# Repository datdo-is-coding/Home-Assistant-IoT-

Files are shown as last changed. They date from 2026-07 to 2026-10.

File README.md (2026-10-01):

# SIC — Home Assistant IoT

Code đang phát triển tập trung vào ba thành phần:

| Thư mục | Vai trò |
| --- | --- |
| `Gateway/` | Gateway Python, MQTT, xử lý giọng nói và Web UI |
| `Firmware/firmware_esp/ActionBox/` | Firmware thiết bị chấp hành ESP32-S3 |
| `Firmware/firmware_esp/SubBox/` | Firmware điều phối phòng, audio và NLU |

Các thư mục hỗ trợ được giữ lại:

- `MQTT_Server/`: broker Mosquitto và bộ dịch vụ Docker hiện có.
- `Firmware/firmware_esp/Audio_Hardware_Test/`: firmware kiểm tra phần cứng âm thanh.
- `Firmware/tools/` và các script test/visualizer: công cụ kiểm tra thiết bị.
- `Gateway/tests/`, `Gateway/benchmark/`, `Gateway/training_data/`: kiểm thử, đo hiệu năng và dữ liệu NLU.
- `Hardware/`, `sound/`, `apk/`, các firmware binary và tài liệu thiết kế: giữ nguyên.
- `archive/`: code cũ, có [bảng đường dẫn khôi phục](archive/README.md).

## Build firmware

Trên Windows có ESP-IDF 6.0.2, chạy từ thư mục gốc repo:

```powershell
.\Firmware\firmware_esp\ActionBox\build.ps1
.\Firmware\firmware_esp\SubBox\build.ps1
```

Script dùng profile `C:\Espressif\tools\Microsoft.v6.0.2.PowerShell_profile.ps1`.
Tham số `-Clean` thực hiện `fullclean` trước khi build. Các script build/flash
truyền đường dẫn project bằng `-C`, nên không phụ thuộc thư mục terminal hiện tại.
Nếu chạy trong terminal thiếu biến kiến trúc CPU và gặp lỗi `Windows-`, đặt biến
cho phiên terminal trước khi build:

```powershell
$env:PROCESSOR_ARCHITECTURE = [System.Runtime.InteropServices.RuntimeInformation]::OSArchitecture.ToString().Replace('X64', 'AMD64')
```

Nạp firmware khi đã chọn đúng board và cổng COM:

```powershell
.\Firmware\firmware_esp\ActionBox\flash.ps1 -Port COM9 -NoMonitor
.\Firmware\firmware_esp\SubBox\flash.ps1 -Port COM10 -NoMonitor
```

## Gateway

```powershell
python -m pip install -r Gateway/requirements.txt
python Gateway/gateway/main.py
```

Cấu hình nằm trong `Gateway/gateway/config.py`; dịch vụ Linux nằm trong
`Gateway/systemd/`. ASR/TTS local cần model và dependency riêng theo cấu hình.

Kiểm thử offline từ thư mục gốc, không điều khiển thiết bị thật:

```powershell
python Gateway/tests/test_intent_engine_v3.py
python Gateway/tests/test_runtime_utils.py
```

`test_clean_gateway.py` là script tích hợp có khởi tạo Gateway/registry, không nằm
trong bộ test offline trên. Chỉ chạy với cấu hình và dữ liệu thử nghiệm riêng.

## Tìm kiếm code

`.ignore` loại code archive và thư viện bên thứ ba khỏi tìm kiếm `rg` mặc định;
dùng `rg --no-ignore` khi cần tra cứu chúng. `.graphifyignore` giữ graph tập trung
vào code hiện hành. Các file archive vẫn có thể được quản lý bằng Git.

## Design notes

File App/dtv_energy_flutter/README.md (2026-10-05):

# SIC Home for Android

Flutter client for the Gateway in this repository. Includes account/API-key
login, room filters, favorites, relay control, telemetry/history, device pairing
and firmware management. Admin actions remain subject to Gateway authorization.
No simulated telemetry or local account registration is used.

## Connect

1. Connect the phone to the same trusted network as the Gateway.
2. Enter a reachable Gateway URL, normally `http://<gateway-ip>:8000`.
3. Sign in with an existing Gateway account or its API key.

The Pi at `192.168.11.29` was listening on **127.0.0.1:8000** when inspected on
2026-10-02. It is not yet reachable directly from a phone. Configure an
authenticated HTTPS reverse proxy, or deliberately enable LAN binding with
the Gateway's authentication and firewall intact. Do not expose port 8000 to
the public Internet. HTTP is supported for trusted LAN use, but does not encrypt
credentials in transit. Android session tokens are encrypted with AndroidKeyStore;
passwords are not saved and app backup is disabled.

Deploy the matching `Gateway/gateway/web_server.py` relay fix before testing
physical controls: the old handler misread the verifier's tuple result. The app
distinguishes a relay acknowledgement from verified electrical load. Offline
devices and unknown relay states cannot be toggled.

## Build And Verify

Use Flutter 3.44.8 / Dart 3.12.2, JDK 17 and Android SDK 36 (the versions verified
for this change):

```sh
flutter pub get
flutter analyze
flutter test
flutter build apk --debug
```

APK: `build/app/outputs/flutter-apk/app-debug.apk`.
This is a development build, not a production-signed Play Store release.
The repository's existing Gradle release configuration also uses the debug key;
configure your own signing key before distribution.

Widget tests exercise 360/390 px phone and 800 px tablet layouts, light/dark mode,
large text and offline controls. Screenshot baselines are in `test/goldens/`.
HTTP tests mock Gateway responses; no Android phone, AndroidKeyStore hardware,
real relay switching or firmware flashing was exercised by these tests.

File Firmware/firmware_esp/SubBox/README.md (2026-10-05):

# SubBox / SubGateway Firmware

## Current voice mode: Pi4 processing only

ActionBox captures 16 kHz mono PCM and sends it over ESP-NOW. SubBox forwards
the PCM over WebSocket with the originating ActionBox `node_id`,
`audio_relay: true`, and `asr_only: false`. Pi4 performs speech recognition,
intent extraction and device selection, then sends commands through
MQTT -> SubBox -> ActionBox. Audio sockets are not relay-command transports.

Local DummyASR/offline fallback and the SubBox voice NLU task are disabled.
Gateway transcripts are diagnostic only: they never trigger a second local
command. If the audio connection fails, no fallback command is generated.
ActionBox keeps energy VAD and push-to-talk for recording boundaries, with
WakeNet disabled; saying "Hi ESP" is no longer required.

Deploy the updated `Gateway/gateway/audio_server.py` and restart the Gateway,
then build/flash both ActionBox and SubBox. The WebSocket URI must point to the
Pi audio server (port 8765); the existing security configuration overrides the
default URI in `src/config/subbox_config.h`.

Offline checks from the repository root:

```sh
python3 -m unittest discover -s Gateway/tests -p test_audio_relay.py -v
python3 -m unittest discover -s Firmware/tests -p test_audio_relay.py -v
```

The older local-ASR/NLU architecture described below is historical and is not
the active microphone path.

Production-grade firmware for the **ESP32-S3 SubBox (SubGateway)** — the intelligent local room brain and distributed audio hub of the smart-home IoT ecosystem, built on **ESP-IDF 6.0.2** and **FreeRTOS** (PlatformIO compatible).

---

## 1. System Role & Architecture

```
ActionBox 1 (Mic, Spk, Relay, Current) ──┐
ActionBox 2 (Mic, Spk, Relay, Current) ──┤ UDP Audio:5005   ┌──────────────────────────────────────────────┐
ActionBox 3 (Mic, Spk, Relay, Current) ──┼─────────────────>│                   SubBox                     │
ActionBox 4 (Mic, Spk, Relay, Current) ──┘                  │                                              │
                                                            │ • Audio Manager (RMS & VAD arbitration)      │
ActionBox 1..4 Speakers <───────────────────────────────────┤ • Single-Stream ASR Pipeline (Replaceable)   │
                          UDP Audio:5006 (Targeted Downlink)│ • Vietnamese Text Normalizer                 │
                                                            │ • Local Deterministic NLU (Intent & Entity)  │
                                                            │ • Dialogue Context Manager ("tắt nó")       │
                                                            │ • Local Command Router & Rule Engine         │
                                                            │ • ActionBox State Registry                   │
                                                            └──────────────────────┬───────────────────────┘
                                                                                   │ MQTT (home/subbox/...)
                                                                                   ▼
                                                                        Raspberry Pi 4 / Cloud
                                                                  (Complex reasoning, LLM, historical)
```

### Key Architectural Tenets:
1. **No Direct Microphone on SubBox**: SubBox does **NOT** initialize an onboard I2S microphone driver. All audio input originates from ActionBox microphones transmitted over the network (UDP / ESP-NOW).
2. **Multi-ActionBox Arbitration**: Supports up to 4 ActionBoxes per room. Instead of running 4 concurrent ASR engines (which would overwhelm memory/compute), the **Audio Manager** tracks packet loss, RMS energy, and VAD state to dynamically route the single *best* active stream to the ASR engine.
3. **Targeted Voice Response**: Audio feedback / TTS is routed specifically to the ActionBox where the user spoke (`last_input_audio_node`), avoiding whole-room audio chaos.
4. **Local Independence**: Basic voice commands ("bật đèn", "tắt quạt", "nhiệt độ bao nhiêu") and local protection rules (overcurrent trips, automatic fan cooling) execute locally on SubBox without Raspberry Pi 4.
5. **Complex Intent Forwarding**: Multi-condition, temporal, or cross-room whole-house logic ("nếu nhiệt độ trên 30 độ thì bật quạt") is detected and forwarded to Raspberry Pi 4 via MQTT.

---

## 2. Directory Structure (Section 26 Compliance)

```
SubBox/
├── platformio.ini               # PlatformIO 16MB Flash + PSRAM environment
├── CMakeLists.txt               # ESP-IDF 6.0.2 / 5.5 top-level project CMake
├── partitions.csv               # 16MB partition map (NVS, OTA0/1, Model, Storage)
├── sdkconfig.defaults           # 240MHz, 16MB Flash DIO, 16MB Octal PSRAM
├── build.ps1                    # One-click native ESP-IDF build script
├── flash.ps1                    # One-click flash & monitor script
└── src/
    ├── main.cpp                 # Firmware entry point & subsystem assembly
    ├── CMakeLists.txt           # Component registration & dependencies
    │
    ├── config/
    │   ├── subbox_config.h      # Network ports, buffer sizes, FreeRTOS priorities
    │   └── board_pins.h         # GPIO definitions (LEDs, buttons, relays; NO MIC)
    │
    ├── audio/
    │   ├── audio_transport/     # Abstract transport + UDP implementation
    │   │   ├── audio_packet.h   # Universal audio protocol packet struct
    │   │   ├── audio_transport.h
    │   │   └── udp_audio_transport.h / .cpp
    │   ├── audio_buffer/        # Circular audio ring buffer (PSRAM supported)
    │   │   └── audio_ring_buffer.h / .cpp
    │   ├── vad/                 # Adaptive energy-based Voice Activity Detection
    │   │   ├── vad_interface.h
    │   │   └── energy_vad.h / .cpp
    │   ├── asr/                 # Replaceable Vietnamese ASR abstraction + DummyASR
    │   │   ├── asr_engine.h
    │   │   └── dummy_asr.h / .cpp
    │   ├── audio_manager/       # Multi-stream arbitrator & ASR feeder
    │   │   └── audio_manager.h / .cpp
    │   └── audio_output/        # Targeted downlink router to ActionBox speakers
    │       └── audio_output_router.h / .cpp
    │
    ├── nlu/
    │   ├── normalizer/          # Vietnamese diacritics & text cleaner
    │   │   └── vietnamese_normalizer.h / .cpp
    │   ├── intent/              # Deterministic intent parser & complex detector
    │   │   ├── intent_types.h
    │   │   └── intent_parser.h / .cpp
    │   ├── entity/              # Device, Room, Value extraction
    │   │   ├── entity_types.h
    │   │   └── entity_extractor.h / .cpp
    │   └── context/             # Speaker vs Target room, pronoun resolution ("nó")
    │       └── context_manager.h / .cpp
    │
    ├── actionbox/
    │   ├── registry/            # ActionBox node status, capabilities & telemetry
    │   │   └── actionbox_registry.h / .cpp
    │   ├── protocol/            # JSON command serializer
    │   │   └── actionbox_network_protocol.h
    │   └── router/              # Command execution (Local, Cross-Room, Pi4)
    │       └── command_router.h / .cpp
    │
    ├── room/                    # Local room identity & configuration
    │   └── room_manager.h / .cpp
    ├── rules/                   # Edge rule engine (overcurrent, thermal thresholds)
    │   └── rule_engine.h / .cpp
    ├── tts/                     # TTS interface, chime generator & Pi4 audio relay
    │   ├── tts_engine.h
    │   └── tts_manager.h / .cpp
    ├── mqtt/                    # ESP-IDF MQTT client for Pi4 integration
    │   └── mqtt_client.h / .cpp
    ├── storage/                 # NVS persistent configuration
    │   └── nvs_manager.h / .cpp
    └── system/                  # FreeRTOS Task Manager & Interactive Dev Console
        ├── task_manager.h / .cpp
        └── dev_console.h / .cpp
```

---

## 3. Audio & Data Pipeline

```
 [ActionBox Mic]
       │ (16kHz, 16-bit Mono PCM, 20ms frames)
       ▼ UDP:5005
 [audio_rx_task]
       │
       ▼
 [audio_mgr_task] ──> [energy_vad per node] ──> Best Source Selection
       │
       ▼ (Active Speech Frames)
 [asr_task] ──> ASREngine (DummyASR / TinyML Vietnamese ASR)
       │
       ▼ (Recognized Vietnamese Text)
 [nlu_task]
       ├── Vietnamese Normalizer (lowercase, tone marks, synonym collapse)
       ├── Intent Parser (TURN_ON, TURN_OFF, TOGGLE, SET_TEMPERATURE, COMPLEX)
       ├── Entity Extractor (Device: LIGHT, FAN; Room: BEDROOM; Values: 26°C)
       └── Context Manager (Speaker Room vs Target Room; pronoun "nó" resolution)
       │
       ▼
 [cmd_router_task]
       ├── Local Room ActionBox? ─────────> Dispatch UDP command to ActionBox relay
       ├── Other Room SubBox?    ─────────> Dispatch via Inter-SubBox MQTT
       └── Complex Sentence?     ─────────> Forward to Pi4 (`home/subbox/ID/voice/request`)
       │
       ▼
 [tts_manager] ──> Audio Output Router ──> UDP:5006 ──> [Target ActionBox Speaker]
```

---

## 4. FreeRTOS Task & Core Architecture

| Task Name | Core | Priority | Stack (Bytes) | Role |
| :--- | :---: | :---: | :---: | :--- |
| `audio_rx_task` | 1 | 9 | 4,096 | High-speed UDP receiver for incoming microphone packets |
| `audio_mgr_task`| 1 | 8 | 4,096 | Multi-stream tracking, VAD processing, arbitrator |
| `vad_task` | 1 | 7 | 4,096 | Frame-level energy calculation & onset/offset tracking |
| `asr_task` | 1 | 6 | 8,192 | Speech-to-text inference (INT8 PSRAM model or Dummy) |
| `nlu_task` | 0 | 5 | 6,144 | UTF-8 normalization, intent parsing, entity/context resolution |
| `cmd_router_task`| 0 | 5 | 4,096 | Command routing, safety check, rule evaluation |
| `audio_tx_task` | 1 | 8 | 4,096 | Transmits audio feedback/chimes to target ActionBox speaker |
| `mqtt_task` | 0 | 4 | 6,144 | Bi-directional communication with Raspberry Pi 4 |
| `telemetry_task`| 0 | 2 | 3,072 | Node heartbeat, registry health & current watchdog |
| `dev_cli_task`  | 0 | 3 | 4,096 | UART/USB-JTAG interactive development console |

---

## 5. Development Console (CLI)

The firmware includes an interactive CLI over Native USB Serial / UART at 115200 baud for testing the complete pipeline without hardware audio:

### Commands:

1. **`CMD <text>`**: Directly injects a command into the NLU pipeline:
   ```bash
   CMD bật đèn phòng ngủ
   CMD tắt quạt
   CMD tắt nó
   CMD nếu nhiệt độ trên 30 độ thì bật quạt
   ```
2. **`SAY <text>`**: Simulates an ASR recognition event:
   ```bash
   SAY bật đèn
   SAY tăng nhiệt độ điều hòa phòng khách
   ```
3. **`TEST_NLU`**: Executes the comprehensive built-in unit test suite verifying:
   - Simple local commands (`bật đèn` -> local room light ON)
   - Cross-room commands (`bật đèn phòng bếp` -> kitchen light ON)
   - Device aliases (`máy lạnh` -> `AIR_CONDITIONER`)
   - Context reference resolution (`tắt nó` after `bật quạt` -> turn off fan)
   - Complex conditional sentences (`nếu trời mưa...` -> forwarded to Pi4)
4. **`STATUS`**: Dumps system uptime, free internal RAM, free PSRAM, Wi-Fi status, and registered ActionBoxes.
5. **`REG <id> <room> <device>`**: Manually registers an ActionBox for test routing:
   ```bash
   REG AB001 BEDROOM LIGHT
   ```
6. **`TOPIC <payload>`**: Publishes an event to Pi4 MQTT broker.

---

## 6. MQTT Topics (Raspberry Pi 4 Integration)

| Topic | Direction | Payload Example / Description |
| :--- | :---: | :--- |
| `home/subbox/{id}/state` | SubBox $\rightarrow$ Pi4 | `{"status":"online","room":"BEDROOM","free_heap":...}` |
| `home/subbox/{id}/event` | SubBox $\rightarrow$ Pi4 | `{"event":"overcurrent_trip","node":"AB001","current":16.2}` |
| `home/subbox/{id}/command` | Pi4 $\rightarrow$ SubBox | External commands issued by Home Assistant or Pi4 |
| `home/subbox/{id}/voice/request` | SubBox $\rightarrow$ Pi4 | Forwarded complex intents requiring LLM / reasoning |
| `home/subbox/{id}/voice/response` | Pi4 $\rightarrow$ SubBox | Pi4 response text / synthesized TTS audio metadata |

---

## 7. Build and Flash Instructions

### Prerequisites:
- **ESP-IDF v6.0.2** or **ESP-IDF v5.5** installed.
- Target hardware: ESP32-S3 (WROOM-1 / WROOM-2 N16R8 / N16R2).

### Option A: Using PowerShell Scripts (ESP-IDF 6.0.2)
```powershell
cd Firmware/firmware_esp/SubBox

# 1. Clean & Build
.\build.ps1 -Clean

# 2. Flash to COM port & open Monitor (default COM9)
.\flash.ps1 -Port COM9
```

### Option B: Using Native ESP-IDF CLI
```bash
idf.py set-target esp32s3
idf.py build
idf.py -p COM9 flash monitor
```

### Option C: Using PlatformIO
```bash
pio run -e esp32s3_subbox
pio run -e esp32s3_subbox -t upload --upload-port COM9
pio device monitor -b 115200
```

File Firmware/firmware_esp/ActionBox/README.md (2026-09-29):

# ActionBox Firmware — ESP32-S3 Smart-Home Actuator Node

Production-grade embedded C++ firmware for the **ActionBox** actuator node running on ESP32-S3, ESP-IDF 6.0.2 / FreeRTOS, and PlatformIO.

---

## 1. Hardware Role & Philosophy

The ActionBox is a low-level, high-reliability actuator and sensor node.

* **It is NOT an AI device.**
* **It does NOT run an LLM.**
* **It does NOT perform speech recognition or audio capture.**
* **It does NOT interpret natural language or execute high-level automations.**

### Primary Responsibilities:
1. **Relay Control**: Safely drives 2 isolated relay channels (monostable or magnetic-latching).
2. **Current & Power Sensing**: Interrogates dual Belling BL0942 energy measurement ICs over UART.
3. **Physical Buttons**: Debounces local push buttons with short-press toggle and long-press reset.
4. **State Reporting & Idempotency**: Reports channel states and telemetries via a cached idempotent JSON protocol.
5. **Safety Supervisor**: Autonomous, local overcurrent cutoff and fault isolation without network dependency.
6. **Robust Network Resilience**: Communicates primarily with its assigned SubBox over ESP-NOW, continuing 100% full local operation when network or SubBox is offline.

---

## 2. Hardware Pinout (`IoT_Board.kicad_sch`)

Directly traced from schematic `D:\Downloads\IoT_Board.kicad_sch`:

| Function | Schematic Net | ESP32-S3 GPIO | Electrical Interface | Description |
| :--- | :--- | :--- | :--- | :--- |
| **Relay Channel 1** | `RL1` | **GPIO 4** | Optocoupler PC817 (U5) | Relay 1 (K1) drive |
| **Relay Channel 2** | `RL2` | **GPIO 5** | Optocoupler PC817 (U6) | Relay 2 (K2) drive |
| **Button Channel 1**| `BUT1` | **GPIO 1** | Internal Pull-Up to 3.3V | Local Push Button 1 |
| **Button Channel 2**| `BUT2` | **GPIO 3** | Internal Pull-Up to 3.3V | Local Push Button 2 |
| **Status LED 1** | `LED1` | **GPIO 48** | Series Resistor to GND | Channel 1 Indicator LED |
| **Status LED 2** | `LED2` | **GPIO 47** | Series Resistor to GND | Channel 2 Indicator LED |
| **BL0942 TX** | `BL_TX` | **GPIO 9** | UART TX (Shared) | Broadcast query to BL0942 #1 & #2 |
| **BL0942 RX Ch1** | `BL_RX1` | **GPIO 10** | UART1 RX | Ch1 BL0942 (#1) Response Stream |
| **BL0942 RX Ch2** | `BL_RX2` | **GPIO 11** | UART2 RX | Ch2 BL0942 (#2) Response Stream |
| **Speaker SD (Mute)**| `SP_SD` | **GPIO 2** | Hardware Shutdown Pin | **Cố định mức LOW** -> Tắt hẳn IC MAX98357 |
| **Speaker I2S (BCLK/LRC/DOUT)**| `SP_*` | **GPIO 17, 18, 21**| I2S Tri-state Pull-down | Chân âm thanh đặt ở trạng thái cô lập, tiêu thụ 0W |
| **USB D-** | `USB_D-` | **GPIO 19** | Native USB | USB Serial / JTAG Console |
| **USB D+** | `USB_D+` | **GPIO 20** | Native USB | USB Serial / JTAG Console |
| **Debug TX0** | `TX0` | **GPIO 43** | UART0 TX | Hardware Debug Terminal |
| **Debug RX0** | `RX0` | **GPIO 44** | UART0 RX | Hardware Debug Terminal |

---

## 3. Project Architecture

```
ActionBox/
├── platformio.ini                 # PlatformIO configuration (esp32-s3-devkitc-1, 16MB)
├── CMakeLists.txt                 # ESP-IDF Root Project CMake
├── partitions.csv                 # 16MB Partition Table (nvs, otadata, ota_0, ota_1)
├── sdkconfig.defaults             # Hardware configuration defaults
├── src/
│   ├── CMakeLists.txt             # Component registration & dependency mapping
│   ├── main.cpp                   # Application entry point & banner
│   ├── config/
│   │   ├── board_pins.h           # Hardware GPIO mapping from schematic
│   │   └── app_config.h           # Timing, limits, queue capacities & task priorities
│   ├── drivers/
│   │   ├── relay/
│   │   │   ├── relay_driver.h     # Relay driver interface (monostable & latching)
│   │   │   └── relay_driver.cpp   # Staggered inrush delay & thread-safe actuation
│   │   ├── current_sensor/
│   │   │   ├── current_sensor.h   # Abstract current measurement interface
│   │   │   ├── bl0942.h           # BL0942 driver header
│   │   │   └── bl0942.cpp         # Dual-UART BL0942 parsing & calibration
│   │   ├── button/
│   │   │   ├── button_driver.h    # Button driver header
│   │   │   └── button_driver.cpp  # Non-blocking debounce & long-press detection
│   │   └── led/
│   │       ├── led_driver.h       # Status LED pattern header
│   │       └── led_driver.cpp     # Visual pattern generator (steady, blink, pulse)
│   ├── protocol/
│   │   ├── actionbox_protocol.h   # JSON schema, commands & responses
│   │   └── actionbox_protocol.cpp # cJSON parsing & 32-entry idempotency cache
│   ├── network/
│   │   ├── espnow_transport.h     # ESP-NOW transport header
│   │   └── espnow_transport.cpp   # Station Wi-Fi & unicast/broadcast transport
│   ├── device/
│   │   ├── device_manager.h       # Coordinator header
│   │   └── device_manager.cpp     # Command dispatch, button events & LED sync
│   ├── safety/
│   │   ├── safety_supervisor.h    # Safety supervisor header
│   │   └── safety_supervisor.cpp  # Local overcurrent trip & TWDT watchdog
│   ├── storage/
│   │   ├── nvs_storage.h          # NVS persistent configuration header
│   │   └── nvs_storage.cpp        # Flash-wear-protected NVS storage
│   └── system/
│       ├── task_manager.h         # FreeRTOS task & queue definitions
│       └── task_manager.cpp       # Core task loops & queue orchestration
└── tools/
    └── test_actionbox.py          # Python test CLI & automated verification suite
```

---

## 4. FreeRTOS Task Architecture

The ActionBox organizes its concurrency into discrete FreeRTOS tasks communicating via queues and semaphores:

| Task Name | Priority | Stack | Function |
| :--- | :--- | :--- | :--- |
| `safety_task` | `MAX-1` (Highest) | 4 KB | Blocks on sensor queue. Evaluates overcurrent limits instantly; trips relays and dispatches urgent alerts. Feeds TWDT. |
| `relay_task` | `MAX-2` | 4 KB | Consumes command queue; manages inrush stagger delay and coil pulse timing. |
| `button_task` | `MAX-3` | 3 KB | Ticks button state machine every 10ms for non-blocking debounce and long-press gestures. |
| `sensor_task` | `MAX-4` | 4 KB | Interrogates dual BL0942 UART channels every 100ms; posts valid measurements to `sensor_queue`. |
| `network_task`| `MAX-5` | 5 KB | Processes incoming ESP-NOW packets from SubBox, validates idempotency cache, dispatches commands, and sends responses. |
| `telemetry_task`| `IDLE+2` | 3 KB | Broadcasts periodic JSON telemetry every 1000ms; monitors SubBox heartbeat timeout; ticks LED animations. |

---

## 5. Relay Control & Magnetic Latching

* **Monostable Mode** (`BOARD_RELAY_DRIVE_TYPE == BOARD_RELAY_TYPE_MONOSTABLE`):
  * Continuous HIGH energizes optocoupler (Relay Closed/ON).
  * Continuous LOW de-energizes optocoupler (Relay Open/OFF).
* **Magnetic Latching Mode** (`BOARD_RELAY_DRIVE_TYPE == BOARD_RELAY_TYPE_LATCHING_DUAL`):
  * `SET` pulse (50ms) closes contact, then releases coil to 0 immediately.
  * `RESET` pulse (50ms) opens contact, then releases coil to 0 immediately.
  * **Never holds coil continuously energized**, eliminating thermal dissipation and saving power.

---

## 6. Safety & Overcurrent Protection

* **Autonomous Protection**: Runs locally in `safety_task`. Does **not** rely on SubBox, Wi-Fi, or Raspberry Pi.
* **Overcurrent Trip**:
  * Default threshold: `10000 mA` (10A RMS).
  * Inrush Debounce: Must persist > `300 ms` to prevent false tripping on capacitive/motor inrush.
  * Hard Ceiling Trip: Instantaneous cutoff if current exceeds `16000 mA` (16A).
* **Post-Trip Isolation**:
  * Relay is forced OFF immediately.
  * Channel is locked in `RELAY_FAULT_OVERCURRENT`.
  * Status LED blinks rapidly (5 Hz).
  * Urgent alert packet is sent to SubBox.
  * **No automatic re-engagement** is permitted until an explicit `CLEAR_FAULT` command is issued.

---

## 7. Communication Protocol

### Command Format (SubBox -> ActionBox)
```json
{
  "version": 1,
  "node_id": "AB001",
  "request_id": 1042,
  "cmd": "TURN_ON",
  "channel": 1,
  "timestamp": 1727400000
}
```

### Response Format (ActionBox -> SubBox)
```json
{
  "version": 1,
  "node_id": "AB001",
  "request_id": 1042,
  "status": "OK",
  "channel": 1,
  "state": "ON",
  "uptime_s": 42
}
```

### Supported Commands
* `TURN_ON`: Turn on relay for specified channel (1 or 2).
* `TURN_OFF`: Turn off relay for specified channel.
* `TOGGLE`: Toggle relay state.
* `GET_STATE`: Query relay contact and fault state.
* `GET_CURRENT`: Query instantaneous RMS current and voltage from BL0942.
* `GET_POWER`: Query active power (W) and accumulated energy (Wh).
* `CLEAR_FAULT`: Clears an active safety fault and re-enables channel control.
* `PING`: Heartbeat probe (replies with `state: "PONG"`).
* `SET_CONFIG`: Remotely update `node_id`, `room_id`, or `max_current_ma`.

### Idempotency
A 32-entry ring buffer tracks recent `request_id`s and their exact serialized response. If the SubBox re-transmits a command due to packet loss, the ActionBox returns the cached response without re-triggering relays or double-toggling.

---

## 8. Build, Flash & Monitor Instructions

### Option A: Using ESP-IDF 6.0.2 (Native PowerShell)

Activate the ESP-IDF 6.0.2 environment:
```powershell
& 'C:\Espressif\tools\Microsoft.v6.0.2.PowerShell_profile.ps1'
```

Navigate to the project root:
```powershell
cd d:\Home-Assistant-IoT-\Firmware\firmware_esp\ActionBox
```

Build:
```powershell
idf.py build
```

Flash (e.g. on `COM8`):
```powershell
idf.py -p COM8 flash
```

Monitor:
```powershell
idf.py -p COM8 monitor
```

*(Or simply use the included one-click helper scripts `./build.ps1` and `./flash.ps1`)*

### Option B: Using PlatformIO

Build:
```bash
pio run
```

Upload:
```bash
pio run --target upload --upload-port COM8
```

Monitor:
```bash
pio device monitor --port COM8 --baud 115200
```

---

## 9. Testing & Automated Verification

A complete Python test suite is provided in `tools/test_actionbox.py`.

Run the automated verification suite over Serial:
```bash
python tools/test_actionbox.py --port COM8 --test
```

Send individual commands:
```bash
# Toggle Relay 1
python tools/test_actionbox.py --port COM8 --cmd TOGGLE --ch 1

# Query Current
python tools/test_actionbox.py --port COM8 --cmd GET_CURRENT --ch 1

# Clear Fault
python tools/test_actionbox.py --port COM8 --cmd CLEAR_FAULT --ch 1
```

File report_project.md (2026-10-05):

# Home Assistant IoT Project Report

## Project Overview

This is a comprehensive IoT energy monitoring system that integrates hardware sensing, voice interaction, MQTT messaging, database storage, and web visualization for energy consumption monitoring. The system is built using ESP32-S3 microcontrollers, MQTT broker, PostgreSQL database, and containerized deployment with Docker Compose.

## System Architecture

### Hardware Component
- **ESP32-S3 Microcontroller**: Main IoT device with:
  - Sensor hardware for measuring electrical parameters (voltage, current, power, energy, power factor, frequency)
  - Voice assistant capabilities using ESP-SR (ESP-Speech Recognition) library
  - RGB LED indicators for system status visualization
  - I2S microphone and speaker for voice interaction
  - Voice control activation with "Hi ESP" command

### Software Components

#### 1. MQTT Server & Database
- **MQTT Broker**: Eclipse Mosquitto running in Docker container (port 1883)
- **Database**: PostgreSQL (port 5432) with Adminer web interface (port 8080)
- **Data Subscriber**: Python service that receives MQTT messages and writes to database

#### 2. Firmware
- **ESP32-S3 Firmware**: Built with PlatformIO using ESP-IDF framework
- **Voice Recognition**: Uses ESP-SR library for wake-word detection
- **Audio Processing**: I2S microphone and DAC for voice interaction
- **Sensor Data Collection**: Measures and reports electrical parameters

### Data Flow
1. **Sensor Data Collection**: ESP32-S3 measures electrical parameters
2. **MQTT Publishing**: Data is published to MQTT broker with topic `esp32/sensor/data`
3. **Data Processing**: Subscriber service receives MQTT messages
4. **Database Storage**: Processed data is saved to PostgreSQL database in `sensor_logs` table
5. **Data Visualization**: Adminer web interface allows viewing of real-time data

## Technical Details

### ESP32 Firmware
- **Platform**: ESP32-S3 N16R8 with ESP-IDF framework
- **Configuration**: Uses 4D Systems ESP32-S3 Gen4 R8N16 board
- **Memory**: 16MB flash with PSRAM support
- **Audio Features**:
  - Microphone: INMP441 MEMS Mic (I2S interface)
  - Speaker/DAC: MAX98357A I2S DAC/AMP
  - Voice recognition: ESP-SR wake-word detection
- **LED Control**: RMT-based WS2812 RGB LED driver on GPIO 48

### MQTT Configuration
- **Broker**: Eclipse Mosquitto
- **Port**: 1883 (standard MQTT port)
- **Topic**: `esp32/sensor/data`
- **Server IP**: 192.168.41.101

### Database Schema
- **Table**: `sensor_logs`
- **Columns**: 
  - `id`: Auto-incrementing primary key
  - `device_id`: Device identifier
  - `voltage`: NUMERIC(6,2) - Voltage in volts
  - `current`: NUMERIC(6,2) - Current in amperes
  - `power`: NUMERIC(8,2) - Power in watts
  - `energy`: NUMERIC(10,2) - Energy in watt-hours
  - `power_factor`: NUMERIC(4,2) - Power factor
  - `frequency`: NUMERIC(5,2) - Frequency in hertz
  - `created_at`: Timestamp with timezone

### Docker Compose Services
1. **iot_mosquitto**: MQTT broker service
2. **iot_postgres**: PostgreSQL database service
3. **iot_adminer**: Web database interface (port 8080)
4. **iot_subscriber**: MQTT data receiver and database writer

## Deployment & Operation

### System Operation
- **Start Server**: `docker compose up -d`
- **Check Status**: `docker compose ps`
- **View Logs**: `docker logs -f iot_subscriber`
- **Stop Server**: `docker compose down`

### Web Interface
- **Adminer Access**: http://localhost:8080
- **Database Login**:
  - System: PostgreSQL
  - Server: postgres
  - Username: iot_user
  - Password: iot_password
  - Database: iot_db

## Key Features

1. **Voice Control**: System can be activated with "Hi ESP" command
2. **Real-time Monitoring**: Live telemetry data via MQTT
3. **Web Dashboard**: Adminer interface for database access
4. **Containerized Deployment**: All services run in Docker containers
5. **Extensible Design**: Database schema supports additional columns for expanding functionality

## Configuration Parameters

### ESP32 Firmware Settings
- **MQTT Server IP**: 192.168.41.101
- **MQTT Port**: 1883
- **MQTT Topic**: `esp32/sensor/data`
- **Sensor Data Format**:
  ```json
  {
    "device_id": "ESP32_Energy_Monitor",
    "voltage": 225.40,
    "current": 1.35,
    "power": 298.20,
    "energy": 1925.10,
    "power_factor": 0.98,
    "frequency": 50.00
  }
  ```

## System Integration

This system is designed to integrate with the Home Assistant ecosystem, providing a complete IoT solution for energy monitoring with voice control capabilities. The modular design allows for easy expansion and integration with other smart home systems.

## Conclusion

The Home Assistant IoT project presents a robust, scalable solution for energy monitoring that combines hardware sensing, voice interaction, cloud messaging, and web visualization in a containerized environment. The system is well-documented and follows modern IoT architecture principles with clear separation of concerns between hardware, firmware, messaging, and data storage components.

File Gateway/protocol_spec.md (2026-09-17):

# Khung dữ liệu Gateway ↔ ESP32 — Nhẹ nhất, đầy đủ, dùng chung WebSocket audio

> Nguyên tắc: **đường PCM nhị phân giữ nguyên 100%** (không nhét control byte vào PCM).
> Điều khiển relay đi bằng **WebSocket TEXT frame (opcode 0x1)** xen kẽ giữa các BINARY frame —
> TCP/WS cho phép xen kẽ nên không nghẽn, không vỡ luồng mic đang chạy ổn định.
> Node không có WS (node relay thuần) dùng MQTT với cùng cấu trúc rút gọn.

## 1. Quy ước đặt tên (bắt buộc để chống ảo giác LLM)

```
fullname = {room}-{node_short}-{dev_short}
ví dụ: livingroom-node01-light | livingroom-node01-fan
       bedroom-node01-light    | bedroom-node01-fan
```

- `room`: slug không dấu: `livingroom | bedroom | kitchen | ...` (+ alias tiếng Việt).
- `node_short`: `node01 | node02 | master` (duy nhất trong room).
- `node_id`: `livingroom-node01` (= room + node_short). Là MQTT topic + WS id.
- `dev_short`: `light | fan | pump | ...` (1 từ, không dấu).
- ESP32 **phải nhớ** `rl1_name / rl2_name` trong NVS và **echo lại** mỗi lần hello/status.
  Gateway là source-of-truth, nhưng bản echo giúp phát hiện lệch cấu hình (`cfg_version`).

## 2. Tổng quan 3 kênh (chọn theo loại node)

| Node | Kênh điều khiển chính | Kênh fallback | Telemetry |
|---|---|---|---|
| Voice node (ESP32-S3, đã giữ WS audio 8765) | **WS TEXT** `{"t":"rl",...}` (~25 byte) | MQTT `smarthome/cmd/{node_id}` | MQTT `smarthome/tele/{node_id}` |
| Relay node thuần (ESP32/WROOM) | MQTT `smarthome/cmd/{node_id}` | — | MQTT + ESP-NOW nội bộ |

## 3. ESP32 → Gateway

### 3.1. HELLO (khi boot + mỗi 60s, WS TEXT hoặc MQTT `smarthome/hello`)

Chưa provision (node mới → Gateway đẩy vào hàng chờ WebUI):

```json
{"t":"hello","mac":"30:ED:A0:BD:69:D4","fw":"1.2.0","ip":"192.168.11.181","rssi":-62,"rl":[0,0],"cfg":null}
```

Đã provision (nhẹ, ~110 byte):

```json
{"t":"hello","id":"livingroom-node01","rl":[0,1],"cfg":3,"rssi":-62,"up":12345}
```

`cfg` = config_version do Gateway cấp. `cfg:null` = node mới.
`rl` = trạng thái thực tế GPIO [RL1, RL2] để Gateway đồng bộ UI ngay.

### 3.2. ACK / STATUS (sau khi thực thi lệnh, WS TEXT hoặc `smarthome/status/{node_id}`)

```json
{"t":"ack","id":"livingroom-node01","rl":[1,0],"seq":12}
```

`seq` echo lại lệnh để verify vòng kín + trừ trùng lệnh.

### 3.3. TELEMETRY (MQTT `smarthome/tele/{node_id}`, 2s/lần, key rút gọn)

```json
{"p":55.2,"v":221.5,"i":0.25,"e":1.203,"f":50.0,"pf":0.92}
```

p=P(W), v=V, i=A, e=kWh, f=Hz, pf=cosφ. Node không có PZEM gửi `{}`.

## 4. Gateway → ESP32

### 4.1. PROVISION / CẤU HÌNH (WS TEXT hoặc MQTT `smarthome/cfg/{mac}`, QoS1 + retain)

WebUI đăng ký xong → Gateway gửi 1 lần, node lưu NVS + reboot mềm:

```json
{"t":"cfg","id":"livingroom-node01","room":"livingroom","rl1":"light","rl2":"fan","v":3}
```

~75 byte. `v` = config_version, node lưu và gửi lại trong hello sau này.
Tên đầy đủ suy ra: `livingroom-node01-light`, `livingroom-node01-fan`.

### 4.2. RELAY CMD (WS TEXT trực tiếp trên socket audio, hoặc MQTT `smarthome/cmd/{node_id}`)

```json
{"t":"rl","ch":1,"s":1,"seq":12}
```

- `ch`: 1 | 2 (RL1/RL2). Không gửi tên string để nhẹ + tránh sai chính tả.
- `s`: 1=ON (kéo Active-LOW trong firmware), 0=OFF.
- `seq`: tăng đơn điệu, node bỏ qua seq trùng/lùi (chống lặp MQTT retain).
- Tổng **~27 byte** — rẻ hơn 1 frame PCM 640 byte ~24 lần, không ảnh hưởng audio.

Bản đầy đủ cho debug/log (gateway tự expand, không gửi xuống node):

```json
{"node_id":"livingroom-node01","fullname":"livingroom-node01-fan","channel":"ch2","gpio":5,"action":"turn_on"}
```

### 4.3. TTS AUDIO (giữ nguyên, không đổi)

```
Pi → ESP32 TEXT {"type":"audio_start","format":"pcm","sample_rate":16000,"size":N}
Pi → ESP32 BINARY [2048 byte PCM] ... sleep 35ms
Pi → ESP32 TEXT {"type":"audio_end"}
```

Relay TEXT frame được phép xen giữa các BINARY chunk — ESP32 phân biệt bằng opcode nên loa không rè.

## 5. Ví dụ round-trip hoàn chỉnh

```
1. Node mới boot → WS TEXT {"t":"hello","mac":"AA:..","cfg":null,...}
2. Gateway → WebUI SSE `pending_node` → user nhập: room=bedroom, RL1=light, RL2=fan
3. Gateway → node {"t":"cfg","id":"bedroom-node01","room":"bedroom","rl1":"light","rl2":"fan","v":1}
4. Node lưu NVS → reboot → hello {"t":"hello","id":"bedroom-node01","rl":[0,0],"cfg":1}
5. User nói "bật quạt phòng khách" → ASR → LLM {action:on, device:fan, room:livingroom}
   → resolver livingroom-node01/ch2 → WS {"t":"rl","ch":2,"s":1,"seq":7}
6. Node kéo GPIO5 LOW → {"t":"ack","id":"livingroom-node01","rl":[0,1],"seq":7}
7. Gateway verify ΔP + phát TTS "Đã bật quạt phòng khách ạ."
```

## 6. Vì sao không tách socket riêng?

- ESP32-S3 chỉ giữ 1 TLS/TCP WS ổn định tới Pi4:8765. Mở thêm socket = thêm RAM, thêm reconnect race.
- TEXT frame điều khiển <30 byte, tần suất thấp (vài giây/lần), PCM 640 byte/20ms chiếm băng thông chính — xen 1 TEXT frame không gây jitter đo được.
- Node relay thuần không có WS vẫn chạy MQTT song song, cùng schema rút gọn.

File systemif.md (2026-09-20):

# DTV Smart Home & Energy IoT Hub — Tài Liệu Kiến Trúc & Thông Tin Hệ Thống Toàn Diện

> **Tài liệu cấu hình và hiện trạng kỹ thuật hệ thống**  
> **Dự án:** Hệ Thống Nhà Thông Minh Điều Khiển Giọng Nói Tiếng Việt & Giám Sát Năng Lượng Thông Minh Vòng Lặp Kín (Closed-Loop IoT).  
> **Cập nhật:** Ngày 17 tháng 09 năm 2026.

---

## 1. Tổng Quan Kiến Trúc Hệ Thống (System Overview)

Hệ thống được thiết kế theo mô hình **Điện toán phân tán (Edge-to-Gateway Computing)** kết hợp giữa vi điều khiển nhúng thời gian thực và máy chủ biên xử lý Trí tuệ Nhân tạo cục bộ (Local AI Edge Gateway).

```
   ┌────────────────────────────────────────────────────────┐
   │         ESP32 WROOM Energy Slave (PZEM-004T)           │
   │  - Đo V, I, P, E, Freq, PF lưới điện AC 220V           │
   └───────────────────────────┬────────────────────────────┘
                               │ ESP-NOW (Không dây ~1ms)
                               ▼
   ┌────────────────────────────────────────────────────────┐
   │            ESP32-S3 Voice Master & Relay Hub           │
   │  - WakeNet "Hi ESP" (ESP-SR Offline)                   │
   │  - Mic INMP441 + Loa MAX98357A (I2S DMA)               │
   │  - 2-CH Relay Active-LOW (GPIO 4: Đèn, GPIO 5: Quạt)   │
   │  - Bộ tổng hợp âm báo Sine Synthesizer (Chime, Ding)   │
   │  - Mô hình TinyML AI phân tích bất thường sóng tải     │
   └───────────────▲────────────────────────▲───────────────┘
                   │                        │
       WebSocket   │ Audio Stream (16kHz)   │ MQTT (Control & Telemetry)
       Port 8765   │ Chunks / PCM           │ Port 1883 (EMQX)
                   ▼                        ▼
   ┌────────────────────────────────────────────────────────┐
   │       Raspberry Pi 4 Gateway (192.168.11.29)           │
   │  - ASR Engine: Sherpa-ONNX (Zipformer Transducer VN)   │
   │  - LLM Engine: llama-server + Qwen2.5-3B-Instruct      │
   │  - TTS Engine: Microsoft EdgeTTS (Hoài My Neural)      │
   │  - Closed-Loop Verifier: Xác thực biến thiên công suất │
   │  - 3-Tier Memory Engine: SQLite (Học mẫu thói quen)    │
   │  - Time-series DB: InfluxDB v2 (Đồ thị năng lượng)     │
   │  - Web Monitor Dashboard: Port 8000 (SSE Realtime)     │
   └────────────────────────────────────────────────────────┘
```

---

## 2. Phần Cứng & Sơ Đồ Đấu Nối Chi Tiết (Hardware Specifications)

### 2.1. ESP32-S3 Voice Master Node
* **Vi điều khiển:** ESP32-S3-WROOM-1 / ESP32-S3 N16R8 (16MB Flash, 8MB Octal PSRAM).
* **Địa chỉ MAC Wi-Fi STA:** `30:ED:A0:BD:69:D4`.
* **Địa chỉ IP mạng nội bộ:** `192.168.11.181` (SSID: `XIAOMI`).

#### Bảng Ánh Xạ Chân GPIO (Pinout Mapping):
| Chức năng | Chân GPIO | Chuẩn giao tiếp | Chi tiết đấu nối phần cứng |
| :--- | :--- | :--- | :--- |
| **Microphone INMP441** | **GPIO 15** | I2S0 BCLK | Bit Clock |
| | **GPIO 16** | I2S0 WS / LRC | Word Select (Left/Right Clock) |
| | **GPIO 8** | I2S0 DIN / SD | Serial Data IN (chuyển đổi 24-bit $\rightarrow$ 16-bit) |
| | *GND / 3.3V* | L/R Pin | Chọn kênh Trái (Left Channel) |
| **Speaker MAX98357A** | **GPIO 17** | I2S1 BCLK | Bit Clock phát loa |
| | **GPIO 18** | I2S1 WS / LRC | Word Select |
| | **GPIO 21** | I2S1 DOUT / DIN | Serial Data OUT từ ESP32 sang DAC |
| | **GPIO 2** | `SP_SD` | **Hardware Shutdown / Mute**. Mức `1`: Bật Amply; Mức `0`: Ngắt Amply về chế độ ngủ 0.01 µA để chống ù xì. |
| **Relay Kênh 1 (RL1)** | **GPIO 4** | GPIO Output | **Đèn phòng ngủ**. Kích vào Chân 2 (Cathode) Opto PC817 $\rightarrow$ **Active-LOW** (`0`: Bật, `1`: Tắt). |
| **Relay Kênh 2 (RL2)** | **GPIO 5** | GPIO Output | **Quạt phòng ngủ**. Kích vào Chân 2 (Cathode) Opto PC817 $\rightarrow$ **Active-LOW** (`0`: Bật, `1`: Tắt). |
| **Nút bấm 1 (BUT1)** | **GPIO 1** | GPIO Input (Pull-up) | Bấm nút cứng bật/tắt trực tiếp Relay 1 tại chỗ. |
| **Nút bấm 2 (BUT2)** | **GPIO 3** | GPIO Input (Pull-up) | Bấm nút cứng bật/tắt trực tiếp Relay 2 tại chỗ. |
| **Đèn LED1** | **GPIO 48** | GPIO Output | Chỉ thị trạng thái Hệ thống / Nguồn / Wi-Fi & MQTT. |
| **Đèn LED2** | **GPIO 47** | GPIO Output | Chỉ thị Giọng nói / Đang nghe / Nhận diện WakeNet. |
| **Giao tiếp I2C** | **GPIO 41 (SDA), GPIO 42 (SCL)** | I2C Master | Chân dự phòng mở rộng cảm biến I2C. |
| **Mắt Hồng Ngoại (IR)** | **GPIO 7 (IR_RX), GPIO 40 (IR_TX)** | RMT / GPIO | Thu phát hồng ngoại điều khiển điều hòa, quạt. |

---

### 2.2. ESP32 WROOM Energy Slave Node
* **Vi điều khiển:** ESP32-WROOM-32.
* **Cảm biến:** PZEM-004T v3.0 (giao tiếp qua UART phần cứng).
* **Thông số thu thập:**
  - Điện áp ($U$): 80 ~ 260 VAC.
  - Dòng điện ($I$): 0 ~ 100 A.
  - Công suất tức thời ($P$): 0 ~ 23 kW.
  - Điện năng tích lũy ($E$): 0 ~ 9999 kWh.
  - Tần số ($f$): 45 ~ 65 Hz.
  - Hệ số công suất ($\cos\varphi$ / PF): 0.00 ~ 1.00.
* **Giao thức đẩy dữ liệu:** Gói tin nhị phân chuẩn `esp_now_packet_t` gửi về Master định kỳ mỗi chu kỳ polling hoặc gửi ngay khi có biến động tải.

---

### 2.3. Raspberry Pi 4 Gateway
* **Phần cứng:** Raspberry Pi 4 Model B (4GB / 8GB RAM), CPU Broadcom BCM2711 Quad-core Cortex-A72 @ 1.5/1.8GHz.
* **Hệ điều hành:** Raspberry Pi OS 64-bit (Debian GNU/Linux).
* **Địa chỉ IP cố định:** `192.168.11.29`.
* **Dịch vụ mạng:**
  - Cổng `1883`: MQTT Broker (EMQX).
  - Cổng `8080`: llama-server (`llama.cpp` OpenAI API).
  - Cổng `8765`: Audio Streaming WebSocket Server.
  - Cổng `8000`: Web Monitor Dashboard (FastAPI + SSE Stream).
  - Cổng `8086`: InfluxDB v2 Time-series Database.

---

## 3. Kiến Trúc Phân Tích Dữ Liệu & Trí Tuệ Nhân Tạo (AI & Data Pipeline)

### 3.1. Nhận dạng Tiếng nói (Speech-to-Text — ASR)
* **Thư viện:** `sherpa-onnx` (ONNX Runtime biên dịch cho ARM64).
* **Mô hình:** **Zipformer Transducer tiếng Việt**.
* **Đặc tả tệp mô hình (`/home/pi4/smarthome/models`):**
  - `encoder.onnx`: Trích xuất đặc trưng âm học đa tầng.
  - `decoder.onnx`: Giải mã ngôn ngữ dựa trên ngữ cảnh chuỗi ký tự trước.
  - `joiner.onnx`: Hợp nhất xác suất âm học và ngôn ngữ.
  - `tokens.txt`: Bảng mã từ vựng âm tiết tiếng Việt có dấu.
* **Hiệu năng:** Độ trễ giải mã < 350ms trên CPU Pi 4 (2 threads), hỗ trợ phát hiện tiếng nói VAD tự động ngắt sau 1.5s im lặng.

---

### 3.2. Hiểu Ngôn Ngữ Tự Nhiên & Trích Xuất Lệnh (Hybrid NLU — Cloud & Edge AI)

Hệ thống triển khai **Kiến trúc Hybrid 2 tầng song song (Parallel Hybrid Architecture)** với khả năng chuyển đổi mượt mà (Seamless Automatic Switching) giữa Trí tuệ Nhân tạo Đám mây và Mô hình Biên Cục bộ:

```
                      ┌───────────────────────────┐
                      │    Khẩu lệnh Tiếng Việt   │
                      │  "bật đèn phòng ngủ master" │
                      └─────────────┬─────────────┘
                                    │
                                    ▼
                      ┌───────────────────────────┐
                      │    IntentEngine Router    │
                      └──────┬─────────────┬──────┘
                             │             │
        (Có mạng & có key)   │             │ (Mất mạng / Timeout >3.5s / Offline)
        ┌────────────────────┘             └────────────────────┐
        ▼                                                       ▼
┌───────────────────────────────┐               ┌───────────────────────────────┐
│     TẦNG 1: CLOUD AI          │               │     TẦNG 2: EDGE LOCAL AI     │
│   Google Gemini 1.5 Flash     │  Fallback     │      Qwen2.5-3B-Instruct      │
│  - Phản hồi siêu tốc: ~0.35s  │ ────────────> │  - llama-server (llama.cpp)   │
│  - Ngữ cảnh: 1M tokens        │ (Tự động &    │  - Context: 1024 tokens       │
│  - Schema: JSON Strict        │  không lỗi)   │  - GBNF Grammar ép schema     │
│  - Hoàn toàn miễn phí         │               │  - Không cần mạng (100% riêng)│
└───────────────┬───────────────┘               └───────────────┬───────────────┘
                │                                               │
                └───────────────────────┬───────────────────────┘
                                        ▼
                        ┌───────────────────────────────┐
                        │ JSON Trích Xuất Ý Định Hợp Lệ │
                        │  {"action": "turn_on", ...}   │
                        └───────────────┬───────────────┘
                                        ▼
                        ┌───────────────────────────────┐
                        │     LỚP 2: REGISTRY NLU       │
                        │ Phân giải node_id & channel   │
                        │      Chống ảo giác 100%       │
                        └───────────────────────────────┘
```

#### Tầng 1 — Cloud Primary Tier (Google Gemini 1.5 Flash):
* **Mô hình:** `gemini-1.5-flash` qua REST API trực tiếp (`httpx`), không phụ thuộc SDK nặng.
* **Tốc độ phản hồi:** **0.3s — 0.5s** (Cực kỳ nhạy, tức thì cho trải nghiệm giọng nói).
* **Đặc tả:** Tích hợp `responseMimeType: "application/json"`, nhiệt độ `0.0`.
* **Cấu hình:** Đặt `GEMINI_API_KEY=AIzaSy...` trong file `.env` (ở `Gateway/.env` hoặc `/home/pi4/.env`). Nếu chưa có key hoặc mạng chập chờn, hệ thống tự động nhảy sang Tầng 2 mà không ném lỗi ra người dùng.

#### Tầng 2 — Local Edge Fallback Tier (Qwen2.5-3B trên Raspberry Pi 4):
* **Runtime:** `llama-server` (`llama.cpp` ARM64 build) chạy service nền `llama-server.service`.
* **Mô hình:** **Qwen2.5-3B-Instruct (Q4_K_M)** (`/home/pi4/models/qwen2.5-3b-instruct-q4_k_m.gguf`, 2.04 GB, 3.09 tỷ tham số).
* **Tham số tối ưu hóa phần cứng Pi 4 (4GB RAM):**
  - Context size: `-c 1024` tokens (Mở rộng cửa sổ ngữ cảnh theo yêu cầu).
  - Slot processing: `-np 1` (Ép 1 slot đơn để loại bỏ hiện tượng tràn bộ nhớ swap, giữ dung lượng RAM vật lý 0B swap).
  - Luồng CPU: `-t 4` (Tận dụng 4 nhân Cortex-A72 @ 1.5GHz).
* **Bộ đệm ngữ cảnh (Prompt KV Cache):**
  - Kích hoạt `cache_prompt: True` trong `llama.cpp`. Lần gọi đầu tiên (cold start) đánh giá prompt mất ~70s, nhưng các lần gọi tiếp theo được tái sử dụng KV cache $\rightarrow$ thời gian phản hồi rút ngắn xuống chỉ còn **~34 giây**!
* **Ngữ pháp GBNF (Chống ảo giác tuyệt đối):**
  - Sử dụng GBNF Grammar ép LLM chỉ được phép sinh các token thiết bị (`"den"`, `"quat"`, ...) và phòng (`"phong_ngu"`, `"phong_khach"`, ...) đang thực tế tồn tại trong `device_registry.json`.

#### Tầng 3 — Registry Resolver & Ánh Xạ Phần Cứng:
* Khi nhận JSON từ LLM, hàm `find_node_by_device(device, location)` trong `registry_manager.py` sẽ đối chiếu với cơ sở dữ liệu `device_registry.json`.
* Tự động xử lý các trường hợp:
  - Khẩu lệnh chuẩn: *"bật đèn phòng ngủ"* $\rightarrow$ Node `esp32s3_master`, Channel `ch1` (GPIO 4).
  - Khẩu lệnh tắt: *"tắt quạt phòng ngủ"* $\rightarrow$ Node `esp32s3_master`, Channel `ch2` (GPIO 5).
  - Khẩu lệnh thiếu phòng: Tự động hỏi lại phòng hoặc chọn thiết bị phù hợp nhất.
  - Khẩu lệnh không tồn tại: Báo lỗi thân thiện thay vì gửi lệnh rác xuống relay.

---

### 3.3. Tổng Hợp Tiếng Nói (Text-to-Speech — TTS)
* **Động cơ:** `Microsoft EdgeTTS` (`vi-VN-HoaiMyNeural` giọng nữ chuẩn Hà Nội, fallback `vi-VN-NamMinhNeural`).
* **Xử lý âm thanh:** Chuyển đổi định dạng MP3 $\rightarrow$ Raw PCM (16kHz, 16-bit, Little-Endian Mono) bằng thư viện `pydub` và `ffmpeg`.
* **Kiểm soát luồng (Throttling):** Truyền qua WebSocket với từng chunk 2048 bytes (64ms âm thanh), nghỉ 35ms giữa các chunk (~1.8x tốc độ thời gian thực) giúp bộ đệm ESP32 hấp thụ liên tục mà không bị nghẽn mạng TCP hay sập WebSocket.

---

### 3.4. Xác Thực Vòng Lặp Kín (Closed-Loop Verification Engine)
Khác biệt hoàn toàn với các giải pháp IoT truyền thống (chỉ gửi lệnh một chiều), hệ thống triển khai thuật toán **Closed-loop Verification**:
1. Ghi nhận công suất trước lệnh: $P_{before}$.
2. Bắn lệnh bật/tắt relay qua MQTT.
3. Chờ phản hồi cảm biến và đo lại: $P_{after}$.
4. Tính độ lệch công suất: $\Delta P = P_{after} - P_{before}$.
5. Đánh giá:
   - Nếu $\Delta P > \max(0.3 \times P_{rated}, 3.0W) \rightarrow$ `SUCCESS` (Xác nhận tải thực tế đã khởi động).
   - Nếu $\Delta P \le 0 \rightarrow$ `FAILED` (Relay đóng nhưng không có dòng điện tiêu thụ $\rightarrow$ bóng đèn bị cháy hoặc thiết bị chưa cắm điện).
6. **Cơ chế dự phòng:** Đối với các node chỉ có relay đơn thuần chưa tích hợp cảm biến đo dòng PZEM (như `esp32s3_master`), hệ thống tự động nhận diện `before = 0` & `after = 0` để xác nhận thành công qua gói tin trạng thái relay, phản hồi tích cực ngay lập tức.

---

### 3.5. Bộ Nhớ 3 Tầng & Tự Học Thói Quen (3-Tier Memory Engine)
* **Tầng 1 — STM (Short-Term Memory):** Lưu trữ trên RAM các câu lệnh gần nhất để duy trì chuỗi ngữ cảnh đối thoại.
* **Tầng 2 — MTM (Medium-Term Memory):** SQLite Database (`/home/pi4/smarthome/memory.db`):
  - `command_log`: Lịch sử thời gian thực (Timestamp, Giờ trong ngày, Thứ trong tuần, Khẩu lệnh, Thiết bị, Khu vực, Công suất trước/sau, Kết quả verify).
  - `user_corrections`: Dữ liệu những lần người dùng sửa lại lệnh khi AI phân tích nhầm.
  - `power_baselines`: Bản ghi công suất tiêu thụ định mức thực tế (Avg, Min, Max).
* **Tầng 3 — LTM (Long-Term Memory / Machine Learning Patterns):**
  - Bảng `learned_patterns`: Thuật toán tự động gom cụm thói quen sinh hoạt (ví dụ: Người dùng thường xuyên bật quạt phòng ngủ vào lúc 22h tối các ngày trong tuần $\rightarrow$ nâng độ tin cậy `confidence` $\rightarrow$ tự động gợi ý hành động tự động hóa).

---

### 3.6. Mô Hình TinyML Trên ESP32-S3 (On-Device Inference)
Mô hình TinyML chạy song song trên Core 0 của ESP32-S3 phân tích đặc tính dạng sóng công suất:
* **Đỉnh vọt dòng khởi động:** $P > 800W$ và $\Delta P > 250W \rightarrow$ Phát hiện tải khởi động máy nén/động cơ điều hòa, máy bơm nước.
* **Hệ số $\cos\varphi$ thấp:** $PF < 0.80$ và $I > 0.4A \rightarrow$ Phát hiện tải cảm kháng (quạt, biến áp), đưa ra khuyến nghị gắn tụ bù tiết kiệm điện.
* **Tải ngầm (Standby Vampire Load):** $0 < P < 35W \rightarrow$ Phát hiện thiết bị ở chế độ chờ tiêu hao vô ích, khuyến nghị ngắt công tắc.

---

## 4. Hệ Thống Âm Báo Phản Hồi Loa (Audio Feedback Cues)

Hệ thống tích hợp bộ tổng hợp sóng sin thuần túy ([audio_feedback.c](file:///d:/Home-Assistant-IoT-/Firmware/firmware_esp/Esp32S3_Master/src/audio_feedback.c)) với các đường bao Envelope Ramp Attack/Decay để triệt tiêu hoàn toàn tiếng nổ "pop/click" của loa:

| Sự kiện hệ thống | Kiểu âm thanh | Tần số & Thời lượng | Mục đích trải nghiệm người dùng |
| :--- | :--- | :--- | :--- |
| **Server Connected** | Arpeggio 3 nốt thăng hoa | C5 (523Hz) $\rightarrow$ E5 (659Hz) $\rightarrow$ G5 (784Hz) | Báo hiệu ESP32 đã kết nối mạng Wi-Fi và WebSocket tới Pi 4 thành công. |
| **Wake Word ("Hi ESP")**| Ding! thanh thoát | A5 (880Hz) $\rightarrow$ C6 (1046Hz), 120ms | Xác nhận ESP32 đã nghe thấy từ khóa, sẵn sàng nhận lệnh. |
| **Listening Completed** | Tick nhẹ nhàng | E5 (659Hz), 60ms | Xác nhận đã thu âm xong câu lệnh của người dùng, bắt đầu xử lý. |
| **Error / Disconnected**| Âm trầm giáng cảnh báo | 330Hz $\rightarrow$ 220Hz, 250ms | Báo lỗi mất kết nối máy chủ hoặc sự cố hệ thống. |

> [!IMPORTANT]
> **Cơ chế Khóa Phần Cứng (Hardware Mutex):** Sử dụng `spk_hw_mutex` ngăn chặn hoàn toàn hiện tượng xung đột tài nguyên giữa tác vụ phát âm báo hệ thống và tác vụ phát giọng nói TTS, bảo vệ chân `SP_SD` không bị tắt nhầm giữa chừng.

---

## 5. Cấu Hình MQTT & Thiết Bị (Device Registry)

### 5.1. Định dạng Topics MQTT
* **Đăng ký:** `smarthome/register` (QoS 1)
* **Điều khiển:** `smarthome/command/{node_id}`
* **Trạng thái:** `smarthome/status/{node_id}`
* **Dữ liệu điện:** `smarthome/telemetry/{node_id}`
* **Cảnh báo:** `smarthome/alert`

### 5.2. Hồ Sơ Đăng Ký Node Phòng Ngủ (`esp32s3_master`)
```json
{
  "node_id": "esp32s3_master",
  "mac": "30:ED:A0:BD:69:D4",
  "area": "phong_ngu",
  "description": "ESP32-S3 Master Voice + 2-CH Relay Phòng Ngủ",
  "channels": {
    "ch1": {
      "device_type": "den",
      "description": "Đèn phòng ngủ",
      "gpio": 4,
      "rated_watts": 40.0,
      "aliases": ["den", "den_ngu", "den_phong_ngu", "den_chinh"]
    },
    "ch2": {
      "device_type": "quat",
      "description": "Quạt phòng ngủ",
      "gpio": 5,
      "rated_watts": 55.0,
      "aliases": ["quat", "quat_ngu", "quat_phong_ngu", "quat_tran"]
    }
  }
}
```

---

## 6. Danh Mục Các Tệp Mã Nguồn Quan Trọng (File Tree)

```text
d:\Home-Assistant-IoT-\
├── Firmware\
│   └── firmware_esp\
│       └── Esp32S3_Master\
│           ├── platformio.ini               # Cấu hình PlatformIO (ESP-IDF 5.3.1, N16R8)
│           ├── partitions.csv               # Bảng phân vùng (OTA, Model 8MB, Storage)
│           ├── include\
│           │   ├── audio_feedback.h         # Header bộ âm báo phản hồi loa & Mutex
│           │   ├── mqtt_relay.h             # Cấu hình Relay (Active-LOW) & MQTT Client
│           │   └── ws_audio_client.h        # Client truyền nhận âm thanh WebSocket
│           └── src\
│               ├── main.c                   # Entry point: AFE, WakeNet, ESP-NOW, TinyML
│               ├── audio_feedback.c         # Bộ tổng hợp âm thanh Sine Wave + Envelope
│               ├── mqtt_relay.c             # Điều khiển Relay và gửi nhận MQTT
│               └── ws_audio_client.c        # Xử lý luồng âm thanh WebSocket 192KB PSRAM
├── Gateway\
│   ├── device_registry.json                 # Cơ sở dữ liệu danh mục thiết bị & Alias
│   ├── requirements.txt                     # Các gói thư viện Python yêu cầu
│   ├── systemd\
│   │   ├── llama-server.service             # Dịch vụ systemd chạy Qwen2.5 trên Pi 4
│   │   └── smarthome-gateway.service        # Dịch vụ systemd chạy Gateway chính
│   └── gateway\
│       ├── config.py                        # Tệp cấu hình tập trung toàn bộ hệ thống
│       ├── main.py                          # Bộ điều phối trung tâm (Central Orchestrator)
│       ├── asr_engine.py                    # Nhận dạng giọng nói Sherpa-ONNX
│       ├── intent_engine.py                 # Phân tích cú pháp khẩu lệnh qua LLM
│       ├── tts_engine.py                    # Chuyển văn bản thành giọng nói EdgeTTS
│       ├── audio_server.py                  # Server WebSocket stream âm thanh 2 chiều
│       ├── verify_engine.py                 # Động cơ đối soát vòng lặp kín năng lượng
│       ├── memory_engine.py                 # Bộ nhớ 3 tầng & khai phá mẫu thói quen
│       ├── mqtt_handler.py                  # Trình quản lý kết nối & điều phối MQTT
│       ├── registry_manager.py              # Tìm kiếm thiết bị mờ (Fuzzy/Alias matcher)
│       ├── telemetry_writer.py              # Ghi dữ liệu chuỗi thời gian vào InfluxDB
│       └── web_server.py                    # Web Monitor Dashboard thời gian thực (SSE)
├── Hardware\
│   └── PCB\
│       └── IoT_Board\
│           ├── IoT_Board.kicad_sch          # Sơ đồ nguyên lý mạch phần cứng
│           └── netlist.net                  # Danh sách liên kết mạch (Netlist)
└── systemif.md                              # Tài liệu hiện trạng hệ thống tổng thể (Tệp này)
```

---

## 7. Trạng Thái Vận Hành & Khắc Phục Lỗi Gần Nhất

1. **Khắc phục lỗi treo WebSocket Disconnect/Reconnect:**
   - Đã nâng cấp bộ đệm âm thanh loa lên **192 KB trong Octal PSRAM** của ESP32-S3.
   - Chuyển việc ghi dữ liệu sang chế độ Non-blocking (`timeout = 0`) để không làm nghẽn task mạng của ESP-IDF.
   - Điều chỉnh thời gian nghỉ truyền gói tin trên Pi 4 thành `35ms` (~1.8x tốc độ phát thực) triệt tiêu tình trạng dồn ứ TCP.
2. **Khắc phục lỗi xung đột Loa I2S:**
   - Tích hợp `spk_hw_mutex` đảm bảo an toàn tuyệt đối khi phát âm báo và giọng nói phản hồi.
   - Đưa âm báo hoàn tất thu âm (`AUDIO_FB_RECORDING_DONE`) lên phát trước khi gửi gói kết thúc lên Gateway.
3. **Sửa cực điều khiển Relay phần cứng:**
   - Đã cấu hình chính xác `RELAY_ACTIVE_LOW true` phù hợp với tầng kích cực âm Opto PC817 trên PCB, relay không bị nhảy sai khi khởi động.
4. **Xác thực lệnh thông minh trên Gateway:**
   - Gateway tự động phân biệt các node có cảm biến đo dòng và node không có cảm biến đo dòng để phản hồi thành công ngay lập tức, không gây báo lỗi giả.
5. **Kiến Trúc Định Danh Thiết Bị Thương Mại (Commercial Device Architecture) & Vòng Đời Thiết Bị:**
   - Tách bạch hoàn toàn giữa **Hardware Identity** (bất biến, sinh từ eFuse MAC của chip) và **User Identity** (gán bởi người dùng khi Claim thiết bị).
   - Loại bỏ triệt để chuỗi cứng prototype (`esp32s3_master`), cho phép nạp hàng loạt (Mass Flash) cùng một file firmware factory mà không bao giờ bị trùng tên.
   - Cơ chế Factory Reset 10 giây: giữ nguyên `device_id` và phần cứng, xóa sạch Wi-Fi và User Identity để chuyển về trạng thái `FACTORY_NEW`.
   - Chuẩn hóa phần cứng đèn báo trạng thái: dùng 2 LED đơn rời rạc (LED1: GPIO 48 - Hệ thống/Mạng; LED2: GPIO 47 - Giọng nói/OTA), loại bỏ hoàn toàn các mã liên quan đến LED RGB.

---

## 8. Chuẩn Kiến Trúc Định Danh & Vòng Đời Thiết Bị (Device OS & Registry)

### 8.1. Sơ Đồ Khối Thực Thể (Entity Architecture)
```
┌──────────────────────────────────────────────┐
│           RASPBERRY PI 4 GATEWAY             │
│                                              │
│  Device Registry                             │
│  ├── device_id (Primary Key, e.g. node_xxxx) │
│  ├── name ("Loa phòng ngủ")                 │
│  ├── room ("bedroom")                        │
│  ├── address (ip, mac, rssi, last_seen)      │
│  ├── capabilities (voice, audio, relay, ota) │
│  ├── firmware (version, hardware, serial)    │
│  ├── configuration (relays, audio, cfg_ver)  │
│  └── security (state, claimed_at)            │
└──────────────────────┬───────────────────────┘
                       │ WebSocket / MQTT
                       ▼
┌──────────────────────────────────────────────┐
│                   ESP32-S3                   │
│                                              │
│  Device OS Modules:                          │
│  ├── Identity (Hardware ID & User ID)        │
│  ├── Provisioning (Pending & Claim Handshake)│
│  ├── Config (NVS Preserved / Erased)         │
│  ├── OTA (Dual-Channel Safe Pull)            │
│  ├── Network (Wi-Fi STA + AP Fallback)       │
│  ├── Audio (WakeNet + I2S DMA Voice/Speaker) │
│  └── Application (Relays, Energy, TinyML)    │
└──────────────────────────────────────────────┘
```

### 8.2. Cấu Trúc Định Danh (Identity Schemas)
- **Hardware Identity (Bất biến, lưu NVS namespace `hw_id`):**
  ```json
  {
    "device_id": "node_7f3a91c2",
    "hardware": "esp32s3",
    "serial": "S3-2026-000183"
  }
  ```
  *(Sinh tự động từ eFuse MAC của chip ESP32-S3; 10,000 thiết bị nạp chung 1 file firmware factory vẫn sở hữu `device_id` và `serial` duy nhất toàn cầu)*.

- **User Identity (Tùy biến, lưu NVS namespace `user_id`):**
  ```json
  {
    "name": "Loa phòng ngủ",
    "room": "bedroom",
    "location": "Tầng 2 - Phòng ngủ",
    "description": "Voice node"
  }
  ```

### 8.3. Máy Trạng Thái Vòng Đời Thiết Bị (Lifecycle State Machine)
```
  [ FACTORY_NEW ] ──(setup)──> [ PROVISIONING ] ──(user assigns)──> [ CLAIMED ] ──(boot)──> [ READY ]
                                                                                                 │
                                                        ┌────────────────────────────────────────┴───────────────────┐
                                                        ▼                                                            ▼
                                                [ OTA / RECOVERY ]                                          [ READY (Normal) ]
```

### 8.4. Quy Trình Khôi Phục Cài Đặt Gốc (Factory Reset Flow)
```
  [ READY ]
     │ (Nhấn giữ Nút BUT1 trong 10 giây)
     ▼
  [ FACTORY_RESET ]
     ├── Erase user config (Xóa tên, phòng, mô tả)
     ├── Erase Wi-Fi credentials
     ├── Erase Gateway binding
     ├── Erase credentials
     └── KEEP device_id & hardware_identity (Bảo toàn ID phần cứng)
     │
     ▼
  [ FACTORY_NEW ] (Khởi động lại về trạng thái xuất xưởng chờ gán mới)
```

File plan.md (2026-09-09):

# 🏠 DTV Smart Home — Bản Kế Hoạch Tổng Thể

---

> ## 🎯 MỤC TIÊU CỐT LÕI (NORTH STAR — đọc lại trước mỗi quyết định)
>
> **"Xây dựng hệ thống nhà thông minh TỰ HÀNH & NHẬN THỨC (Cognitive & Proactive Autonomous Smart Home), lấy dữ liệu điện năng làm PHẢN HỒI VÒNG KÍN (closed-loop) để TỰ HỌC thói quen người dùng và CHỦ ĐỘNG điều khiển, gợi ý, nhắc nhở."**
>
> Mọi dòng code, mọi quyết định kiến trúc, mọi tính năng **phải phục vụ** mục tiêu này.
> Nếu một tính năng không giúp hệ thống: (1) hiểu người dùng hơn, (2) tự động hơn, hoặc (3) an toàn hơn — thì **KHÔNG LÀM**.

---

## 📋 Mục Lục

1. [Tổng Quan Kiến Trúc](#1-tổng-quan-kiến-trúc)
2. [Hiện Trạng Dự Án](#2-hiện-trạng-dự-án)
3. [Phase 0 — Foundation (Nền Tảng)](#phase-0--foundation-nền-tảng)
4. [Phase 1 — Voice Pipeline (Giọng Nói → Lệnh)](#phase-1--voice-pipeline-giọng-nói--lệnh)
5. [Phase 2 — Closed-Loop Control (Vòng Kín Điều Khiển)](#phase-2--closed-loop-control-vòng-kín-điều-khiển)
6. [Phase 3 — Memory & Learning (Bộ Nhớ & Tự Học)](#phase-3--memory--learning-bộ-nhớ--tự-học)
7. [Phase 4 — Proactive Intelligence (Trí Tuệ Chủ Động)](#phase-4--proactive-intelligence-trí-tuệ-chủ-động)
8. [Phase 5 — MCP Integration & Ecosystem](#phase-5--mcp-integration--ecosystem)
9. [Phase 6 — Dashboard & User Experience](#phase-6--dashboard--user-experience)
10. [Verification & Testing Strategy](#verification--testing-strategy)
11. [Rủi Ro & Giải Pháp](#rủi-ro--giải-pháp)
12. [Timeline Dự Kiến](#timeline-dự-kiến)

---

## 1. Tổng Quan Kiến Trúc

```
┌─────────────────────────────────────────────────────────────────────────┐
│                        COGNITIVE SMART HOME                           │
│                                                                       │
│  ┌─────────────┐    WebSocket     ┌──────────────────────────────┐    │
│  │  ESP32-S3    │◄──────────────►│    Raspberry Pi 4 (Brain)     │    │
│  │  Voice Node  │   Opus/PCM      │                              │    │
│  │  ┌─────────┐ │                 │  ┌────────┐  ┌────────────┐  │    │
│  │  │INMP441  │ │                 │  │SherpaON│  │ Qwen2.5    │  │    │
│  │  │ Mic     │ │    MQTT         │  │  ASR   │──│ 1.5B LLM   │  │    │
│  │  └─────────┘ │◄──────────────►│  └────────┘  └─────┬──────┘  │    │
│  │  ┌─────────┐ │                 │                    │         │    │
│  │  │MAX98357 │ │                 │  ┌────────────┐    ▼         │    │
│  │  │ Speaker │ │◄───────────────│  │  EdgeTTS   │  ┌────────┐  │    │
│  │  └─────────┘ │   Opus/PCM      │  │  (Output)  │  │Gateway │  │    │
│  │  ┌─────────┐ │                 │  └────────────┘  │Python  │  │    │
│  │  │WakeNet  │ │                 │                   └───┬────┘  │    │
│  │  │"Hi ESP" │ │                 │                       │      │    │
│  │  └─────────┘ │                 │              ┌────────▼────┐ │    │
│  └──────┬───────┘                 │              │   EMQX      │ │    │
│         │ ESP-NOW                  │              │   Broker    │ │    │
│  ┌──────▼───────┐                 │              └─────┬───────┘ │    │
│  │  ESP32       │                 │  ┌─────────────────▼───────┐ │    │
│  │  WROOM       │                 │  │ InfluxDB  │ Grafana    │ │    │
│  │  Relay Node  │                 │  │ Telemetry │ Dashboard  │ │    │
│  │  ┌─────────┐ │                 │  └───────────┴────────────┘ │    │
│  │  │PZEM-004T│ │                 │  ┌────────────────────────┐ │    │
│  │  │ Sensor  │ │                 │  │ Home Assistant + MCP   │ │    │
│  │  └─────────┘ │                 │  └────────────────────────┘ │    │
│  │  ┌─────────┐ │                 │  ┌────────────────────────┐ │    │
│  │  │ 2-CH    │ │                 │  │ Memory Engine          │ │    │
│  │  │ Relay   │ │                 │  │ (SQLite + Patterns)    │ │    │
│  │  └─────────┘ │                 │  └────────────────────────┘ │    │
│  └──────────────┘                 └──────────────────────────────┘    │
└─────────────────────────────────────────────────────────────────────────┘
```

### Phân Tầng Hệ Thống (Layered Architecture)

| Tầng | Tên | Trách Nhiệm | Thiết Bị |
|---|-----|---|---|
| **L0** | Hardware | Relay, Sensor, Mic, Speaker | ESP32-S3 N16R8, ESP32 WROOM |
| **L1** | Communication | ESP-NOW, MQTT, WebSocket | EMQX Broker |
| **L2** | Perception | ASR, VAD, Intent Extraction | Sherpa-ONNX, Qwen LLM |
| **L3** | Decision | Command Dispatch, Validation | Gateway Python |
| **L4** | Memory | Telemetry Storage, User Profile | InfluxDB, SQLite |
| **L5** | Intelligence | Pattern Learning, Proactive Actions | Cron + Qwen Analysis |
| **L6** | Interface | Voice Output, Dashboard, MCP | EdgeTTS, Grafana, HA |

---

## 2. Hiện Trạng Dự Án

### ✅ Đã Hoàn Thành

| Hạng mục | Chi tiết | Trạng thái |
|---|---|---|
| **Pi 4 Infrastructure** | Ubuntu Lite, Docker (EMQX, InfluxDB, Grafana, HA) | ✅ Running |
| **LLM Engine** | `llama-server` + `Qwen2.5-1.5B-Instruct-Q4_K_M` @ 127.0.0.1:8080 | ✅ Validated |
| **Intent Extraction** | `cli_json.sh` — Prompt tối ưu cho Area/Device/Action schema | ✅ Tested |
| **ESP32-S3 Firmware** | I2S Mic (INMP441), Speaker (MAX98357A), WakeNet "Hi ESP", ESP-NOW, TinyML | ✅ Compiled |
| **ESP32 WROOM Slave** | PZEM-004T sensor, 2-CH Relay, ESP-NOW telemetry | ✅ Working |
| **Python venv** | `/home/pi4/voice_gateway_venv` | ✅ Created |

### 🔲 Chưa Triển Khai

| Hạng mục | Ưu tiên |
|---|---|
| WebSocket Audio Streaming (ESP32 → Pi) | 🔴 Critical |
| Opus Codec (Nén/Giải nén) | 🔴 Critical |
| SherpaONNX ASR (Speech-to-Text) | 🔴 Critical |
| Gateway Python (Orchestrator) | 🔴 Critical |
| EdgeTTS (Text-to-Speech) | 🟡 High |
| Device Registry (Dynamic Registration) | 🟡 High |
| Closed-Loop Verification | 🟡 High |
| Memory Engine (User Profile) | 🟠 Medium |
| Proactive Intelligence | 🟠 Medium |
| MCP Server Integration | 🟢 Later |
| Dashboard Polish | 🟢 Later |

---

## Phase 0 — Foundation (Nền Tảng)

> **🎯 Checkpoint:** Phase này phục vụ mục tiêu cốt lõi bằng cách tạo HẠNG MỤC LIÊN LẠC CHUNG (communication backbone) giữa tất cả các thành phần — không có nền tảng thì không có gì tự hành được.

### 0.1 Device Registry — Đăng Ký Thiết Bị Động

**Vấn đề:** Khi thêm 1 ESP32 Node mới, server phải biết node đó ở đâu, điều khiển thiết bị gì.

**Giải pháp:** File `device_registry.json` trên Pi — mỗi node tự đăng ký khi boot qua MQTT.

```json
{
  "nodes": {
    "esp32_wroom_01": {
      "mac": "AA:BB:CC:DD:EE:01",
      "area": "phong_ngu_master",
      "description": "Node phòng ngủ chính",
      "channels": {
        "ch1": {
          "device_type": "den_ngu",
          "description": "Đèn ngủ đầu giường",
          "rated_watts": 7,
          "gpio": 26
        },
        "ch2": {
          "device_type": "den_tran",
          "description": "Đèn trần chiếu sáng",
          "rated_watts": 40,
          "gpio": 27
        }
      },
      "sensors": {
        "pzem": true,
        "temperature": false
      },
      "registered_at": "2026-09-10T00:00:00+07:00",
      "last_seen": "2026-09-10T01:00:00+07:00",
      "status": "online"
    }
  }
}
```

**Cách đăng ký Node mới:**

1. Flash firmware chuẩn lên ESP32 WROOM mới
2. Node boot → Gửi MQTT message tới topic `smarthome/register`
3. Gateway nhận → Tạo entry trong registry (status = `pending`)
4. User qua Dashboard/Voice: _"Node mới ở ban công, ổ 1 là đèn ban công, ổ 2 là quạt hút"_
5. Gateway cập nhật registry → Node chuyển `online`

**Files cần tạo:**

```
/home/pi4/smarthome/
├── device_registry.json          # Registry dữ liệu
├── gateway/
│   ├── registry_manager.py       # CRUD cho registry
│   ├── mqtt_handler.py           # MQTT subscribe/publish
│   └── config.py                 # MQTT/LLM/TTS config
```

### 0.2 MQTT Topic Convention

```
smarthome/
├── register                      # Node đăng ký: {"mac":"...", "channels":{...}}
├── telemetry/{node_id}           # Dữ liệu PZEM real-time
│   └── {"voltage":220, "current":0.5, "power":110, ...}
├── command/{node_id}             # Lệnh điều khiển từ Gateway
│   └── {"channel":"ch1", "action":"turn_on"}
├── status/{node_id}              # Node heartbeat + relay state
│   └── {"online":true, "ch1":1, "ch2":0, "uptime_s":3600}
├── voice/audio_stream            # (Reserved) Raw audio chunks
├── voice/intent                  # Kết quả intent extraction
│   └── {"action":"turn_on", "device":"den_ngu", ...}
└── alert                         # Hệ thống cảnh báo
    └── {"type":"anomaly", "node":"esp32_wroom_01", ...}
```

### 0.3 ESP32 WROOM Firmware Chuẩn Hóa

Cập nhật firmware WROOM Slave để hỗ trợ:

- [x] PZEM-004T đọc liên tục (đã có)
- [x] ESP-NOW gửi telemetry (đã có)
- [ ] **MỚI:** Kết nối Wi-Fi + MQTT client song song với ESP-NOW
- [ ] **MỚI:** Gửi telemetry qua MQTT topic `smarthome/telemetry/{node_id}` (mỗi 2 giây)
- [ ] **MỚI:** Subscribe `smarthome/command/{node_id}` để nhận lệnh relay
- [ ] **MỚI:** Tự đăng ký qua `smarthome/register` khi boot
- [ ] **MỚI:** Heartbeat `smarthome/status/{node_id}` mỗi 30 giây

**Lý do chuyển sang MQTT thay vì chỉ ESP-NOW:**
- ESP-NOW giới hạn 250 bytes/packet, không reliable
- MQTT qua Wi-Fi: reliable, buffered, QoS, dễ scale
- ESP-NOW vẫn giữ làm **fallback** khi Wi-Fi mất

---

## Phase 1 — Voice Pipeline (Giọng Nói → Lệnh)

> **🎯 Checkpoint:** Phase này phục vụ mục tiêu cốt lõi bằng cách tạo KÊNH GIAO TIẾP TỰ NHIÊN — user nói bằng giọng nói, hệ thống hiểu và thực thi. Đây là điều kiện tiên quyết để hệ thống "nhận thức".

### 1.1 Audio Streaming: ESP32-S3 → Pi 4 (WebSocket + Opus)

**Flow:**

```
[INMP441 Mic] → [I2S 16kHz/16bit] → [Opus Encode] → [WebSocket] → [Pi 4]
```

**ESP32-S3 Side (Firmware Modification):**

```c
// Thêm vào main.c sau khi WakeNet detected:
// 1. Kết nối WebSocket tới ws://192.168.11.29:8765/audio
// 2. Encode PCM chunks bằng Opus (bitrate: 16kbps, frame: 20ms)
// 3. Gửi Opus frames qua WebSocket
// 4. Khi VAD phát hiện im lặng > 1.5s → Ngắt stream, gửi END marker
```

**Thư viện cần:**
- ESP-IDF: `esp_websocket_client` (có sẵn trong ESP-IDF 5.x)
- Opus: `libopus` ported cho ESP32 (dùng `opus-1.4` compiled for Xtensa)

**Chi tiết kỹ thuật Opus trên ESP32-S3:**

| Thông số | Giá trị | Lý do |
|---|---|---|
| Sample Rate | 16000 Hz | ASR standard |
| Channels | 1 (Mono) | Mic INMP441 đơn |
| Frame Size | 320 samples (20ms) | Opus standard frame |
| Bitrate | 16 kbps | Cân bằng chất lượng/bandwidth |
| Complexity | 0-2 | ESP32 CPU limited |
| Application | OPUS_APPLICATION_VOIP | Tối ưu cho giọng nói |

**Bandwidth tính toán:**
- PCM raw: 16000 × 16bit × 1ch = 256 kbps
- Opus 16kbps: **giảm 16x** → phù hợp Wi-Fi nội bộ

### 1.2 Pi 4 — WebSocket Audio Server

```python
# /home/pi4/smarthome/gateway/audio_server.py

# WebSocket server tại ws://0.0.0.0:8765/audio
# Flow:
# 1. Nhận Opus frames từ ESP32-S3
# 2. Decode Opus → PCM 16kHz/16bit
# 3. Chạy VAD (Silero VAD hoặc WebRTC VAD) để phát hiện câu nói hoàn chỉnh
# 4. Khi VAD phát hiện end-of-speech:
#    a. Buffer PCM → Gửi tới Sherpa-ONNX ASR
#    b. Nhận text → Gửi tới LLM Intent Extraction
#    c. Nhận JSON intent → Dispatch command qua MQTT
#    d. Generate voice reply qua EdgeTTS
#    e. Encode reply TTS audio → Opus → Gửi về ESP32-S3 qua WebSocket
```

### 1.3 Sherpa-ONNX ASR (Speech-to-Text Vietnamese)

**Model lựa chọn:** `sherpa-onnx-streaming-zipformer-ctc-small-2024-03-18` (Vietnamese)

**Cài đặt trên Pi 4:**

```bash
# Trong venv
pip install sherpa-onnx

# Download Vietnamese model
cd /home/pi4/smarthome/models/
wget https://github.com/k2-fsa/sherpa-onnx/releases/download/asr-models/sherpa-onnx-streaming-zipformer-ctc-small-2024-03-18.tar.bz2
tar xf sherpa-onnx-streaming-zipformer-ctc-small-2024-03-18.tar.bz2
```

**Tích hợp:**

```python
# /home/pi4/smarthome/gateway/asr_engine.py

import sherpa_onnx

def create_recognizer():
    return sherpa_onnx.OnlineRecognizer.from_transducer(
        tokens="models/tokens.txt",
        encoder="models/encoder.onnx",
        decoder="models/decoder.onnx",
        joiner="models/joiner.onnx",
        num_threads=2,           # Pi 4 có 4 cores, dành 2 cho ASR
        sample_rate=16000,
        feature_dim=80,
        decoding_method="greedy_search",
    )
```

**Latency mục tiêu:** < 500ms cho câu 3-5 giây

### 1.4 LLM Intent Extraction (Qwen2.5-1.5B)

**Đã có prompt tối ưu** từ `cli_json.sh`. Tích hợp thành Python module:

```python
# /home/pi4/smarthome/gateway/intent_engine.py

import httpx
import json

LLAMA_URL = "http://127.0.0.1:8080/completion"

SYSTEM_PROMPT = """Bạn là bộ phân tích lệnh cho Nhà Thông Minh IoT.
Nhiệm vụ: Phân tích khẩu lệnh thành JSON.
... (prompt đã test ổn định)
"""

async def extract_intent(user_text: str) -> dict:
    """
    Input:  "Bật đèn ngủ phòng ngủ"
    Output: {"voice_reply":"Đã bật đèn ngủ phòng ngủ ạ",
             "command":{"action":"turn_on","device":"den_ngu","location":"phong_ngu"}}
    """
    payload = {
        "prompt": f"<|im_start|>system\n{SYSTEM_PROMPT}<|im_end|>\n"
                  f"<|im_start|>user\n{user_text}<|im_end|>\n"
                  f"<|im_start|>assistant\n",
        "n_predict": 200,
        "temperature": 0.1,
        "stop": ["<|im_end|>"],
    }
    async with httpx.AsyncClient() as client:
        resp = await client.post(LLAMA_URL, json=payload, timeout=15.0)
        return json.loads(resp.json()["content"])
```

**Latency mục tiêu:** < 3 giây (đã benchmark ~3.5 t/s generation)

### 1.5 EdgeTTS — Text-to-Speech Output

```python
# /home/pi4/smarthome/gateway/tts_engine.py

import edge_tts
import asyncio

VOICE = "vi-VN-HoaiMyNeural"  # Giọng nữ Việt Nam tự nhiên

async def synthesize_speech(text: str) -> bytes:
    """
    Input:  "Đã bật đèn ngủ phòng ngủ ạ"
    Output: PCM audio bytes (16kHz, 16-bit, mono)
    """
    communicate = edge_tts.Communicate(text, VOICE)
    audio_bytes = b""
    async for chunk in communicate.stream():
        if chunk["type"] == "audio":
            audio_bytes += chunk["data"]
    # EdgeTTS trả về MP3 → cần decode sang PCM
    return convert_mp3_to_pcm(audio_bytes)
```

**Cài đặt:** `pip install edge-tts`

**Lưu ý:** EdgeTTS cần Internet (gọi Microsoft Azure). Nếu cần offline → fallback sang `piper-tts`.

### 1.6 Voice Pipeline — Full Flow Tổng Hợp

```
┌──────────────────────────────── FULL VOICE PIPELINE ─────────────────────────────────┐
│                                                                                      │
│  User: "Hi ESP"                                                                      │
│       │                                                                              │
│       ▼                                                                              │
│  [1] WakeNet Detect (ESP32-S3, local, ~0ms)                                          │
│       │                                                                              │
│       ▼                                                                              │
│  [2] I2S Mic → Opus Encode → WebSocket → Pi 4  (~20ms per frame)                     │
│       │                                                                              │
│       ▼                                                                              │
│  [3] Opus Decode → VAD → Buffer until silence (~50ms processing)                     │
│       │                                                                              │
│       ▼                                                                              │
│  [4] Sherpa-ONNX ASR: PCM → Vietnamese Text  (~300-500ms)                            │
│       │                                                                              │
│       ▼                                                                              │
│  [5] Qwen2.5-1.5B: Text → JSON Intent  (~2-4s)                                      │
│       │                                                                              │
│       ├──► [6a] MQTT Publish: command/{node_id} → ESP32 Relay  (~50ms)               │
│       │                                                                              │
│       └──► [6b] EdgeTTS: voice_reply → MP3 → PCM → Opus → WS → ESP32 (~1-2s)        │
│                                                                                      │
│  TỔNG LATENCY MỤC TIÊU: 3-6 giây từ khi nói xong đến khi nghe phản hồi             │
└──────────────────────────────────────────────────────────────────────────────────────────┘
```

**Files cần tạo (Phase 1):**

```
/home/pi4/smarthome/
├── gateway/
│   ├── __init__.py
│   ├── main.py                   # Entry point — asyncio event loop
│   ├── audio_server.py           # WebSocket server cho audio streaming
│   ├── asr_engine.py             # Sherpa-ONNX wrapper
│   ├── intent_engine.py          # LLM intent extraction
│   ├── tts_engine.py             # EdgeTTS wrapper
│   ├── mqtt_handler.py           # MQTT publish/subscribe
│   ├── registry_manager.py       # Device registry CRUD
│   └── config.py                 # Cấu hình tập trung
├── models/
│   └── sherpa-onnx-*/            # ASR model files
├── device_registry.json
└── requirements.txt
```

---

## Phase 2 — Closed-Loop Control (Vòng Kín Điều Khiển)

> **🎯 Checkpoint:** Đây là TRÁI TIM của mục tiêu cốt lõi. Hệ thống không chỉ ra lệnh mà phải KIỂM CHỨNG — lệnh bật đèn gửi rồi, nhưng đèn có thực sự sáng không? Đây chính là "closed-loop" phân biệt hệ thống thông minh với hệ thống ngu.

### 2.1 Verify-After-Command (Xác Nhận Sau Lệnh)

```
[Gateway gửi lệnh "turn_on ch1"] 
    → MQTT → [ESP32 WROOM bật relay ch1]
    → [PZEM-004T đo dòng điện thay đổi]
    → MQTT telemetry → [Gateway so sánh]
    
    Nếu power_delta > ngưỡng (e.g., >5W) → ✅ Xác nhận thành công
    Nếu power_delta ≈ 0 sau 3 giây       → ❌ Thiết bị có vấn đề!
        → Thông báo user qua EdgeTTS: "Đèn ngủ phòng ngủ có vẻ bị hỏng bóng, 
          em đã bật công tắc nhưng không thấy tiêu thụ điện."
```

```python
# /home/pi4/smarthome/gateway/verify_engine.py

class CommandVerifier:
    """
    Sau khi gửi lệnh, chờ telemetry feedback trong 5 giây.
    So sánh power trước/sau để xác nhận thiết bị thực sự hoạt động.
    """
    
    async def verify_command(self, node_id, channel, action, rated_watts):
        # 1. Ghi nhận power hiện tại
        before_power = self.get_current_power(node_id)
        
        # 2. Gửi lệnh
        await self.mqtt.publish(
            f"smarthome/command/{node_id}", 
            {"channel": channel, "action": action}
        )
        
        # 3. Chờ 3 giây, đọc lại telemetry
        await asyncio.sleep(3.0)
        after_power = self.get_current_power(node_id)
        
        # 4. Phân tích
        delta = after_power - before_power
        
        if action == "turn_on":
            if delta > rated_watts * 0.3:  # >30% công suất định mức
                return VerifyResult.SUCCESS
            elif delta > 0:
                return VerifyResult.PARTIAL  # Hoạt động yếu
            else:
                return VerifyResult.FAILED   # Không phản hồi
        elif action == "turn_off":
            if delta < -rated_watts * 0.3:
                return VerifyResult.SUCCESS
            else:
                return VerifyResult.FAILED
```

### 2.2 Anomaly Detection (Phát Hiện Bất Thường)

**Trường hợp bất thường cần phát hiện:**

| # | Tình huống | Cách phát hiện | Hành động |
|---|---|---|---|
| 1 | Thiết bị bật không có lệnh | `relay_state` chuyển ON nhưng không có command log | Cảnh báo user |
| 2 | Tiêu thụ vượt mức | `current_power > historical_avg * 1.5` | Cảnh báo + gợi ý tắt |
| 3 | Thiết bị chạy quá lâu | `on_duration > threshold` (e.g., điều hòa >8h) | Nhắc nhở tắt |
| 4 | Mất tín hiệu Node | `last_seen > 60 giây` | Cảnh báo mất kết nối |
| 5 | Dòng rò / Standby | `power > 0` khi tất cả relay OFF | Cảnh báo rò điện |

```python
# /home/pi4/smarthome/gateway/anomaly_engine.py

class AnomalyDetector:
    """
    Chạy liên tục (mỗi 10 giây), quét telemetry từ tất cả nodes.
    So sánh với baseline + command history để phát hiện bất thường.
    """
    
    async def scan(self):
        for node_id, node in self.registry.items():
            telemetry = self.latest_telemetry[node_id]
            
            # Case 1: Unauthorized activation
            if telemetry.relay_on and not self.command_log.has_recent_on(node_id):
                await self.alert("unauthorized_activation", node_id)
            
            # Case 2: Over-consumption
            baseline = self.memory.get_baseline_power(node_id)
            if telemetry.power > baseline * 1.5 and baseline > 10:
                await self.alert("over_consumption", node_id, 
                                 actual=telemetry.power, expected=baseline)
            
            # Case 3: Extended runtime
            on_duration = self.get_on_duration(node_id)
            max_duration = node.get("max_runtime_hours", 8)
            if on_duration > max_duration * 3600:
                await self.alert("extended_runtime", node_id,
                                 hours=on_duration/3600)
```

### 2.3 Telemetry Pipeline

```
[ESP32 WROOM]  ──MQTT──►  [Gateway]  ──write──►  [InfluxDB]
    │                        │                        │
    │ mỗi 2 giây             │ real-time cache        │ historical data
    │                        │                        │
    └── smarthome/           └── verify_engine        └── Grafana Dashboard
        telemetry/               anomaly_engine            (query 7d/30d/1y)
        {node_id}
```

**InfluxDB Schema:**

```
Measurement: device_telemetry
Tags:        node_id, area, device_type, channel
Fields:      voltage, current, power, energy, frequency, pf, relay_state
Timestamp:   nanosecond precision
```

**Files cần tạo (Phase 2):**

```
/home/pi4/smarthome/gateway/
├── verify_engine.py              # Command verification
├── anomaly_engine.py             # Anomaly detection
├── telemetry_writer.py           # InfluxDB writer
└── command_log.py                # Lịch sử lệnh (SQLite)
```

---

## Phase 3 — Memory & Learning (Bộ Nhớ & Tự Học)

> **🎯 Checkpoint:** Phase này biến hệ thống từ "thực thi lệnh" thành "HIỂU NGƯỜI DÙNG". Không có memory thì không có learning. Không có learning thì không bao giờ tự hành được. Đây là bước THEN CHỐT.

### 3.1 Memory Architecture

```python
# /home/pi4/smarthome/gateway/memory_engine.py

"""
Memory Engine gồm 3 tầng:

1. Short-Term Memory (STM) — RAM Cache
   - Telemetry 5 phút gần nhất
   - Context hội thoại hiện tại
   - Trạng thái relay real-time
   
2. Medium-Term Memory (MTM) — SQLite
   - Command history (ai bật gì, khi nào, kết quả verify)
   - Daily usage patterns (giờ bật/tắt từng thiết bị)
   - User corrections ("không, tôi muốn tắt đèn BAN CÔNG, không phải đèn ngủ")
   
3. Long-Term Memory (LTM) — InfluxDB + SQLite
   - Baseline power profiles (trung bình tiêu thụ mỗi thiết bị theo giờ/ngày/mùa)
   - User preference model (thói quen lặp đi lặp lại >5 lần = pattern)
   - Seasonal adjustment (mùa hè dùng điều hòa nhiều hơn)
"""

class MemoryEngine:
    def __init__(self):
        self.stm = ShortTermMemory()     # dict trong RAM
        self.mtm = MediumTermMemory()    # SQLite
        self.ltm = LongTermMemory()      # InfluxDB queries + SQLite
    
    async def record_command(self, intent, verify_result, timestamp):
        """Ghi lại mỗi lệnh + kết quả verification"""
        self.mtm.insert_command_log(
            user_text=intent["user_text"],
            action=intent["action"],
            device=intent["device"],
            area=intent["location"],
            verify_result=verify_result,
            timestamp=timestamp,
            hour=timestamp.hour,
            day_of_week=timestamp.weekday(),
        )
    
    async def record_correction(self, original_intent, corrected_intent):
        """Khi user sửa lệnh sai → ghi nhận để cải thiện prompt"""
        self.mtm.insert_correction(original_intent, corrected_intent)
    
    def get_daily_pattern(self, device, area, day_of_week):
        """Lấy pattern: device X ở area Y thường bật lúc mấy giờ ngày thứ mấy"""
        return self.mtm.query_pattern(device, area, day_of_week)
```

### 3.2 SQLite Schema (Medium-Term Memory)

```sql
-- /home/pi4/smarthome/memory.db

-- Lịch sử lệnh
CREATE TABLE command_log (
    id INTEGER PRIMARY KEY AUTOINCREMENT,
    timestamp TEXT NOT NULL,
    hour INTEGER NOT NULL,
    day_of_week INTEGER NOT NULL,
    user_text TEXT,
    action TEXT NOT NULL,
    device TEXT NOT NULL,
    area TEXT NOT NULL,
    node_id TEXT,
    channel TEXT,
    verify_result TEXT,  -- 'success', 'partial', 'failed'
    power_before REAL,
    power_after REAL
);

-- Sửa lỗi của user (dùng để fine-tune prompt/behavior)
CREATE TABLE user_corrections (
    id INTEGER PRIMARY KEY AUTOINCREMENT,
    timestamp TEXT NOT NULL,
    original_text TEXT,
    original_device TEXT,
    original_area TEXT,
    corrected_device TEXT,
    corrected_area TEXT,
    notes TEXT
);

-- Patterns tự học (được tính toán từ command_log)
CREATE TABLE learned_patterns (
    id INTEGER PRIMARY KEY AUTOINCREMENT,
    pattern_type TEXT NOT NULL,  -- 'daily_routine', 'weekday_habit', 'seasonal'
    device TEXT NOT NULL,
    area TEXT NOT NULL,
    action TEXT NOT NULL,
    trigger_hour INTEGER,
    trigger_day_of_week INTEGER,  -- NULL = mỗi ngày
    confidence REAL DEFAULT 0.0,  -- 0.0 ~ 1.0
    occurrence_count INTEGER DEFAULT 0,
    last_occurred TEXT,
    is_active BOOLEAN DEFAULT 1,
    created_at TEXT NOT NULL
);

-- Baseline điện năng (tính trung bình từ InfluxDB)
CREATE TABLE power_baselines (
    id INTEGER PRIMARY KEY AUTOINCREMENT,
    node_id TEXT NOT NULL,
    channel TEXT NOT NULL,
    device_type TEXT NOT NULL,
    avg_watts REAL,
    max_watts REAL,
    min_watts REAL,
    measurement_count INTEGER,
    last_updated TEXT
);

-- Index tối ưu query
CREATE INDEX idx_cmd_device_area ON command_log(device, area, hour);
CREATE INDEX idx_patterns_active ON learned_patterns(is_active, trigger_hour);
```

### 3.3 Learning Algorithm (Thuật Toán Tự Học)

```python
# /home/pi4/smarthome/gateway/learning_engine.py

class PatternLearner:
    """
    Chạy mỗi ngày lúc 3:00 AM (cron job).
    Phân tích command_log → Tìm patterns lặp lại → Lưu vào learned_patterns.
    
    Quy tắc confidence:
    - Lặp lại >= 5 lần trong 7 ngày liên tiếp  → confidence = 0.7
    - Lặp lại >= 14 lần trong 21 ngày           → confidence = 0.85
    - Lặp lại >= 30 lần trong 30 ngày            → confidence = 0.95
    - User xác nhận pattern                      → confidence = 1.0
    - User từ chối pattern                       → confidence = 0.0, is_active = False
    """
    
    async def analyze_daily(self):
        # 1. Query command_log 30 ngày gần nhất
        recent_commands = self.db.query("""
            SELECT device, area, action, hour, day_of_week, COUNT(*) as cnt
            FROM command_log
            WHERE timestamp > datetime('now', '-30 days')
            AND verify_result = 'success'
            GROUP BY device, area, action, hour
            HAVING cnt >= 5
            ORDER BY cnt DESC
        """)
        
        # 2. Với mỗi pattern tìm được
        for cmd in recent_commands:
            existing = self.db.get_pattern(
                cmd.device, cmd.area, cmd.action, cmd.hour
            )
            if existing:
                # Cập nhật confidence
                existing.occurrence_count = cmd.cnt
                existing.confidence = self.calculate_confidence(
                    cmd.cnt, existing.created_at
                )
                self.db.update_pattern(existing)
            else:
                # Tạo pattern mới
                self.db.insert_pattern(
                    pattern_type="daily_routine",
                    device=cmd.device,
                    area=cmd.area,
                    action=cmd.action,
                    trigger_hour=cmd.hour,
                    confidence=0.5,  # Khởi đầu thận trọng
                    occurrence_count=cmd.cnt,
                )
    
    def calculate_confidence(self, count, created_at):
        days_active = (now() - created_at).days
        if days_active < 7:
            return min(0.6, count / 10)
        elif days_active < 21:
            return min(0.85, count / 20)
        else:
            return min(0.95, count / 30)
```

---

## Phase 4 — Proactive Intelligence (Trí Tuệ Chủ Động)

> **🎯 Checkpoint:** Đây là ĐỈNH CAO của mục tiêu cốt lõi. Hệ thống không chờ lệnh nữa — nó CHỦ ĐỘNG hành động dựa trên patterns đã học. Từ "smart" chuyển thành "autonomous". Nhưng PHẢI CÓ CƠ CHẾ AN TOÀN để tránh hành động sai.

### 4.1 Proactive Action Engine

```python
# /home/pi4/smarthome/gateway/proactive_engine.py

class ProactiveEngine:
    """
    Chạy mỗi phút (cron), kiểm tra:
    1. Có pattern nào đến giờ trigger không?
    2. Confidence có đủ cao để tự động không?
    3. Thiết bị có đang ở trạng thái cần thay đổi không?
    
    CƠ CHẾ AN TOÀN 3 CẤP:
    - confidence < 0.7  → Chỉ GỢI Ý qua voice (hỏi user)
    - confidence 0.7~0.9 → Tự động nhưng THÔNG BÁO voice
    - confidence > 0.9   → Tự động IM LẶNG (chỉ log)
    - User từ chối 2 lần → Tạm dừng pattern 7 ngày
    """
    
    async def check_and_act(self):
        current_hour = datetime.now().hour
        current_dow = datetime.now().weekday()
        
        patterns = self.memory.get_active_patterns(
            trigger_hour=current_hour,
            trigger_day_of_week=current_dow
        )
        
        for pattern in patterns:
            device_state = self.registry.get_device_state(
                pattern.device, pattern.area
            )
            
            # Kiểm tra xem action có cần thiết không
            if pattern.action == "turn_on" and device_state == "on":
                continue  # Đã bật rồi, skip
            if pattern.action == "turn_off" and device_state == "off":
                continue  # Đã tắt rồi, skip
            
            if pattern.confidence < 0.7:
                # CẤP 1: GỢI Ý — hỏi user
                await self.suggest_via_voice(
                    f"Theo thói quen, bạn thường "
                    f"{self.action_to_text(pattern)} "
                    f"vào lúc này. Bạn có muốn em thực hiện không?"
                )
            elif pattern.confidence < 0.9:
                # CẤP 2: TỰ ĐỘNG + THÔNG BÁO
                await self.execute_and_notify(pattern)
            else:
                # CẤP 3: TỰ ĐỘNG IM LẶNG
                await self.execute_silently(pattern)
```

### 4.2 Proactive Scenarios (Kịch Bản Chủ Động)

| # | Kịch bản | Trigger | Hành động | Confidence cần |
|---|---|---|---|---|
| 1 | Sáng bật đèn phòng | 6:30 AM hàng ngày | Bật đèn trần phòng ngủ | > 0.7 |
| 2 | Tối tắt đèn sân | 11:00 PM hàng ngày | Tắt đèn sân vườn | > 0.7 |
| 3 | Quên tắt điều hòa | Chạy > 8 giờ liên tục | Voice nhắc | Anomaly |
| 4 | Tiêu thụ bất thường | Power > 150% baseline | Voice cảnh báo | Anomaly |
| 5 | Thiết bị bật không lệnh | Relay ON, no command | Voice hỏi | Anomaly |
| 6 | Báo cáo tổng kết ngày | 9:00 PM hàng ngày | Voice tổng kết | Always |

### 4.3 Qwen LLM — Context-Aware Analysis

Ngoài intent extraction, LLM còn được dùng để **phân tích dữ liệu** mỗi ngày:

```python
# Prompt cho daily analysis (chạy lúc 9 PM)
DAILY_ANALYSIS_PROMPT = """
Bạn là chuyên gia phân tích điện năng nhà thông minh.
Dữ liệu hôm nay:
{daily_telemetry_summary}

Lịch sử 7 ngày:
{weekly_trend}

Patterns đã học:
{active_patterns}

Nhiệm vụ:
1. Tóm tắt tình trạng sử dụng điện hôm nay (1-2 câu)
2. So sánh với 7 ngày trước (tăng/giảm bao nhiêu %)  
3. Nếu có bất thường, chỉ ra cụ thể
4. Gợi ý 1 mẹo tiết kiệm điện (nếu có)

Trả lời bằng tiếng Việt, ngắn gọn, thân thiện, phát qua loa.
"""
```

---

## Phase 5 — MCP Integration & Ecosystem

> **🎯 Checkpoint:** MCP (Model Context Protocol) mở rộng khả năng của LLM bằng cách cho phép nó GỌI CÁC TOOL bên ngoài — truy vấn Home Assistant, đọc thời tiết, kiểm tra lịch. Điều này giúp LLM "nhận thức" hơn khi ra quyết định.

### 5.1 MCP Server Architecture

```python
# /home/pi4/smarthome/mcp/smarthome_mcp_server.py

"""
MCP Server expose các Tools cho LLM:

1. get_device_status(area, device) → Trạng thái thiết bị
2. get_power_consumption(area, timerange) → Tiêu thụ điện  
3. control_device(area, device, action) → Điều khiển thiết bị
4. get_daily_report() → Báo cáo tổng kết
5. get_weather() → Thời tiết (external API)
6. search_command_history(query) → Tìm lịch sử lệnh
"""

from mcp.server import Server
from mcp.types import Tool

server = Server("smarthome-mcp")

@server.tool()
async def get_device_status(area: str, device: str) -> str:
    """Lấy trạng thái hiện tại của thiết bị"""
    node = registry.find_node(area, device)
    telemetry = latest_telemetry[node.id]
    return (
        f"{device} tại {area}: "
        f"{'BẬT' if telemetry.relay_on else 'TẮT'}, "
        f"công suất {telemetry.power}W"
    )

@server.tool()  
async def control_device(area: str, device: str, action: str) -> str:
    """Điều khiển thiết bị (bật/tắt)"""
    result = await gateway.execute_command(area, device, action)
    return f"Đã {action} {device} tại {area}. Kết quả: {result}"
```

### 5.2 Home Assistant Integration

```yaml
# Home Assistant configuration.yaml additions

mqtt:
  switch:
    - name: "Đèn Ngủ Phòng Ngủ"
      state_topic: "smarthome/status/esp32_wroom_01"
      command_topic: "smarthome/command/esp32_wroom_01"
      value_template: "{{ value_json.ch1 }}"
      payload_on: '{"channel":"ch1","action":"turn_on"}'
      payload_off: '{"channel":"ch1","action":"turn_off"}'
      
  sensor:
    - name: "Công Suất Phòng Ngủ"  
      state_topic: "smarthome/telemetry/esp32_wroom_01"
      unit_of_measurement: "W"
      value_template: "{{ value_json.power }}"
```

---

## Phase 6 — Dashboard & User Experience

> **🎯 Checkpoint:** Dashboard không phải mục tiêu cốt lõi, nhưng là GIAO DIỆN QUAN SÁT duy nhất để user theo dõi hệ thống đang "học" gì, "làm" gì. Thiếu dashboard = user mất niềm tin = dự án thất bại.

### 6.1 Grafana Dashboard

- **Panel 1:** Real-time power consumption (all nodes)
- **Panel 2:** Daily/Weekly energy trend
- **Panel 3:** Device activity timeline (khi nào bật/tắt)
- **Panel 4:** Anomaly alerts feed
- **Panel 5:** Learned patterns (hiển thị những gì hệ thống đã học)

### 6.2 Web Dashboard (Custom)

Tạo web UI tại `http://192.168.11.29:3000`:
- Đăng ký node mới (drag & drop floor plan)
- Xem trạng thái real-time
- Quản lý learned patterns (approve/reject)
- Voice log history

---

## Verification & Testing Strategy

### Mỗi Phase phải pass những test sau:

| Phase | Test | Criteria |
|---|---|---|
| 0 | Registry CRUD | Thêm/sửa/xóa node thành công |
| 0 | MQTT Ping | ESP32 → EMQX → Gateway roundtrip < 100ms |
| 1 | Audio Stream | Opus encode/decode không mất frame |
| 1 | ASR Accuracy | > 80% accuracy trên 50 câu tiếng Việt thường dùng |
| 1 | Intent JSON | > 90% parse đúng trên 30 câu test |
| 1 | End-to-End Voice | Nói "bật đèn ngủ" → đèn bật + voice reply < 6 giây |
| 2 | Verify Engine | Phát hiện đúng khi bật relay nhưng không có load |
| 2 | Anomaly Detect | Phát hiện thiết bị bật không có lệnh trong 10 giây |
| 3 | Pattern Learning | Sau 7 ngày test, hệ thống tìm ra ≥1 pattern đúng |
| 4 | Proactive Action | Hệ thống tự gợi ý/thực hiện action đúng thời điểm |
| 5 | MCP Tools | LLM gọi được get_device_status, control_device |

---

## Rủi Ro & Giải Pháp

| # | Rủi ro | Xác suất | Tác động | Giải pháp |
|---|---|---|---|---|
| 1 | Pi 4 hết RAM (4GB) khi chạy đồng thời LLM + ASR + Docker | 🔴 Cao | 🔴 Crash | Giới hạn LLM context 512 tokens, ASR dùng small model, swap 2GB |
| 2 | Opus encode trên ESP32-S3 quá chậm | 🟡 TB | 🟡 Lag | Dùng complexity=0, frame 20ms, test trước |
| 3 | Sherpa-ONNX nhận sai tiếng Việt | 🟡 TB | 🟡 Lệnh sai | Hotword boosting, test extensive |
| 4 | EdgeTTS mất Internet | 🟡 TB | 🟡 Mất voice | Fallback: piper-tts offline |
| 5 | Qwen2.5 hiểu sai intent phức tạp | 🟡 TB | 🟡 Lệnh sai | Prompt engineering + correction loop |
| 6 | MQTT broker crash | 🟢 Thấp | 🔴 Mất ĐK | EMQX tự restart, ESP-NOW fallback |
| 7 | Proactive action sai | 🟡 TB | 🔴 Mất tin | Conservative confidence, ask-first mode |

---

## Timeline Dự Kiến

```
┌─────────────────────────────────────────────────────────────────┐
│  TUẦN 1-2: Phase 0 (Foundation)                                │
│  ├── Device Registry + MQTT Topics                             │
│  ├── ESP32 WROOM firmware: MQTT client                         │
│  └── Gateway skeleton (Python asyncio)                         │
│                                                                 │
│  TUẦN 3-4: Phase 1 (Voice Pipeline)                            │
│  ├── Opus encode trên ESP32-S3                                 │
│  ├── WebSocket audio server trên Pi                            │
│  ├── Sherpa-ONNX ASR integration                               │
│  ├── LLM intent engine (đã có prompt)                          │
│  └── EdgeTTS voice reply                                       │
│                                                                 │
│  TUẦN 5-6: Phase 2 (Closed-Loop)                               │
│  ├── Verify engine (command → telemetry feedback)              │
│  ├── Anomaly detection engine                                  │
│  ├── Telemetry pipeline → InfluxDB                             │
│  └── 🎯 MILESTONE: Nói "bật đèn" → đèn bật + xác nhận        │
│                                                                 │
│  TUẦN 7-8: Phase 3 (Memory & Learning)                         │
│  ├── SQLite memory schema                                      │
│  ├── Command logging + correction recording                    │
│  └── Pattern learning algorithm (daily cron)                   │
│                                                                 │
│  TUẦN 9-10: Phase 4 (Proactive Intelligence)                   │
│  ├── Proactive action engine                                   │
│  ├── Daily analysis report (LLM + EdgeTTS)                     │
│  └── 🎯 MILESTONE: Hệ thống tự gợi ý/thực hiện lần đầu       │
│                                                                 │
│  TUẦN 11-12: Phase 5-6 (MCP + Dashboard)                       │
│  ├── MCP server + Home Assistant integration                   │
│  ├── Grafana dashboards                                        │
│  └── 🎯 MILESTONE: Hệ thống hoàn chỉnh, tự vận hành          │
└─────────────────────────────────────────────────────────────────┘
```

---

## File Structure Tổng Thể

```
/home/pi4/smarthome/
├── gateway/
│   ├── __init__.py
│   ├── main.py                   # Entry point (asyncio)
│   ├── config.py                 # Tất cả config tập trung
│   ├── audio_server.py           # WebSocket audio streaming
│   ├── asr_engine.py             # Sherpa-ONNX ASR
│   ├── intent_engine.py          # Qwen2.5 LLM intent extraction
│   ├── tts_engine.py             # EdgeTTS voice output
│   ├── mqtt_handler.py           # MQTT pub/sub
│   ├── registry_manager.py       # Device registry CRUD
│   ├── verify_engine.py          # Closed-loop verification
│   ├── anomaly_engine.py         # Anomaly detection
│   ├── telemetry_writer.py       # InfluxDB writer
│   ├── command_log.py            # SQLite command history
│   ├── memory_engine.py          # 3-tier memory system
│   ├── learning_engine.py        # Pattern learning algorithm
│   └── proactive_engine.py       # Proactive action engine
├── mcp/
│   └── smarthome_mcp_server.py   # MCP Tools for LLM
├── models/
│   ├── qwen2.5-1.5b-instruct-q4_k_m.gguf
│   └── sherpa-onnx-*/            # ASR model files
├── device_registry.json
├── memory.db                     # SQLite memory database
├── requirements.txt
├── docker-compose.yml            # EMQX, InfluxDB, Grafana, HA
└── systemd/
    ├── smarthome-gateway.service # Auto-start gateway
    └── llama-server.service      # Auto-start LLM server
```

```
d:/Home-Assistant-IoT-/
├── Firmware/
│   └── firmware_esp/
│       ├── Esp32S3_Master/       # Voice Node (I2S + WakeNet + Opus + WS)
│       └── Esp32_Wroom_Slave/    # Relay Node (PZEM + Relay + MQTT)
├── Gateway/                      # Mirror of Pi gateway code (Git sync)
├── App/                          # Mobile app (future)
├── Web/                          # Web dashboard (future)
└── plan.md                       # ← FILE NÀY
```

---

> ## 🎯 NHẮC LẠI MỤC TIÊU CỐT LÕI (đọc lại trước khi code bất kỳ dòng nào)
>
> **"Xây dựng hệ thống nhà thông minh TỰ HÀNH & NHẬN THỨC, lấy dữ liệu điện năng làm PHẢN HỒI VÒNG KÍN để TỰ HỌC thói quen người dùng và CHỦ ĐỘNG điều khiển."**
>
> - Mỗi Phase phải hoàn thành **test criteria** trước khi chuyển Phase tiếp theo.
> - Nếu một Phase bị delay, **KHÔNG** skip — mọi Phase sau phụ thuộc Phase trước.
> - Khi bị mất phương hướng → Đọc lại mục tiêu cốt lõi → Tự hỏi: "Dòng code này có giúp hệ thống TỰ HỌC và CHỦ ĐỘNG hơn không?"

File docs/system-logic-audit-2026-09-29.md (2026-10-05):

# Rà soát logic và hiệu năng hệ thống

Ngày: 2026-09-29. Phạm vi: code hiện hành của Gateway, ActionBox và SubBox;
không xét archive. Không sửa code chạy, không flash, không gửi lệnh tới thiết bị.

**Kết luận:** Có lỗi về quyền sở hữu bộ nhớ, tính đúng của lệnh, giao thức giữa
các tầng và xác nhận trạng thái. Cần xử lý chúng trước các tối ưu nhỏ về chuỗi
hay tốc độ parser. Build thành công và test NLU Gateway đạt không chứng minh
luồng điều khiển ba tầng hoạt động đúng.
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

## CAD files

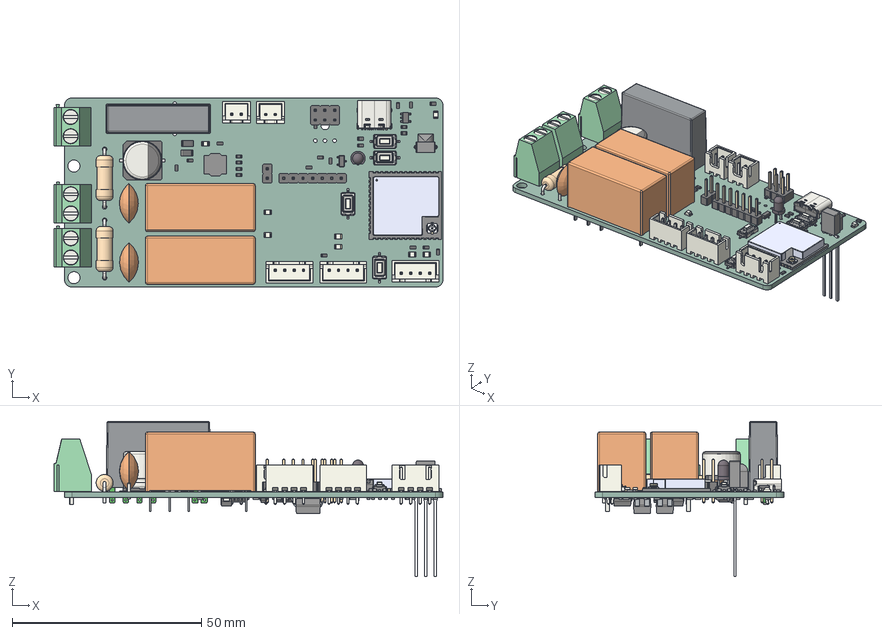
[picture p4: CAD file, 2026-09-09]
Hardware/CAD/IoT_Board.step
102.8 x 50.0 x 41.0 mm
R_0603_1608Metric x 59
R_1206_3216Metric x 2
PinHeader_2x03_P254mm_Vertical
PTS636Sx25SMTRLFS x 4
CP_Elec_10x105
Relay_DPDT_Schrack-RT2-FormC_RM5mm x 2
LED_D3.0mm_IRBlack
JST_B2B_XH_A x 2
JST_B4B_XH_A x 3
R_Axial_DIN0414_L119mm_D45mm_P1524mm_Horizontal x 2
USB_C_Receptacle_16P_TopMnt_Horizontal_GCT_USB4105-xx-A
TerminalBlock_Phoenix_MKDS-1,5-2-5.08_1x02_P5.08mm_Horizontal x 3
C_Disc_D105mm_W50mm_P750mm x 2
LED_0805_2012Metric x 8
PinHeader_1x02_P254mm_Vertical
SOT-23-5
L_Bourns_SRN6045TA
VS1838B
ESP32-S3-WROOM-1U-N16R8
PinHeader_1x07_P254mm_Vertical
SOT-23 x 3
SSOP-10_3.9x4.9mm_P1.00mm x 2
PinsArrayLR x 2
D_SMA x 2
R_0805_2012Metric
IoT5C8E_PCB

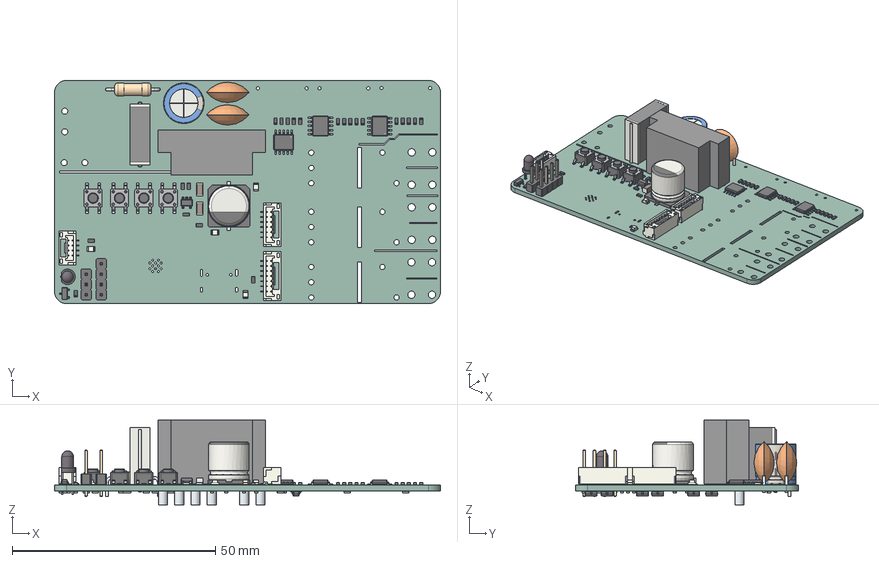
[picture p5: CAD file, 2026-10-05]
Hardware/PCB/IoT_Board_V2/IoT_Board_V2.step
95.0 x 55.0 x 20.8 mm
C_Disc_D105mm_W50mm_P750mm x 2
CP_Elec_10x105
LED_0805_2012Metric x 4
SSOP-10_3.9x4.9mm_P1.00mm x 3
R_0603_1608Metric x 58
JST_BM07B_GHS_TBT
SOT-23 x 7
PinHeader_1x04_P254mm_Vertical
CP_Radial_D100mm_P500mm
SW_SPST_TL3305A x 4
C_1206_3216Metric x 2
LED_D3.0mm_IRBlack
Leads
JST_BM06B_GHS_TBT
R_Axial_DIN0309_L90mm_D32mm_P1270mm_Horizontal
PinHeader_1x03_P254mm_Vertical
SOT-23-5
JST_BM04B_GHS_TBT
C_Rect_L165mm_W50mm_P1500mm_MKT
R_0805_2012Metric
IoTB7F1_PCB

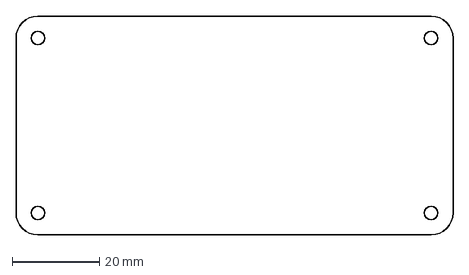
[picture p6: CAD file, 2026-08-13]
Hardware/PCB/manager_board/manager_shape.DXF
100.0 x 50.0 mm

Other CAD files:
Hardware/PCB/IoT_Board/IoT_Board.SLDASM
Hardware/PCB/IoT_Board_V2/IoT_Board_V2.SLDASM

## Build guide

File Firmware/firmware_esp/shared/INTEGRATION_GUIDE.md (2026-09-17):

# Firmware tích hợp Compact Protocol (WebSocket + MQTT)

## Tóm tắt
ESP32-S3 (voice) đã giữ **1 WS tới Pi4:8765** cho mic PCM. Relay bây giờ đi **chung socket đó**
bằng TEXT frame `{"t":"rl","ch":1,"s":1,"seq":n}` (~27B) — không mở thêm socket, không vỡ luồng mic.
Node relay thuần (WROOM) không có WS vẫn dùng MQTT `smarthome/cmd/{id}` với cùng payload.

Firmware mẫu nằm ở `shared/node_prov.{h,c}` — dùng chung cho mọi node. Chỉ cần copy 2 file
vào `Esp32S3_Master/include` & `src` (và WROOM project tương tự) + thêm 3 patch dưới đây.

---

## 1) Tích hợp NVS provision (boot)

Trong `main.c` — trước khi gọi `mqtt_relay_init` / `ws_audio_client_init`:

```c
#include "node_prov.h"

void app_main(void) {
    nvs_flash_init();
    // GPIO relay đã init trong node_prov (hoặc gọi prov_load trước)
    gpio_config(... RL1=4, RL2=5 active-LOW ...); // nếu chưa có
    bool hasCfg = prov_load();
    if (!hasCfg) ESP_LOGW("MAIN","Fresh node — will announce as PENDING");
    // các init còn lại ...
}
```

`g_prov.node_id / room / rl1 / rl2 / cfg_version` sẵn sàng ngay sau `prov_load()`.

## 2) Patch ws_audio_client.c — nhận relay ngay trên socket audio

Trong `handle_ws_text_message(const char *data, int len)` (dòng ~275), thêm nhánh compact trên cùng:

```c
static void handle_ws_text_message(const char *data, int len) {
    // --- compact relay: {"t":"rl","ch":1,"s":1,"seq":12} ---
    cJSON *root = cJSON_ParseWithLength(data, len);
    if (!root) return;
    cJSON *t = cJSON_GetObjectItem(root, "t");
    if (t && cJSON_IsString(t)) {
        if (strcmp(t->valuestring, "rl")==0) {
            int ch  = cJSON_GetObjectItem(root,"ch")->valueint;
            int s   = cJSON_GetObjectItem(root,"s")->valueint;
            int seq = cJSON_GetObjectItem(root,"seq") ? cJSON_GetObjectItem(root,"seq")->valueint : 0;
            int rc = prov_handle_relay_cmd(ch, s, seq);
            if (rc==0) {
                char ack[96]; int n = prov_build_ack(ack, sizeof(ack), seq);
                esp_websocket_client_send_text(ws_client, ack, n, pdMS_TO_TICKS(500));
            }
            cJSON_Delete(root); return;
        }
        if (strcmp(t->valuestring,"cfg")==0) {
            const char *nid = cJSON_GetObjectItem(root,"id")->valuestring;
            const char *room= cJSON_GetObjectItem(root,"room")->valuestring;
            const char *r1  = cJSON_GetObjectItem(root,"rl1")?cJSON_GetObjectItem(root,"rl1")->valuestring:"";
            const char *r2  = cJSON_GetObjectItem(root,"rl2")?cJSON_GetObjectItem(root,"rl2")->valuestring:"";
            int v = cJSON_GetObjectItem(root,"v")->valueint;
            prov_save_cfg(nid, room, r1, r2, (uint16_t)v);
            esp_restart(); // áp dụng config mới
            cJSON_Delete(root); return;
        }
        // "hello_ok" / "pending" từ gateway có thể bỏ qua (chỉ để sync state WS)
    }
    cJSON_Delete(root);
    // ... phần legacy audio_start/audio_end/transcript cũ giữ nguyên bên dưới ...
}
```

**Vì sao không vỡ audio:** ESP-IDF `esp_websocket_client` phân biệt TEXT vs BINARY bằng opcode WS;
PCM mic là `BINARY`, lệnh relay là `TEXT` → xen kẽ an toàn, không chen vào giữa frame PCM.
Gateway gửi TEXT relay (~27B) trong khi Pi đang stream PCM BINARY 2048B chunk — 2 loại frame cùng
TCP socket nhưng tách opcode, phí ~30B nên jitter không đo được.

## 3) Hello heartbeat (WS + MQTT)

Sau khi WS `CONNECTED` và sau mỗi 60s, gửi:

```c
char hello[160];
int rssi = ...; char ip[16]; uint32_t up = esp_timer_get_time()/1000000;
int n = prov_build_hello(hello, sizeof(hello), mac_str, FW_VER, ip, rssi, up);
esp_websocket_client_send_text(ws_client, hello, n, pdMS_TO_TICKS(500));
// đồng thời publish MQTT smarthome/hello (cho node không giữ WS)
esp_mqtt_client_publish(mqtt_client, "smarthome/hello", hello, 0, 1, 0);
```

Chưa provision (`cfg:null`) → Gateway đẩy vào **pending** và WebUI hiện form đăng ký.

## 4) Patch mqtt_relay.c — compact sub & NVS

```c
// subscribe compact
esp_mqtt_client_subscribe(mqtt_client, "smarthome/cmd/" NODE_ID, 1);
esp_mqtt_client_subscribe(mqtt_client, "smarthome/cfg/#", 1); // cfg/{mac} & cfg/{id}

// data callback
void handle_command(const char *data, int len) {
    cJSON *r=cJSON_ParseWithLength(data, len);
    if(!r) return;
    cJSON *t=cJSON_GetObjectItem(r,"t");
    if(t && strcmp(t->valuestring,"rl")==0) {
        int ch=cJSON_GetObjectItem(r,"ch")->valueint;
        int s=cJSON_GetObjectItem(r,"s")->valueint;
        int seq=cJSON_GetObjectItem(r,"seq")?cJSON_GetObjectItem(r,"seq")->valueint:0;
        if(prov_handle_relay_cmd(ch,s,seq)==0){
            char ack[96]; prov_build_ack(ack,sizeof(ack),seq);
            esp_mqtt_client_publish(mqtt_client, "smarthome/status/" NODE_ID, ack, 0, 1, 0);
        }
    } else if(t && strcmp(t->valuestring,"cfg")==0) {
        prov_save_cfg(cJSON_GetObjectItem(r,"id")->valuestring,
                      cJSON_GetObjectItem(r,"room")->valuestring,
                      cJSON_GetObjectItem(r,"rl1")?cJSON_GetObjectItem(r,"rl1")->valuestring:"",
                      cJSON_GetObjectItem(r,"rl2")?cJSON_GetObjectItem(r,"rl2")->valuestring:"",
                      cJSON_GetObjectItem(r,"v")->valueint);
        esp_restart();
    } else {
        // legacy {channel:"ch1", action:"turn_on"}
    }
    cJSON_Delete(r);
}
```

## 5) Wiring — không đổi
RL1 GPIO4 = đèn, RL2 GPIO5 = quạt (Active-LOW, PC817 cathode).

## 6) Kiểm tra nhanh
- Node mới boot → `{"t":"hello","mac":"..","cfg":null}` xuất hiện ở WebUI `Pending` trong <1s.
- Web đăng ký `livingroom / rl1=light / rl2=fan` → node nhận `{"t":"cfg",...}`, reboot, hello mới có `id=livingroom-node01`.
- Nói "bật quạt phòng khách" → WebUI log `livingroom-node01-fan: turn_on → success`, relay quạt chộp ngay, loa phát TTS.
- Ngắt WS (rút Wi-Fi test) → Gateway tự fallback MQTT, relay vẫn bấm được từ web.

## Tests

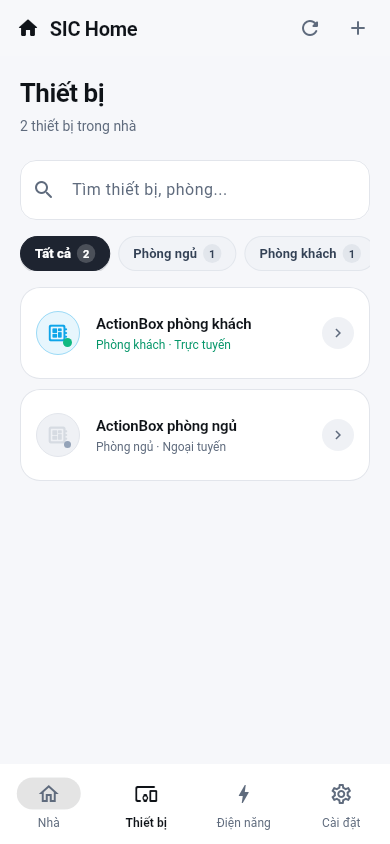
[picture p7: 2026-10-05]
App/dtv_energy_flutter/test/goldens/devices.png

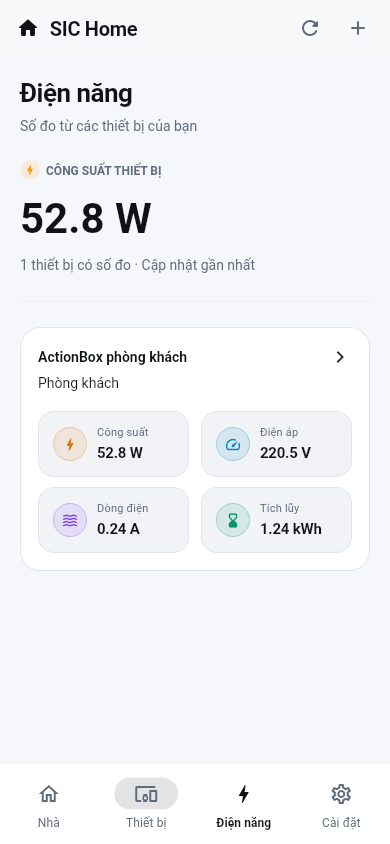
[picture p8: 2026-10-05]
App/dtv_energy_flutter/test/goldens/energy.png

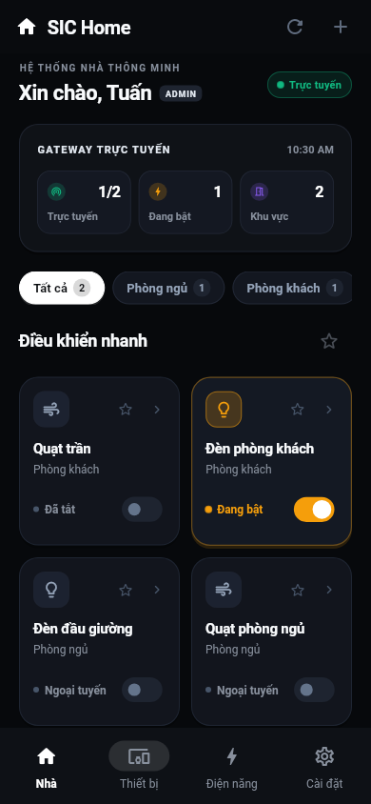
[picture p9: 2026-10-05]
App/dtv_energy_flutter/test/goldens/home-dark.png

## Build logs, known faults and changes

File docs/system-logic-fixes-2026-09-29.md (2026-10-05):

# Các sửa lỗi sau đợt rà soát 2026-09-29

Phạm vi: Gateway, ActionBox, SubBox. Không sửa PCB, âm thanh, APK hoặc archive;
không flash thiết bị. Các thay đổi chưa commit có trước được giữ lại.

## Thay đổi

| Vấn đề trong báo cáo audit | Xử lý trong code |
|---|---|
| 1. Queue chứa `std::string` | Dùng `CommandQueueItem` chỉ chứa số, enum và mảng ký tự; `static_assert` kiểm tra khả năng sao chép byte; chuyển sang object C++ ở phía nhận. |
| 2. Phủ định thành lệnh bật | Chặn phủ định trước các nhánh điều khiển; câu chứa “đang” được phân loại truy vấn. Các câu hỏi có “không” bị từ chối thận trọng. |
| 3. Transcript độ tin cậy thấp vẫn chạy | Gateway trả `accepted:false` và text rỗng; SubBox chỉ sử dụng transcript được chấp nhận rõ ràng. |
| 4. MQTT không nối hai tầng | Nối `home/subbox/+/voice/request`, `/voice/response`, `/command`, `/event/actionbox`; học tuyến từ telemetry; lệnh gửi qua tuyến SubBox chỉ publish một lần. |
| 5. Hai tầng cùng thực thi ASR | SubBox khai báo `asr_only:true`; Gateway trả transcript rồi dừng. Khi cần chuyển lên Gateway, giữ nguyên câu nói; khử yêu cầu MQTT trùng trong bộ nhớ. |
| 6. Hardcode AB001 | Học ID vật lý từ JSON và MAC, dùng ID đó cho audio và lệnh. Board mới lấy ID từ MAC; ID đã lưu trong NVS được giữ. Từ chối ID trùng ở hai MAC. |
| 7. Thành công trước ACK | SubBox chờ ACK ứng dụng, kiểm tra node/request/session/MAC và trạng thái. Gateway chờ ACK khớp lệnh; timeout/lỗi, kể cả lệnh hàng loạt, không nói “đã bật”. Telemetry cập nhật registry thật. |
| 8. Cảm biến ngừng trả dữ liệu | Chặn bật khi chưa có mẫu hợp lệ hoặc mẫu quá hạn; kiểm tra định kỳ để cắt relay đang ON và chốt lỗi. `SAFETY_SENSOR_TIMEOUT_MS` mặc định 2000 ms. |
| 9. Giữ mutex khi stagger relay | Nhả mutex trước khi chờ, lấy lại và kiểm tra lỗi/trạng thái/mẫu cảm biến trước khi đóng. Lệnh tắt hoặc fault hủy yêu cầu bật đang chờ qua `target_state`. |
| 10. Chặn callback Wi-Fi | Callback ESP-NOW chỉ sao chép vào queue hữu hạn; worker xử lý. ASR start/feed/stop chạy ngoài khóa trạng thái AudioManager. Không dùng transcript của phiên bị lỗi gửi audio. |
| 11. ASR chặn asyncio | Chạy suy luận trong thread, giới hạn một lần suy luận; yêu cầu khi bận được từ chối thay vì tích lũy audio. |
| 12. Một cập nhật ghi lại mọi node | Bỏ ghi khi relay không đổi; chỉ sync SQLite node thay đổi. JSON vẫn được ghi nguyên tử khi trạng thái thay đổi để giữ cách lưu hiện có. |
| 13. Ngữ cảnh lẫn client | Gateway tách theo client, có TTL và giới hạn 128 phiên. SubBox chỉ dùng lịch sử cùng ActionBox trong 30 giây. |
| 14. Request ID lặp sau reboot | Thêm `session_id` ngẫu nhiên theo phiên; cache ActionBox xét cặp session/request; ACK mang lại session. |
| 15. Cache TTS vô hạn | LRU tối đa 16 MiB dữ liệu audio và 256 entry; dọn file audio quá 7 ngày hoặc vượt tổng 128 MiB lúc khởi tạo và sau khi ghi. |
| 16. Radio cố định rải rác | Một cấu hình `CONFIG_ACTIONBOX_ESPNOW_CHANNEL` trong `menuconfig > ActionBox radio`; peer dùng kênh radio hiện tại. Mặc định vẫn 11. |

Sửa thêm: phép thay chuỗi UTF-8 “mở/ngắt”; chuẩn hóa khoảng trắng trước đổi từ;
telemetry lớn hơn 250 byte bị transport loại; từ chối JSON quá dài thay vì cắt;
kiểm tra lỗi đọc cảm biến khi truy vấn; không biến lệnh relay không hỗ trợ thành
PING thành công; bỏ đánh giá rule bằng nhiệt độ giả 27,5°C.

## Kiểm chứng

- `python Gateway/tests/test_intent_engine_v3.py`: 84/84.
- `python -m unittest discover -s Gateway/tests -p test_runtime_utils.py`: 5/5.
- `python -m unittest discover -s Gateway/tests -p test_system_regressions.py`: 9/9.
- `python -m compileall -q Gateway/gateway`: thành công.
- SubBox: build ESP-IDF thành công.
- ActionBox: build ESP-IDF thành công sau `reconfigure build` để nhận Kconfig mới.
- `python Firmware/tests/test_nlu_native.py`: bỏ qua trên máy hiện tại vì không
  có compiler C++ host trên PATH. Test biên dịch và chạy các file NLU thật khi
  có `g++`/`c++`; không thay thế bằng kiểm tra chuỗi source.

## Giới hạn triển khai

- Cần cập nhật đồng bộ Gateway và hai firmware vì có trường `accepted`,
  `asr_only`, `session_id` và luồng ACK mới.
- Chưa đo độ trễ, mất gói, ngưỡng bảo vệ hoặc kiểm thử tải điện trên thiết bị thật.
  ACK xác nhận trạng thái phần mềm relay; không chứng minh tiếp điểm hay tải điện.
- Kênh AP phải cố định và khớp cấu hình ActionBox. Chưa có tự dò kênh khi AP đổi kênh.
- ID cũ bị trùng trong NVS cần được cấu hình lại riêng; không tự đổi danh tính board đã dùng.
- Khi nhiều relay cùng loại trong một phòng, SubBox từ chối chọn tùy tiện.
  Luồng MQTT bổ sung tập trung vào lệnh relay/voice/telemetry, không triển khai
  một hệ provisioning, OTA hay điều khiển nhiệt độ mới.
- JSON registry vẫn ghi đồng bộ khi relay đổi. Nếu đo được đây là nút thắt sau
  khi triển khai, bước tiếp theo là gom các lần ghi; chưa thêm worker lưu trữ.
- Khử MQTT trùng dùng cache hữu hạn trong RAM; không bảo đảm exactly-once qua
  mất điện của cả Gateway và ActionBox.

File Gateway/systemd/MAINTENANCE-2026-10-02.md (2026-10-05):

# Pi4 maintenance, 2026-10-02

Host: `pi4@192.168.11.29` (Debian 13, 4 GB RAM).

Completed:

- Removed pip download cache (880 files, 285.7 MB) and APT archives (about 307 MB).
- Removed unused Docker images `influxdb:3-core` and `eclipse-mosquitto:latest`.
- Stopped and disabled `llama-server.service`: the running Gateway configuration has
  `AI_ENABLED=false` and `LLM_MODE=off`. Removed the Gateway unit's automatic Llama dependency.
- Kept all Qwen and speech models, per the user's request.
- Replaced the broken `/usr/local/bin/autohotspot.sh` with the script in this directory.
  Tested Ethernet, saved Wi-Fi and hotspot fallback decisions offline. On the Pi,
  verified the Ethernet branch without changing any network connection.
- No application database, container data, virtual environment or running container was removed.

Verification:

- Root filesystem used bytes: 19,146,436,608 before, 17,773,568,000 after cleanup
  (about 1.37 GB reclaimed, subject to concurrent writes).
- Gateway PID remained 1805; HTTP health checks for Gateway, Grafana, InfluxDB
  and Home Assistant returned 200. EMQX remained running.
- `systemctl --failed` reported zero failed services after the hotspot repair.
- Llama was `inactive` and `disabled`. Its ~2 GB RSS was mostly reclaimable model
  pages; this is not a claim of 2 GB newly available application RAM.
- Temperature approximately 43 C; no thermal throttling detected.
- No reboot or real offline-network failover was performed.

Root-owned backups on the Pi:
`/var/backups/sic-tuning-20261002-TDPNre/` contains the original
`smarthome-gateway.service` and `autohotspot.sh`.

To enable the local model server again:

```sh
sudo systemctl enable --now llama-server.service
```

The Gateway's AI flags must also be enabled separately when local AI is wanted.
To restore the original unit, copy its backup to `/etc/systemd/system/` and run
`sudo systemctl daemon-reload`. The old hotspot script is syntactically broken;
its backup is retained for reference only.

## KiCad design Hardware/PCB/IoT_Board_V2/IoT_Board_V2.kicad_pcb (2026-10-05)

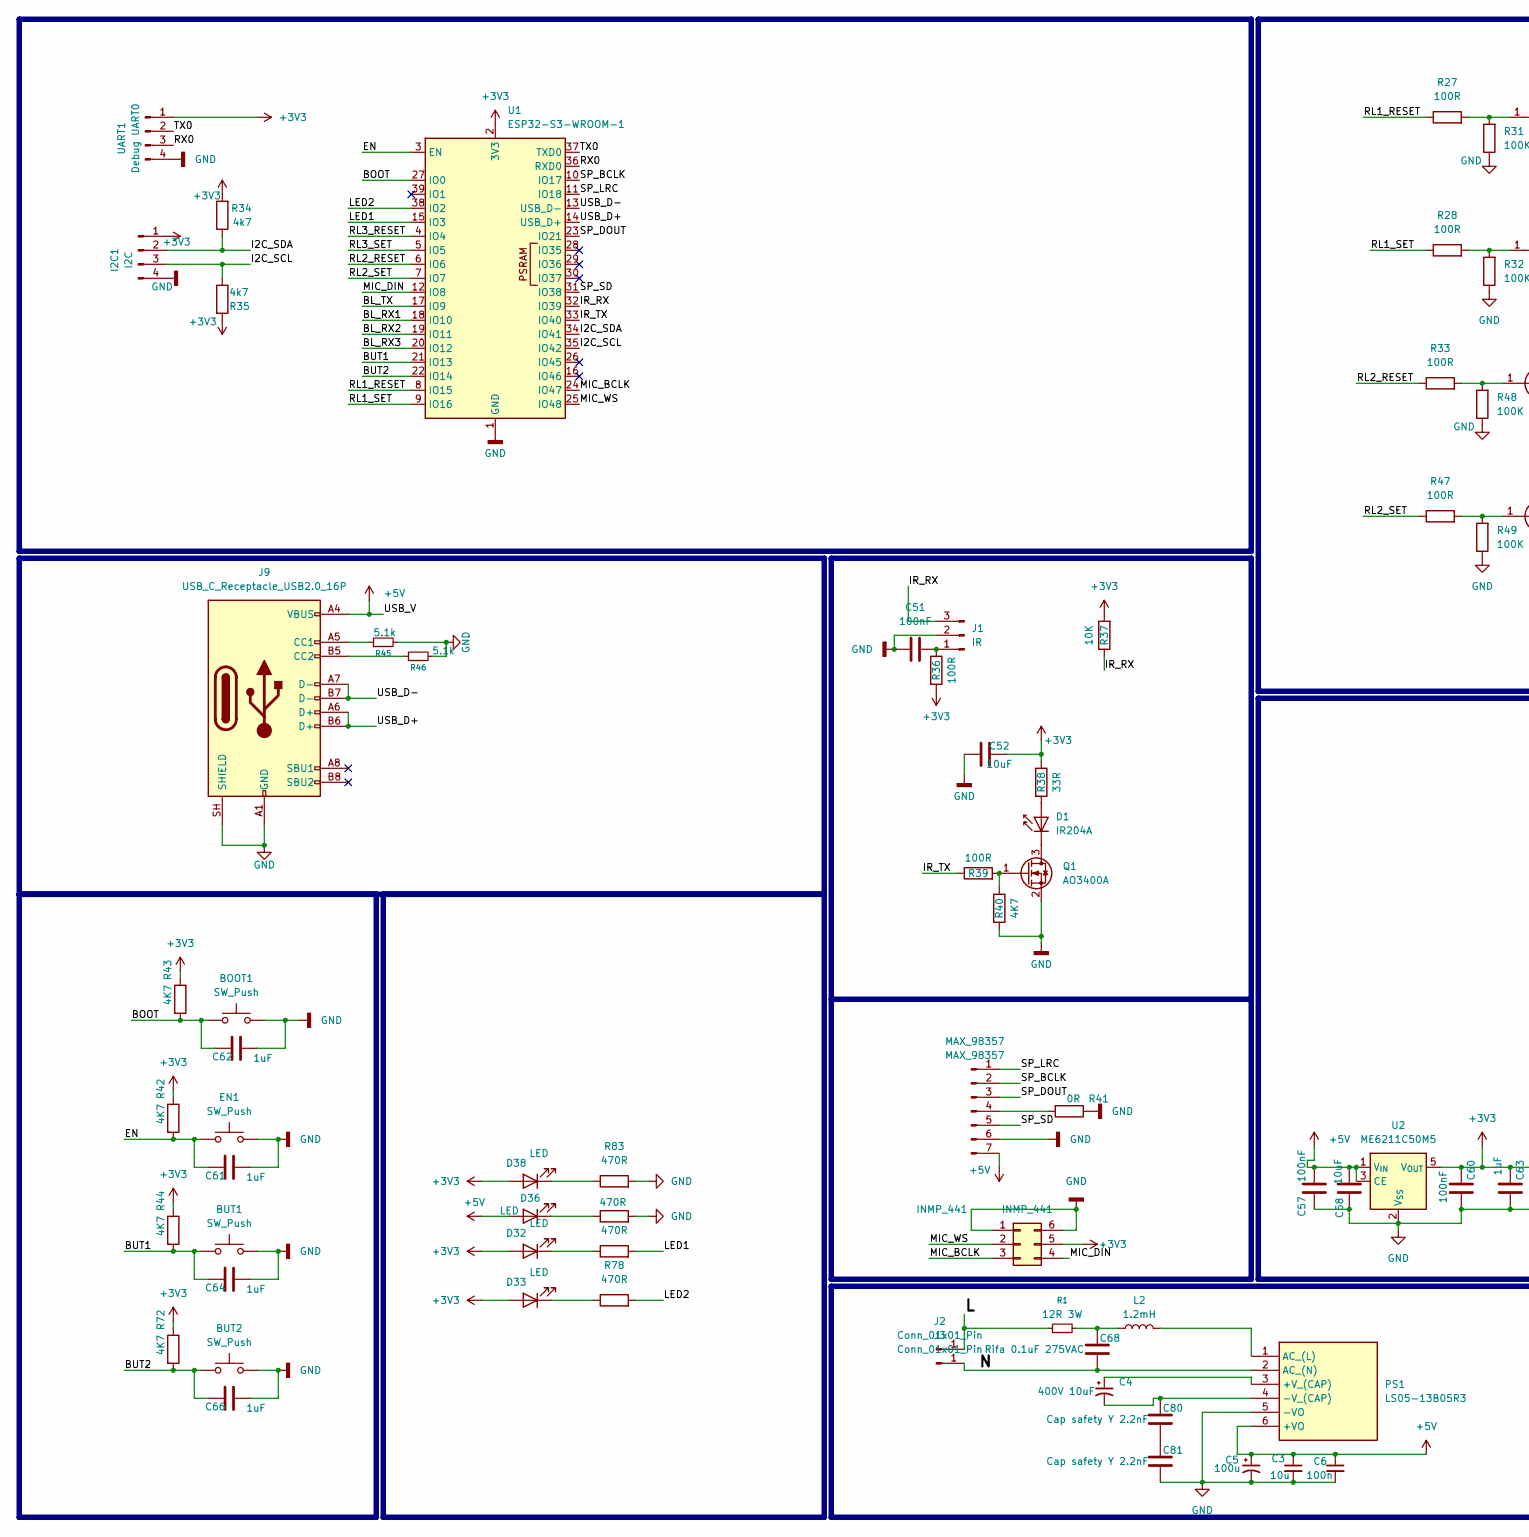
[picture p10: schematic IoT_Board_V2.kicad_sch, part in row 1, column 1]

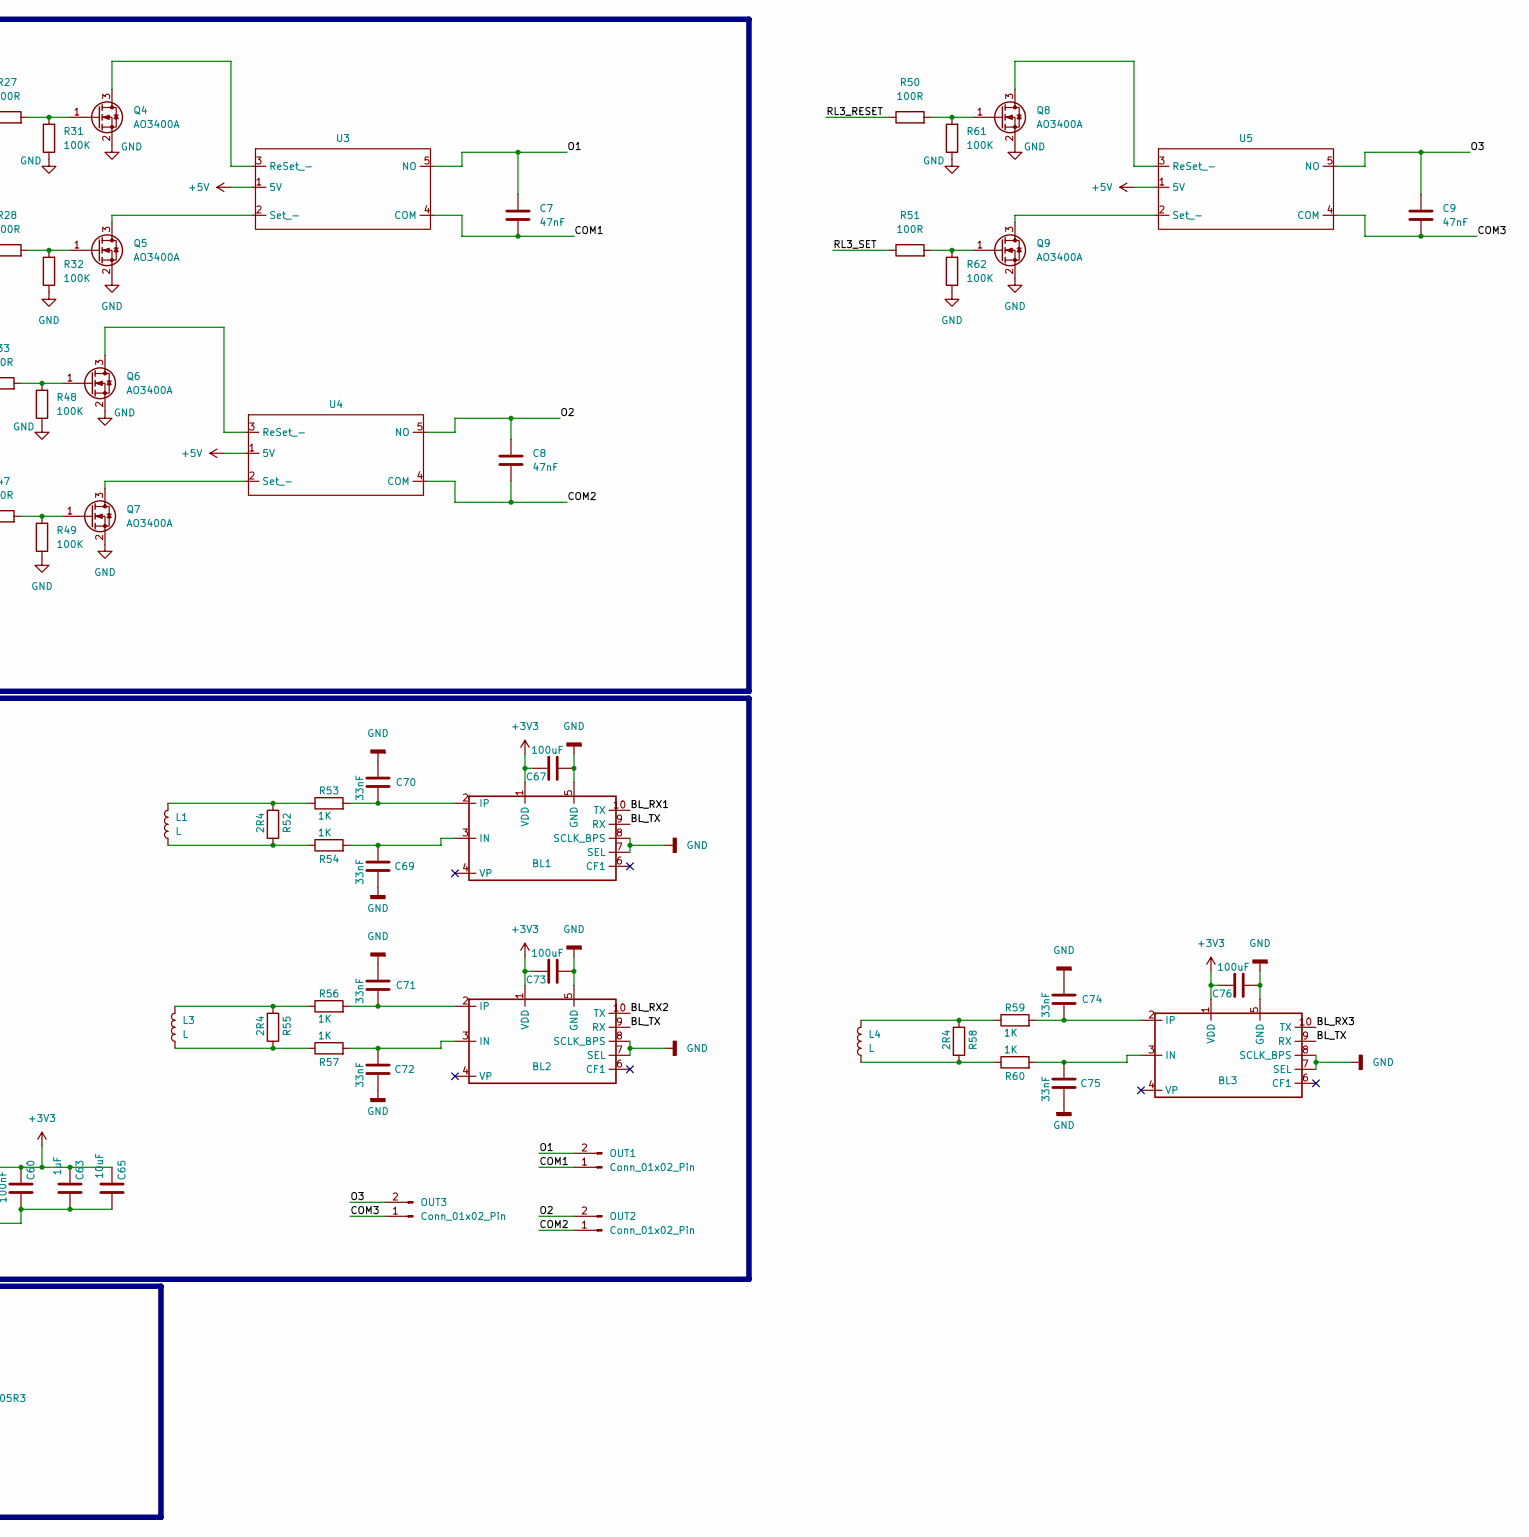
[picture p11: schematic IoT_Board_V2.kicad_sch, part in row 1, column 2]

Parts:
BL1, BL2, BL3: SSOP-10_3.9x4.9mm_P1.00mm
BOOT1: SW_Push; SW_SPST_TL3305A
BUT1, BUT2: SW_Push; SW_SPST_TL3305A
C3: 10u; C_1206_3216Metric
C4: 400V 10uF; CP_Radial_D10.0mm_P5.00mm
C5: 100u; CP_Elec_10x10.5
C6: 100n; C_1206_3216Metric
C7, C8, C9: 47nF; C_Disc_D8.0mm_W5.0mm_P10.00mm
C51: 100nF; R_0805_2012Metric_Pad1.20x1.40mm_HandSolder
C52, C58, C65: 10uF; R_0603_1608Metric_Pad0.98x0.95mm_HandSolder
C57, C60: 100nF; R_0603_1608Metric_Pad0.98x0.95mm_HandSolder
C61, C62, C63, C64, C66: 1uF; R_0603_1608Metric_Pad0.98x0.95mm_HandSolder
C67, C73, C76: 100uF; R_0603_1608Metric_Pad0.98x0.95mm_HandSolder
C68: Rifa 0.1uF 275VAC; C_Rect_L16.5mm_W5.0mm_P15.00mm_MKT
C69, C70, C71, C72, C74, C75: 33nF; R_0603_1608Metric_Pad0.98x0.95mm_HandSolder
C80, C81: Cap safety Y 2.2nF; C_Disc_D10.5mm_W5.0mm_P7.50mm
D1: IR204A; LED_D3.0mm_IRBlack
D32, D33, D36, D38: LED; LED_0805_2012Metric_Pad1.15x1.40mm_HandSolder
EN1: SW_Push; SW_SPST_TL3305A
I2C1: I2C; JST_GH_BM04B-GHS-TBT_1x04-1MP_P1.25mm_Vertical
INMP_441: INMP_441; JST_GH_BM06B-GHS-TBT_1x06-1MP_P1.25mm_Vertical
J1: IR; PinHeader_1x03_P2.54mm_Vertical
J2, J3: Conn_01x01_Pin; Untitled
J9: USB_C_Receptacle_USB2.0_16P; USB_C_Receptacle_HCTL_HC-TYPE-C-16P-01A
L1, L3, L4: L; CT225A4mm
L2: 1.2mH; L_Wuerth_WE-PD-Typ-LS
MAX_98357: MAX_98357; JST_GH_BM07B-GHS-TBT_1x07-1MP_P1.25mm_Vertical
OUT1, OUT2, OUT3: Conn_01x02_Pin; Cos_blade_6.3
PS1: LS05-13B05R3; LS0513B05R3; Manufacturer_Part_Number LS05-13B05R3
Q1, Q4, Q5, Q6, Q7, Q8, Q9: AO3400A; SOT-23
R1: 12R 3W; R_Axial_DIN0309_L9.0mm_D3.2mm_P12.70mm_Horizontal
R27, R28, R33, R36, R39, R47, R50, R51: 100R; R_0603_1608Metric_Pad0.98x0.95mm_HandSolder
R31, R32, R48, R49, R61, R62: 100K; R_0603_1608Metric_Pad0.98x0.95mm_HandSolder
R34, R35: 4k7; R_0603_1608Metric_Pad0.98x0.95mm_HandSolder
R37: 10K; R_0603_1608Metric_Pad0.98x0.95mm_HandSolder
R38: 33R; R_0603_1608Metric_Pad0.98x0.95mm_HandSolder
R40, R42, R43, R44, R72: 4K7; R_0603_1608Metric_Pad0.98x0.95mm_HandSolder
R41: 0R; R_0603_1608Metric_Pad0.98x0.95mm_HandSolder
R45, R46: 5.1k; R_0603_1608Metric_Pad0.98x0.95mm_HandSolder
R52, R55, R58: 2R4; R_0603_1608Metric_Pad0.98x0.95mm_HandSolder
R53, R54, R56, R57, R59, R60: 1K; R_0603_1608Metric_Pad0.98x0.95mm_HandSolder
R77, R78, R81, R83: 470R; R_0603_1608Metric_Pad0.98x0.95mm_HandSolder
U1: ESP32-S3-WROOM-1; ESP32-S3-WROOM-1U
U2: ME6211C50M5; SOT-23-5
U3, U4, U5: HKE3LT ：20A 250VAC TV- 10 250VAC 10A 30VDC
UART1: Debug UART0; PinHeader_1x04_P2.54mm_Vertical

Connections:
+3V3: BL1.1 (VDD), BL2.1 (VDD), BL3.1 (VDD), C52.2, C60.2, C63.2, C65.2, C67.2, C73.2, C76.2, D32.2 (A), D33.2 (A), D38.2 (A), I2C1.1, INMP_441.5, R34.2, R35.2, R36.2, R37.2, R38.1, R42.1, R43.1, R44.1, R72.1, U1.2 (3V3), U2.5 (V_{OUT}), UART1.1
+5V: C3.1, C5.1, C6.1, C57.2, C58.2, D36.2 (A), J9.A4 (VBUS), J9.A9 (VBUS), J9.B4 (VBUS), J9.B9 (VBUS), MAX_98357.7, PS1.6 (+VO), U2.1 (V_{IN}), U2.3 (CE), U3.1 (5V), U4.1 (5V), U5.1 (5V)
/BL_RX1: BL1.10 (TX), U1.18 (IO10)
/BL_RX2: BL2.10 (TX), U1.19 (IO11)
/BL_RX3: BL3.10 (TX), U1.20 (IO12)
/BL_TX: BL1.9 (RX), BL2.9 (RX), BL3.9 (RX), U1.17 (IO9)
/BOOT: BOOT1.1, C62.2, R43.2, U1.27 (IO0)
/BUT1: BUT1.1, C64.2, R44.2, U1.21 (IO13)
/BUT2: BUT2.1, C66.2, R72.2, U1.22 (IO14)
/COM1: C7.2, OUT1.1, U3.4 (COM)
/COM2: C8.2, OUT2.1, U4.4 (COM)
/COM3: C9.2, OUT3.1, U5.4 (COM)
/EN: C61.2, EN1.1, R42.2, U1.3 (EN)
/I2C_SCL: I2C1.3, R35.1, U1.35 (IO42)
/I2C_SDA: I2C1.2, R34.1, U1.34 (IO41)
/IR_RX: J1.3, R37.1, U1.32 (IO39)
/IR_TX: R39.1, U1.33 (IO40)
/L: J2.1 (Pin_1_1), R1.1
/LED1: R77.2, U1.15 (IO3)
/LED2: R78.2, U1.38 (IO2)
/MIC_BCLK: INMP_441.3, U1.24 (IO47)
/MIC_DIN: INMP_441.4, U1.12 (IO8)
/MIC_WS: INMP_441.2, U1.25 (IO48)
/N: C68.2, J3.1 (Pin_1_1), PS1.2 (AC_(N))
/O1: C7.1, OUT1.2, U3.5 (NO)
/O2: C8.1, OUT2.2, U4.5 (NO)
/O3: C9.1, OUT3.2, U5.5 (NO)
/RL1_RESET: R27.1, U1.8 (IO15)
/RL1_SET: R28.1, U1.9 (IO16)
/RL2_RESET: R33.1, U1.6 (IO6)
/RL2_SET: R47.1, U1.7 (IO7)
/RL3_RESET: R50.1, U1.4 (IO4)
/RL3_SET: R51.1, U1.5 (IO5)
/RX0: U1.36 (RXD0), UART1.3
/SP_BCLK: MAX_98357.2, U1.10 (IO17)
/SP_DOUT: MAX_98357.3, U1.23 (IO21)
/SP_LRC: MAX_98357.1, U1.11 (IO18)
/SP_SD: MAX_98357.5, U1.31 (IO38)
/TX0: U1.37 (TXD0), UART1.2
/USB_D+: J9.A6 (D+), J9.B6 (D+), U1.14 (USB_D+)
/USB_D-: J9.A7 (D-), J9.B7 (D-), U1.13 (USB_D-)
GND: BL1.5 (GND), BL1.7 (SEL), BL1.8 (SCLK_BPS), BL2.5 (GND), BL2.7 (SEL), BL2.8 (SCLK_BPS), BL3.5 (GND), BL3.7 (SEL), BL3.8 (SCLK_BPS), BOOT1.2, BUT1.2, BUT2.2, C3.2, C5.2, C6.2, C51.2, C52.1, C57.1, C58.1, C60.1, C61.1, C62.1, C63.1, C64.1, C65.1, C66.1, C67.1, C69.2, C70.1, C71.1, C72.2, C73.1, C74.1, C75.2, C76.1, C81.2, EN1.2, I2C1.4, INMP_441.1, INMP_441.6, J1.2, J9.A1 (GND), J9.A12 (GND), J9.B1 (GND), J9.B12 (GND), J9.SH (SHIELD), MAX_98357.6, PS1.5 (-VO), Q1.2 (S), Q4.2 (S), Q5.2 (S), Q6.2 (S), Q7.2 (S), Q8.2 (S), Q9.2 (S), R31.1, R32.1, R40.2, R41.1, R45.2, R46.2, R48.1, R49.1, R61.1, R62.1, R81.2, R83.2, U1.1 (GND), U1.40 (GND), U1.41 (GND), U2.2 (V_{SS}), UART1.4
unnamed: BL1.3 (IN), C69.1, R54.2
unnamed: BL1.2 (IP), C70.2, R53.2
unnamed: BL2.3 (IN), C72.1, R57.2
unnamed: BL2.2 (IP), C71.2, R56.2
unnamed: BL3.3 (IN), C75.1, R60.2
unnamed: BL3.2 (IP), C74.2, R59.2
unnamed: C68.1, L2.1, R1.2
unnamed: C80.2, C81.1
unnamed: D1.2 (A), R38.2
unnamed: D1.1 (K), Q1.3 (D)
unnamed: D32.1 (K), R77.1
unnamed: D33.1 (K), R78.1
unnamed: D36.1 (K), R81.1
unnamed: D38.1 (K), R83.1
unnamed: C51.1, J1.1, R36.1
unnamed: J9.A5 (CC1), R45.1
unnamed: J9.B5 (CC2), R46.1
unnamed: L1.1, R52.2, R54.1
unnamed: L1.2, R52.1, R53.1
unnamed: L3.1, R55.2, R57.1
unnamed: L3.2, R55.1, R56.1
unnamed: L4.1, R58.2, R60.1
unnamed: L4.2, R58.1, R59.1
unnamed: MAX_98357.4, R41.2
unnamed: C4.1, PS1.3 (+V_(CAP))
unnamed: C4.2, C80.1, PS1.4 (-V_(CAP))
unnamed: L2.2, PS1.1 (AC_(L))
unnamed: Q1.1 (G), R39.2, R40.1
unnamed: Q4.3 (D), U3.3 (ReSet_-)
unnamed: Q4.1 (G), R27.2, R31.2
unnamed: Q5.3 (D), U3.2 (Set_-)
unnamed: Q5.1 (G), R28.2, R32.2
unnamed: Q6.3 (D), U4.3 (ReSet_-)
unnamed: Q6.1 (G), R33.2, R48.2
unnamed: Q7.3 (D), U4.2 (Set_-)
unnamed: Q7.1 (G), R47.2, R49.2
unnamed: Q8.3 (D), U5.3 (ReSet_-)
unnamed: Q8.1 (G), R50.2, R61.2
unnamed: Q9.3 (D), U5.2 (Set_-)
unnamed: Q9.1 (G), R51.2, R62.2

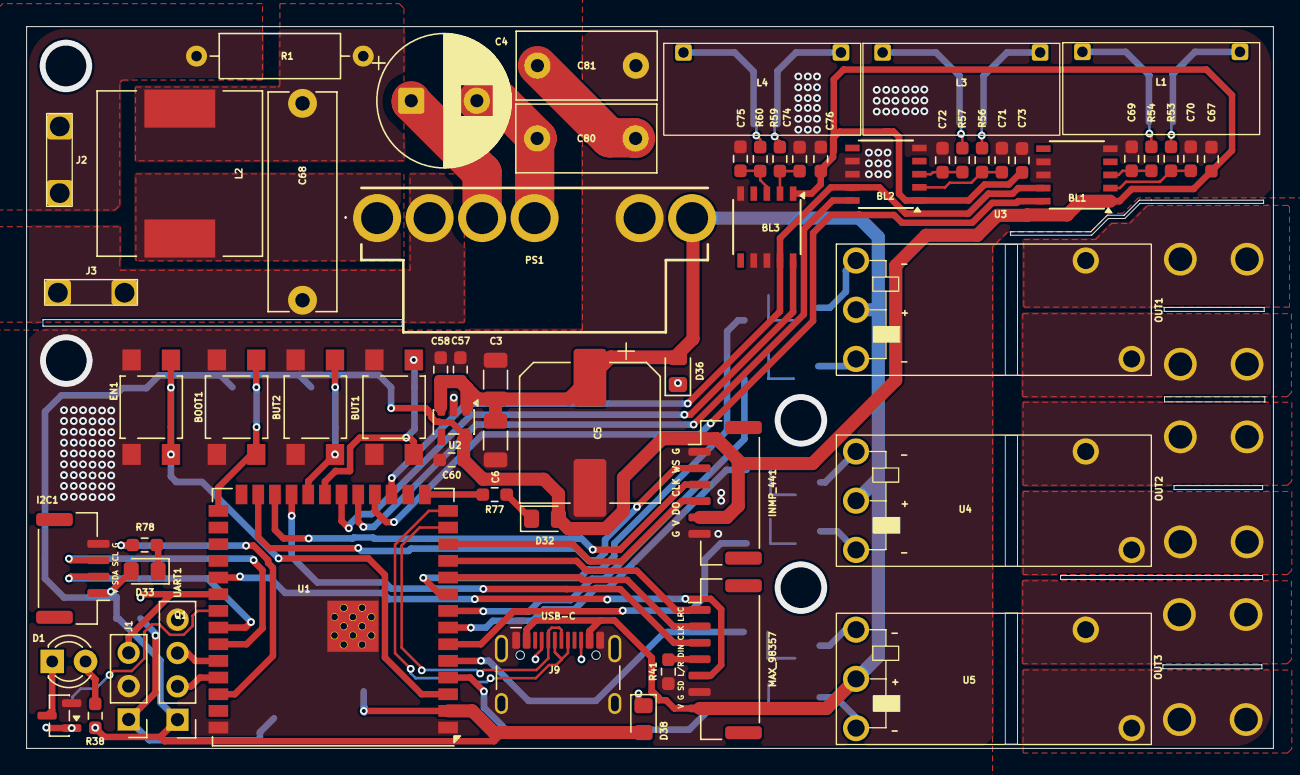
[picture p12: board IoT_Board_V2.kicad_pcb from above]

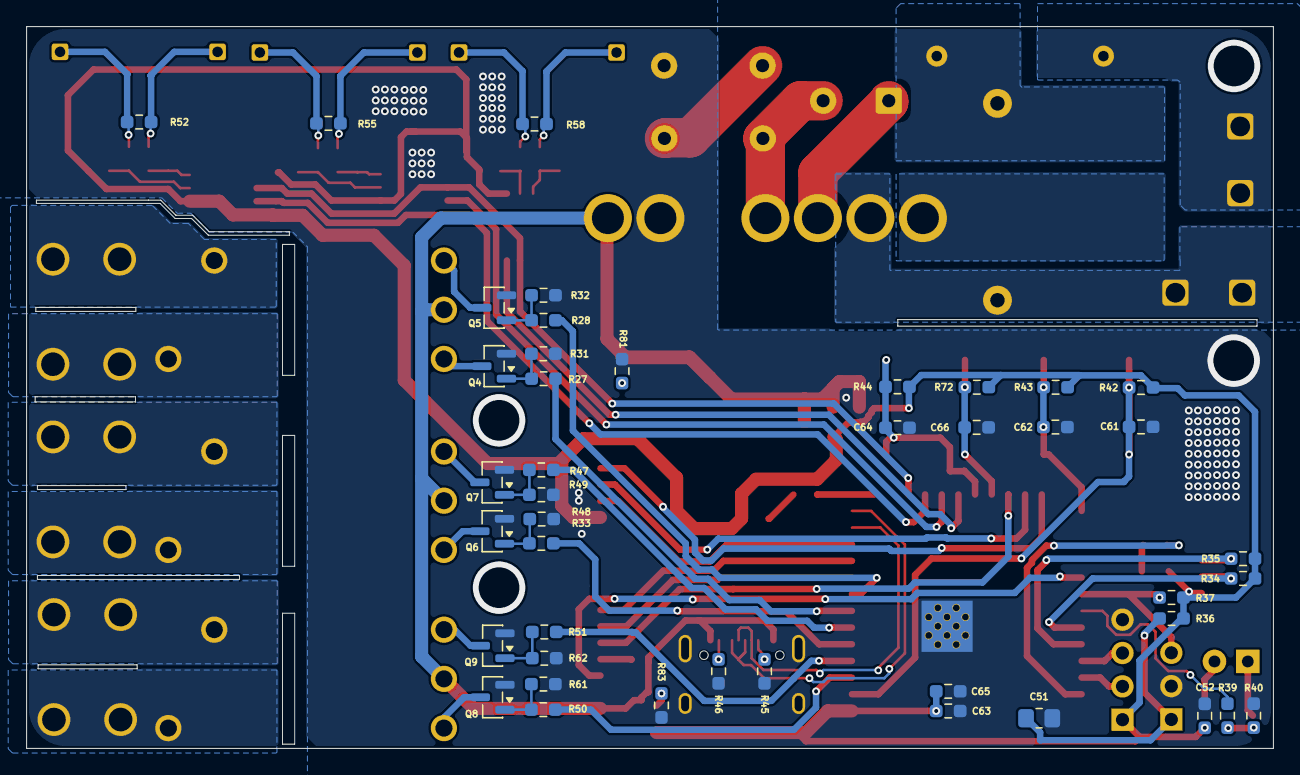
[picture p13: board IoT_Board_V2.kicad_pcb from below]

Board: 2 copper layers, 95.0 x 55.0 mm, 107 parts (43 on the bottom side), 82 nets.

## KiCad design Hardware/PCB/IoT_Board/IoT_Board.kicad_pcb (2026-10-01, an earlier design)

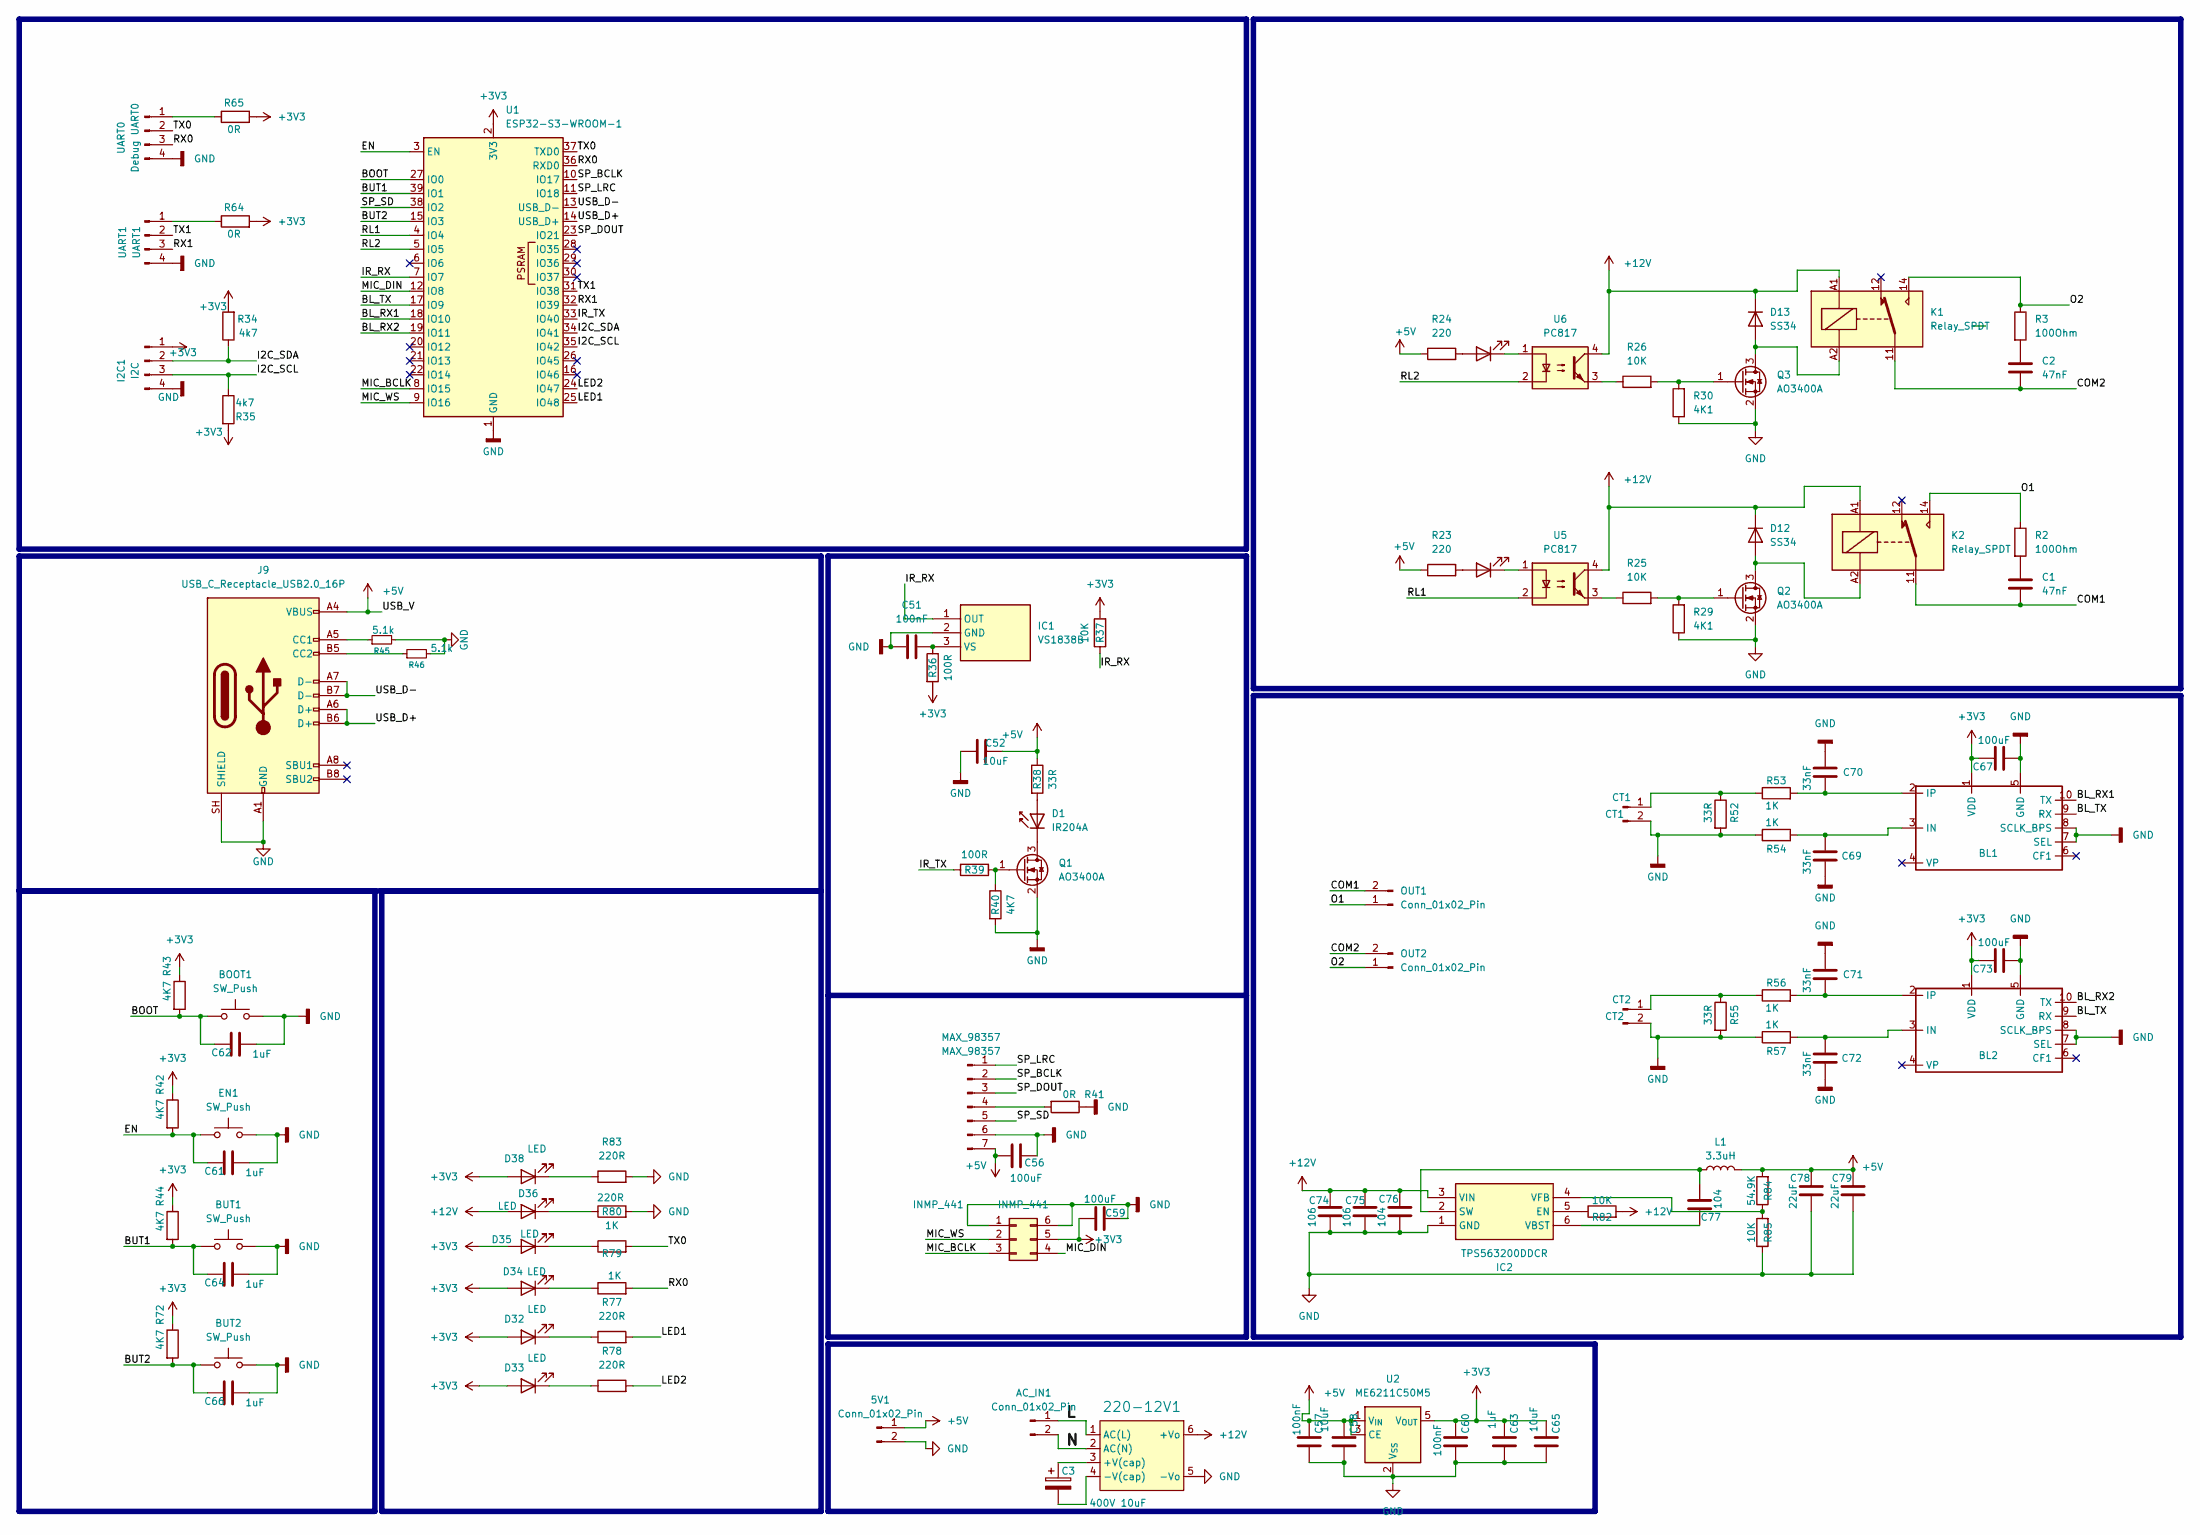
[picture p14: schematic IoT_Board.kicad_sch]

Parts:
5V1: Conn_01x02_Pin; PinHeader_1x02_P2.54mm_Vertical
220-12V1: LS05_12V; LS05-23BxxDR3
AC_IN1: Conn_01x02_Pin; TerminalBlock_Phoenix_MKDS-1,5-2-5.08_1x02_P5.08mm_Horizont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
BL1, BL2: SSOP-10_3.9x4.9mm_P1.00mm
BOOT1: SW_Push; SW_Tactile_SPST_NO_Straight_CK_PTS636Sx25SMTRLFS
BUT1, BUT2: SW_Push; SW_Tactile_SPST_NO_Straight_CK_PTS636Sx25SMTRLFS
C1, C2: 47nF; C_Disc_D10.5mm_W5.0mm_P7.50mm
C3: 400V 10uF; CP_Elec_10x10.5
C51: 100nF; R_0805_2012Metric_Pad1.20x1.40mm_HandSolder
C52, C58, C65: 10uF; R_0603_1608Metric_Pad0.98x0.95mm_HandSolder
C56, C59, C67, C73: 100uF; R_0603_1608Metric_Pad0.98x0.95mm_HandSolder
C57, C60: 100nF; R_0603_1608Metric_Pad0.98x0.95mm_HandSolder
C61, C62, C63, C64, C66: 1uF; R_0603_1608Metric_Pad0.98x0.95mm_HandSolder
C69, C70, C71, C72: 33nF; R_0603_1608Metric_Pad0.98x0.95mm_HandSolder
C74, C75: 106; R_1206_3216Metric_Pad1.30x1.75mm_HandSolder
C76, C77: 104; R_0603_1608Metric_Pad0.98x0.95mm_HandSolder
C78, C79: 22uF; R_0603_1608Metric_Pad0.98x0.95mm_HandSolder
CT1: CT1; JST_XH_B2B-XH-A_1x02_P2.50mm_Vertical
CT2: CT2; JST_XH_B2B-XH-A_1x02_P2.50mm_Vertical
D1: IR204A; LED_D3.0mm_IRBlack
D12, D13: SS34; D_SMA_Handsoldering
D32, D33, D34, D35, D36, D38: LED; LED_0805_2012Metric_Pad1.15x1.40mm_HandSolder
EN1: SW_Push; SW_Tactile_SPST_NO_Straight_CK_PTS636Sx25SMTRLFS
I2C1: I2C; JST_XH_B4B-XH-A_1x04_P2.50mm_Vertical
IC1: VS1838B; Manufacturer_Part_Number VS1838B
IC2: TPS563200DDCR; SOT95P280X110-6N; Manufacturer_Part_Number TPS563200DDCR; Mouser Part Number 595-TPS563200DDCR
INMP_441: INMP_441; PinHeader_2x03_P2.54mm_Vertical
J9: USB_C_Receptacle_USB2.0_16P; USB_C_Receptacle_HCTL_HC-TYPE-C-16P-01A
K1, K2: Relay_SPDT; Relay_SPDT_Schrack-RT1-16A-FormC_RM5mm
L1: 3.3uH; L_7.3x7.3_H3.5
LED_RL1, LED_RL2: LED; LED_0805_2012Metric_Pad1.15x1.40mm_HandSolder
MAX_98357: MAX_98357; PinHeader_1x07_P2.54mm_Vertical
OUT1, OUT2: Conn_01x02_Pin; TerminalBlock_Phoenix_MKDS-1,5-2-5.08_1x02_P5.08mm_Horizont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
Q1, Q2, Q3: AO3400A; SOT-23
R2, R3: 100Ohm; R_Axial_DIN0414_L11.9mm_D4.5mm_P15.24mm_Horizontal
R23, R24: 220; R_0603_1608Metric_Pad0.98x0.95mm_HandSolder
R25, R26, R37, R82, R85: 10K; R_0603_1608Metric_Pad0.98x0.95mm_HandSolder
R29, R30: 4K1; R_0603_1608Metric_Pad0.98x0.95mm_HandSolder
R34, R35: 4k7; R_0603_1608Metric_Pad0.98x0.95mm_HandSolder
R36, R39: 100R; R_0603_1608Metric_Pad0.98x0.95mm_HandSolder
R38, R52, R55: 33R; R_0603_1608Metric_Pad0.98x0.95mm_HandSolder
R40, R42, R43, R44, R72: 4K7; R_0603_1608Metric_Pad0.98x0.95mm_HandSolder
R41, R64, R65: 0R; R_0603_1608Metric_Pad0.98x0.95mm_HandSolder
R45, R46: 5.1k; R_0603_1608Metric_Pad0.98x0.95mm_HandSolder
R53, R54, R56, R57, R79, R80: 1K; R_0603_1608Metric_Pad0.98x0.95mm_HandSolder
R77, R78, R81, R83: 220R; R_0603_1608Metric_Pad0.98x0.95mm_HandSolder
R84: 54.9K; R_0603_1608Metric_Pad0.98x0.95mm_HandSolder
U1: ESP32-S3-WROOM-1; ESP32-S3-WROOM-1U
U2: ME6211C50M5; SOT-23-5
U5, U6: PC817; SOP254P960X420-4N
UART0: Debug UART0; JST_XH_B4B-XH-A_1x04_P2.50mm_Vertical
UART1: UART1; JST_XH_B4B-XH-A_1x04_P2.50mm_Vertical

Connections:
+3V3: BL1.1 (VDD), BL2.1 (VDD), C59.1, C60.2, C63.2, C65.2, C67.2, C73.2, D32.2 (A), D33.2 (A), D34.2 (A), D35.2 (A), D38.2 (A), I2C1.1, INMP_441.5, R34.2, R35.2, R36.2, R37.2, R42.1, R43.1, R44.1, R64.2, R65.2, R72.1, U1.2 (3V3), U2.5 (V_{OUT})
+5V: 5V1.1, C52.2, C56.1, C57.2, C58.2, C78.1, C79.1, J9.A4 (VBUS), J9.A9 (VBUS), J9.B4 (VBUS), J9.B9 (VBUS), L1.2, MAX_98357.7, R23.1, R24.1, R38.1, R84.2, U2.1 (V_{IN}), U2.3 (CE)
+12V: 220-12V1.6 (+Vo), C74.1, C75.1, C76.1, D12.1 (K), D13.1 (K), D36.2 (A), IC2.3 (VIN), K1.A1, K2.A1, R82.2, U5.4, U6.4
/BL_RX1: BL1.10 (TX), U1.18 (IO10)
/BL_RX2: BL2.6 (CF1), BL2.10 (TX), U1.19 (IO11)
/BL_TX: BL1.9 (RX), BL2.9 (RX), U1.17 (IO9)
/BOOT: BOOT1.1, C62.2, R43.2, U1.27 (IO0)
/BUT1: BUT1.1, C64.2, R44.2, U1.39 (IO1)
/BUT2: BUT2.1, C66.2, R72.2, U1.15 (IO3)
/COM1: C1.2, K2.11, OUT1.2
/COM2: C2.2, K1.11, OUT2.2
/EN: C61.2, EN1.1, R42.2, U1.3 (EN)
/I2C_SCL: I2C1.3, R35.1, U1.35 (IO42)
/I2C_SDA: I2C1.2, R34.1, U1.34 (IO41)
/IR_RX: IC1.1 (OUT), R37.1, U1.7 (IO7)
/IR_TX: R39.1, U1.33 (IO40)
/L: 220-12V1.1 (AC(L)), AC_IN1.1
/LED1: R77.2, U1.25 (IO48)
/LED2: R78.2, U1.24 (IO47)
/MIC_BCLK: INMP_441.3, U1.8 (IO15)
/MIC_DIN: INMP_441.4, U1.12 (IO8)
/MIC_WS: INMP_441.2, U1.9 (IO16)
/N: 220-12V1.2 (AC(N)), AC_IN1.2
/O1: K2.14, OUT1.1, R2.1
/O2: K1.14, OUT2.1, R3.1
/RL1: U1.4 (IO4), U5.2
/RL2: U1.5 (IO5), U6.2
/RX0: R79.2, U1.36 (RXD0), UART0.3
/RX1: U1.32 (IO39), UART1.3
/SP_BCLK: MAX_98357.2, U1.10 (IO17)
/SP_DOUT: MAX_98357.3, U1.23 (IO21)
/SP_LRC: MAX_98357.1, U1.11 (IO18)
/SP_SD: MAX_98357.5, U1.38 (IO2)
/TX0: R80.2, U1.37 (TXD0), UART0.2
/TX1: U1.31 (IO38), UART1.2
/USB_D+: J9.A6 (D+), J9.B6 (D+), U1.14 (USB_D+)
/USB_D-: J9.A7 (D-), J9.B7 (D-), U1.13 (USB_D-)
GND: 5V1.2, 220-12V1.5 (-Vo), BL1.5 (GND), BL1.7 (SEL), BL1.8 (SCLK_BPS), BL2.5 (GND), BL2.7 (SEL), BL2.8 (SCLK_BPS), BOOT1.2, BUT1.2, BUT2.2, C51.2, C52.1, C56.2, C57.1, C58.1, C59.2, C60.1, C61.1, C62.1, C63.1, C64.1, C65.1, C66.1, C67.1, C69.2, C70.1, C71.1, C72.2, C73.1, C74.2, C75.2, C76.2, C78.2, C79.2, CT1.2, CT2.2, EN1.2, I2C1.4, IC1.2 (GND), IC2.1 (GND), INMP_441.1, INMP_441.6, J9.A1 (GND), J9.A12 (GND), J9.B1 (GND), J9.B12 (GND), J9.SH (SHIELD), MAX_98357.6, Q1.2 (S), Q2.2 (S), Q3.2 (S), R29.1, R30.1, R40.2, R41.1, R45.2, R46.2, R52.2, R54.1, R55.2, R57.1, R81.2, R83.2, R85.1, U1.1 (GND), U1.40 (GND), U1.41 (GND), U2.2 (V_{SS}), UART0.4, UART1.4
unnamed: 220-12V1.3 (+V(cap)), C3.1
unnamed: 220-12V1.4 (-V(cap)), C3.2
unnamed: BL1.3 (IN), C69.1, R54.2
unnamed: BL1.2 (IP), C70.2, R53.2
unnamed: BL2.3 (IN), C72.1, R57.2
unnamed: BL2.2 (IP), C71.2, R56.2
unnamed: C1.1, R2.2
unnamed: C2.1, R3.2
unnamed: CT1.1, R52.1, R53.1
unnamed: CT2.1, R55.1, R56.1
unnamed: D1.2 (A), R38.2
unnamed: D1.1 (K), Q1.3 (D)
unnamed: D12.2 (A), K2.A2, Q2.3 (D)
unnamed: D13.2 (A), K1.A2, Q3.3 (D)
unnamed: D32.1 (K), R77.1
unnamed: D33.1 (K), R78.1
unnamed: D34.1 (K), R79.1
unnamed: D35.1 (K), R80.1
unnamed: D36.1 (K), R81.1
unnamed: D38.1 (K), R83.1
unnamed: C51.1, IC1.3 (VS), R36.1
unnamed: IC2.5 (EN), R82.1
unnamed: C77.2, IC2.2 (SW), L1.1
unnamed: C77.1, IC2.6 (VBST)
unnamed: IC2.4 (VFB), R84.1, R85.2
unnamed: J9.A5 (CC1), R45.1
unnamed: J9.B5 (CC2), R46.1
unnamed: LED_RL1.2 (A), R23.2
unnamed: LED_RL1.1 (K), U5.1
unnamed: LED_RL2.2 (A), R24.2
unnamed: LED_RL2.1 (K), U6.1
unnamed: MAX_98357.4, R41.2
unnamed: Q1.1 (G), R39.2, R40.1
unnamed: Q2.1 (G), R25.2, R29.2
unnamed: Q3.1 (G), R26.2, R30.2
unnamed: R25.1, U5.3
unnamed: R26.1, U6.3
unnamed: R65.1, UART0.1
unnamed: R64.1, UART1.1

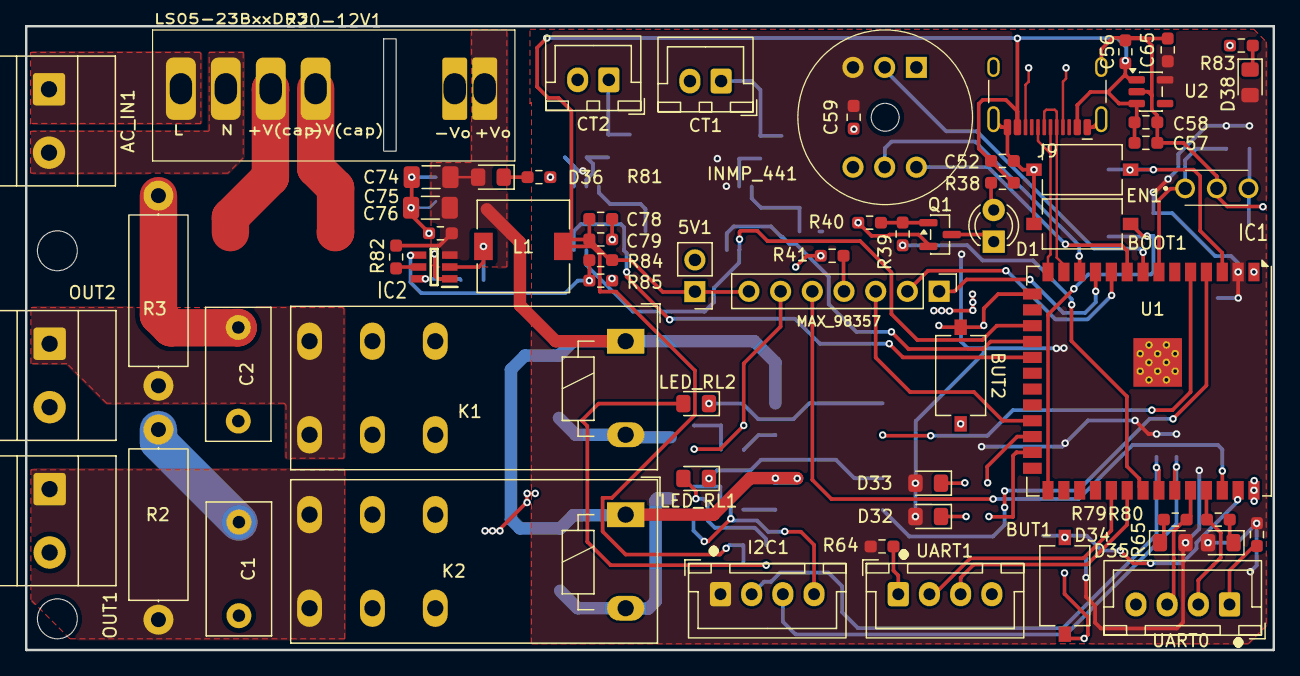
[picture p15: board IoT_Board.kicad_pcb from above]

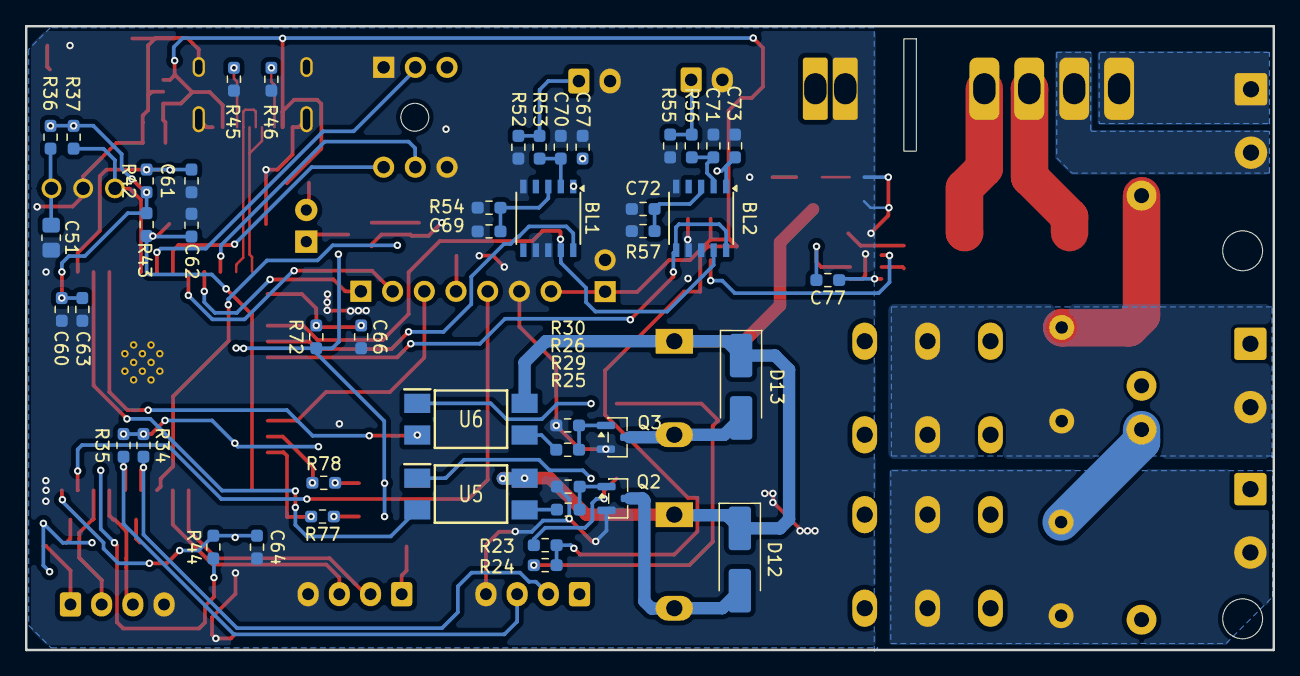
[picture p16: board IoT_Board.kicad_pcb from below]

Board: 2 copper layers, 100.0 x 50.0 mm, 108 parts (46 on the bottom side), 75 nets.

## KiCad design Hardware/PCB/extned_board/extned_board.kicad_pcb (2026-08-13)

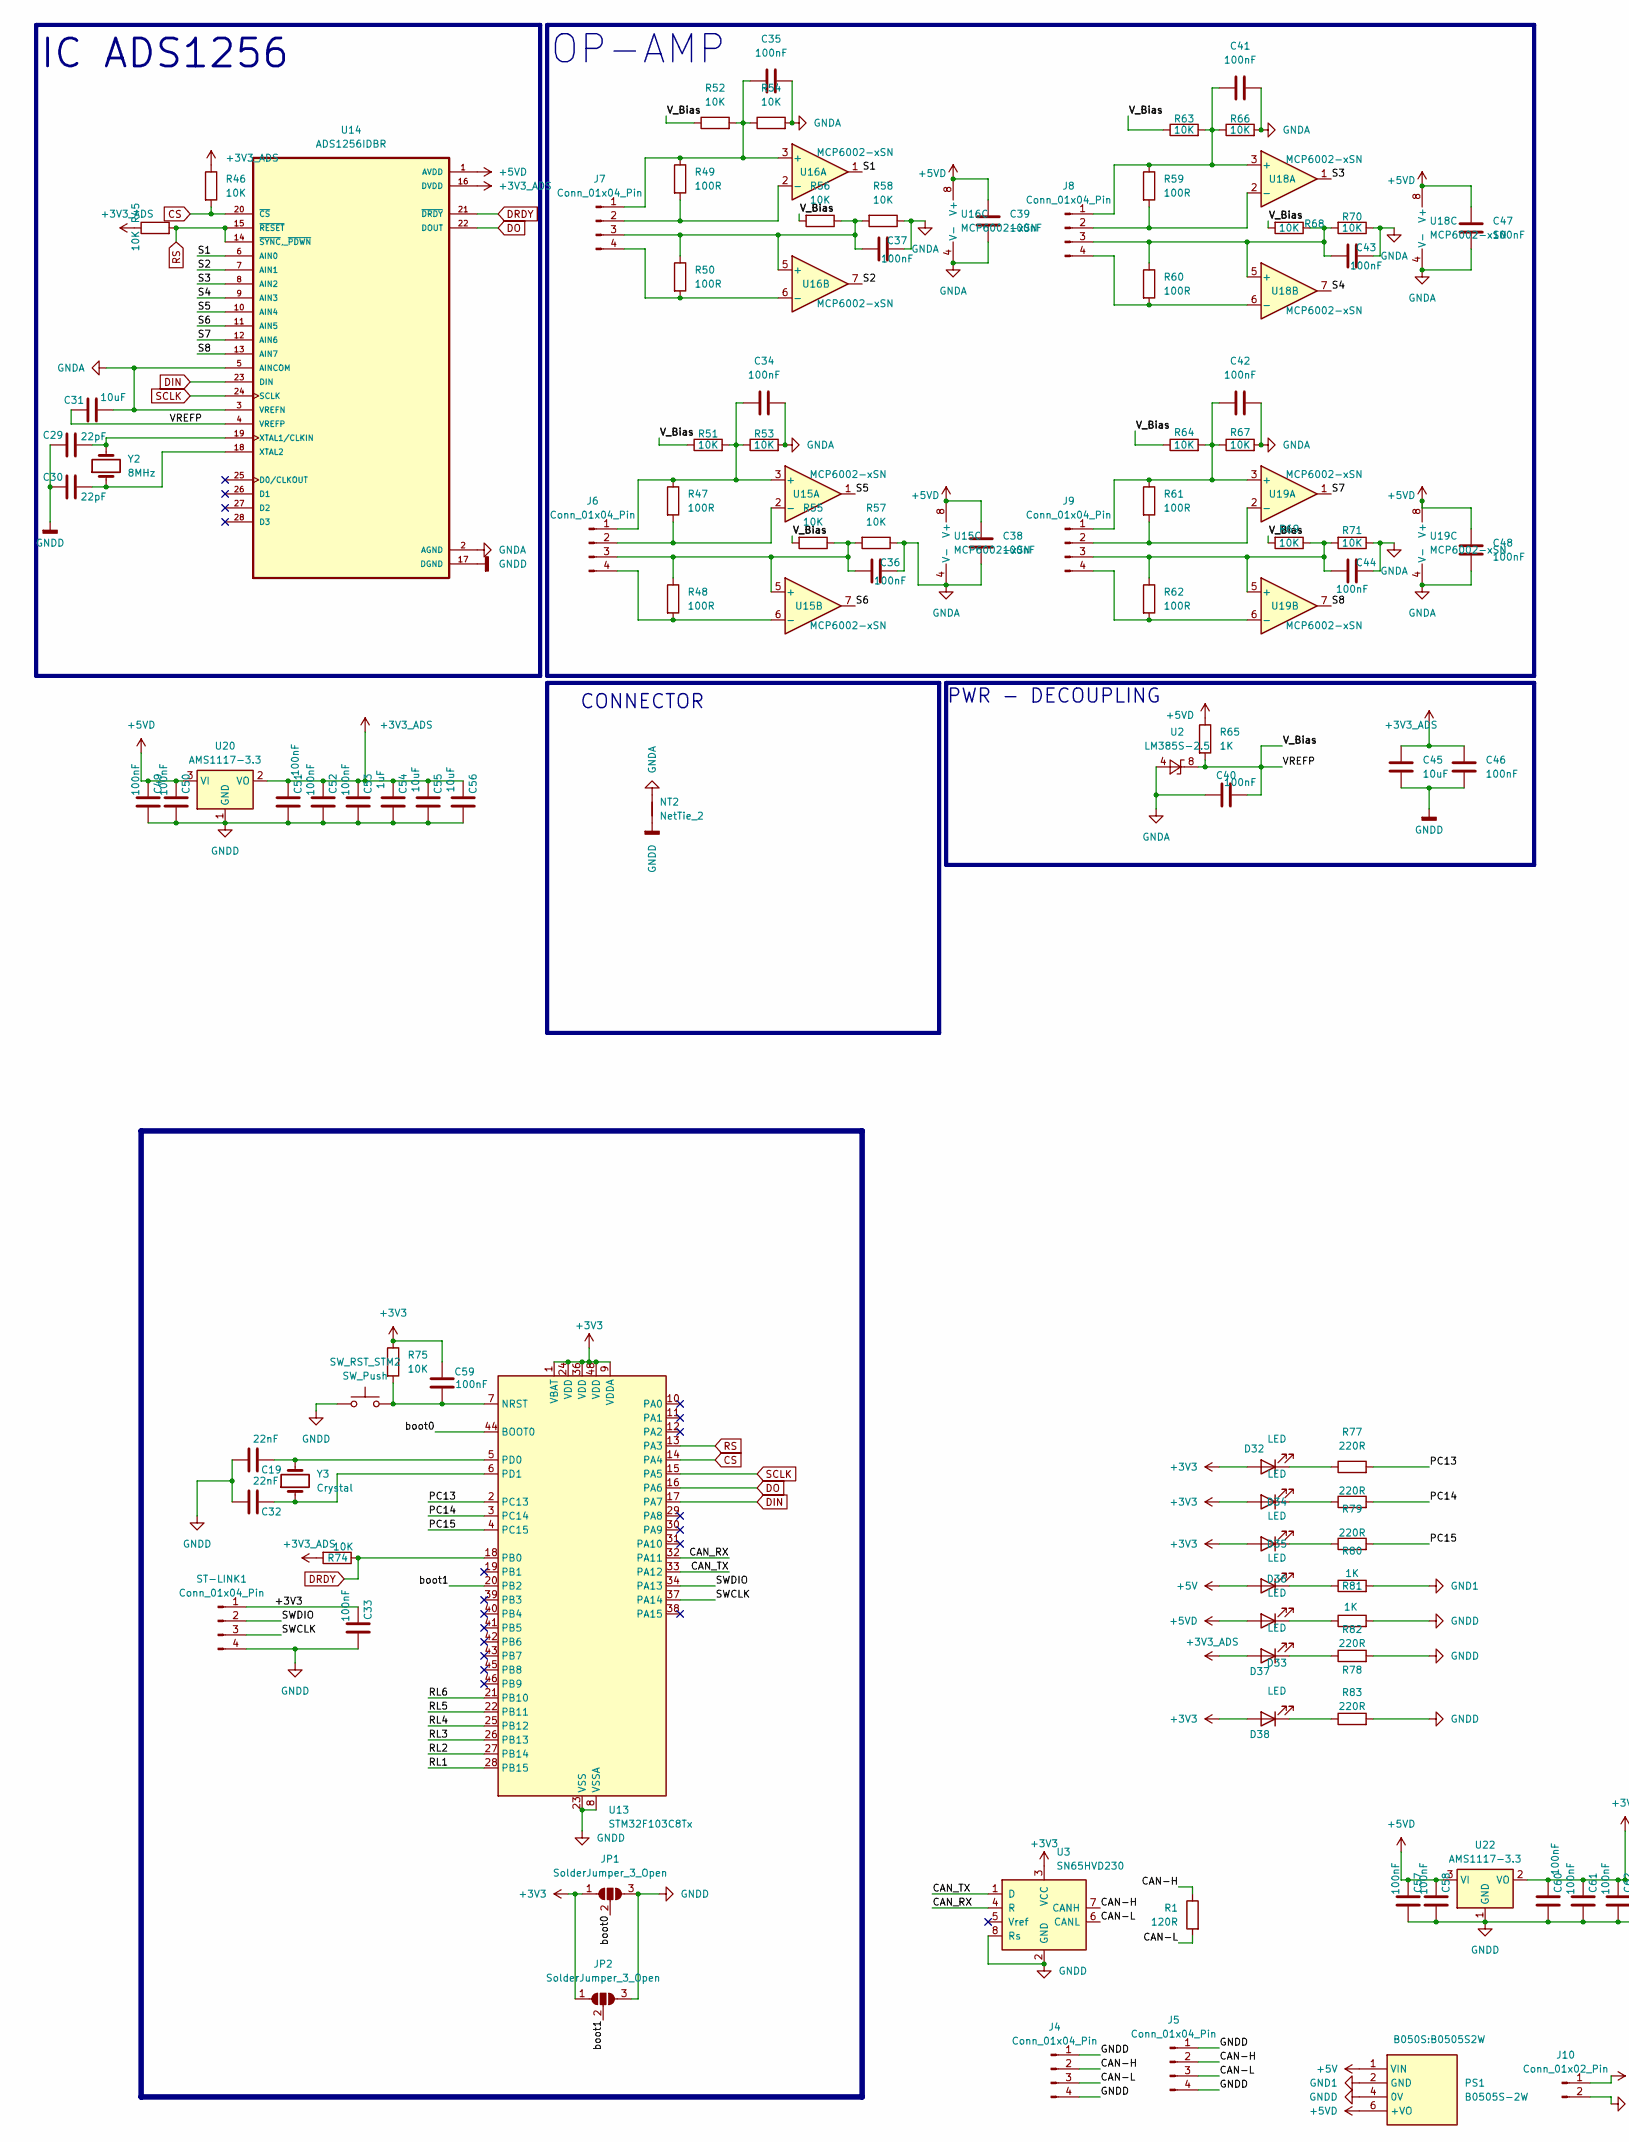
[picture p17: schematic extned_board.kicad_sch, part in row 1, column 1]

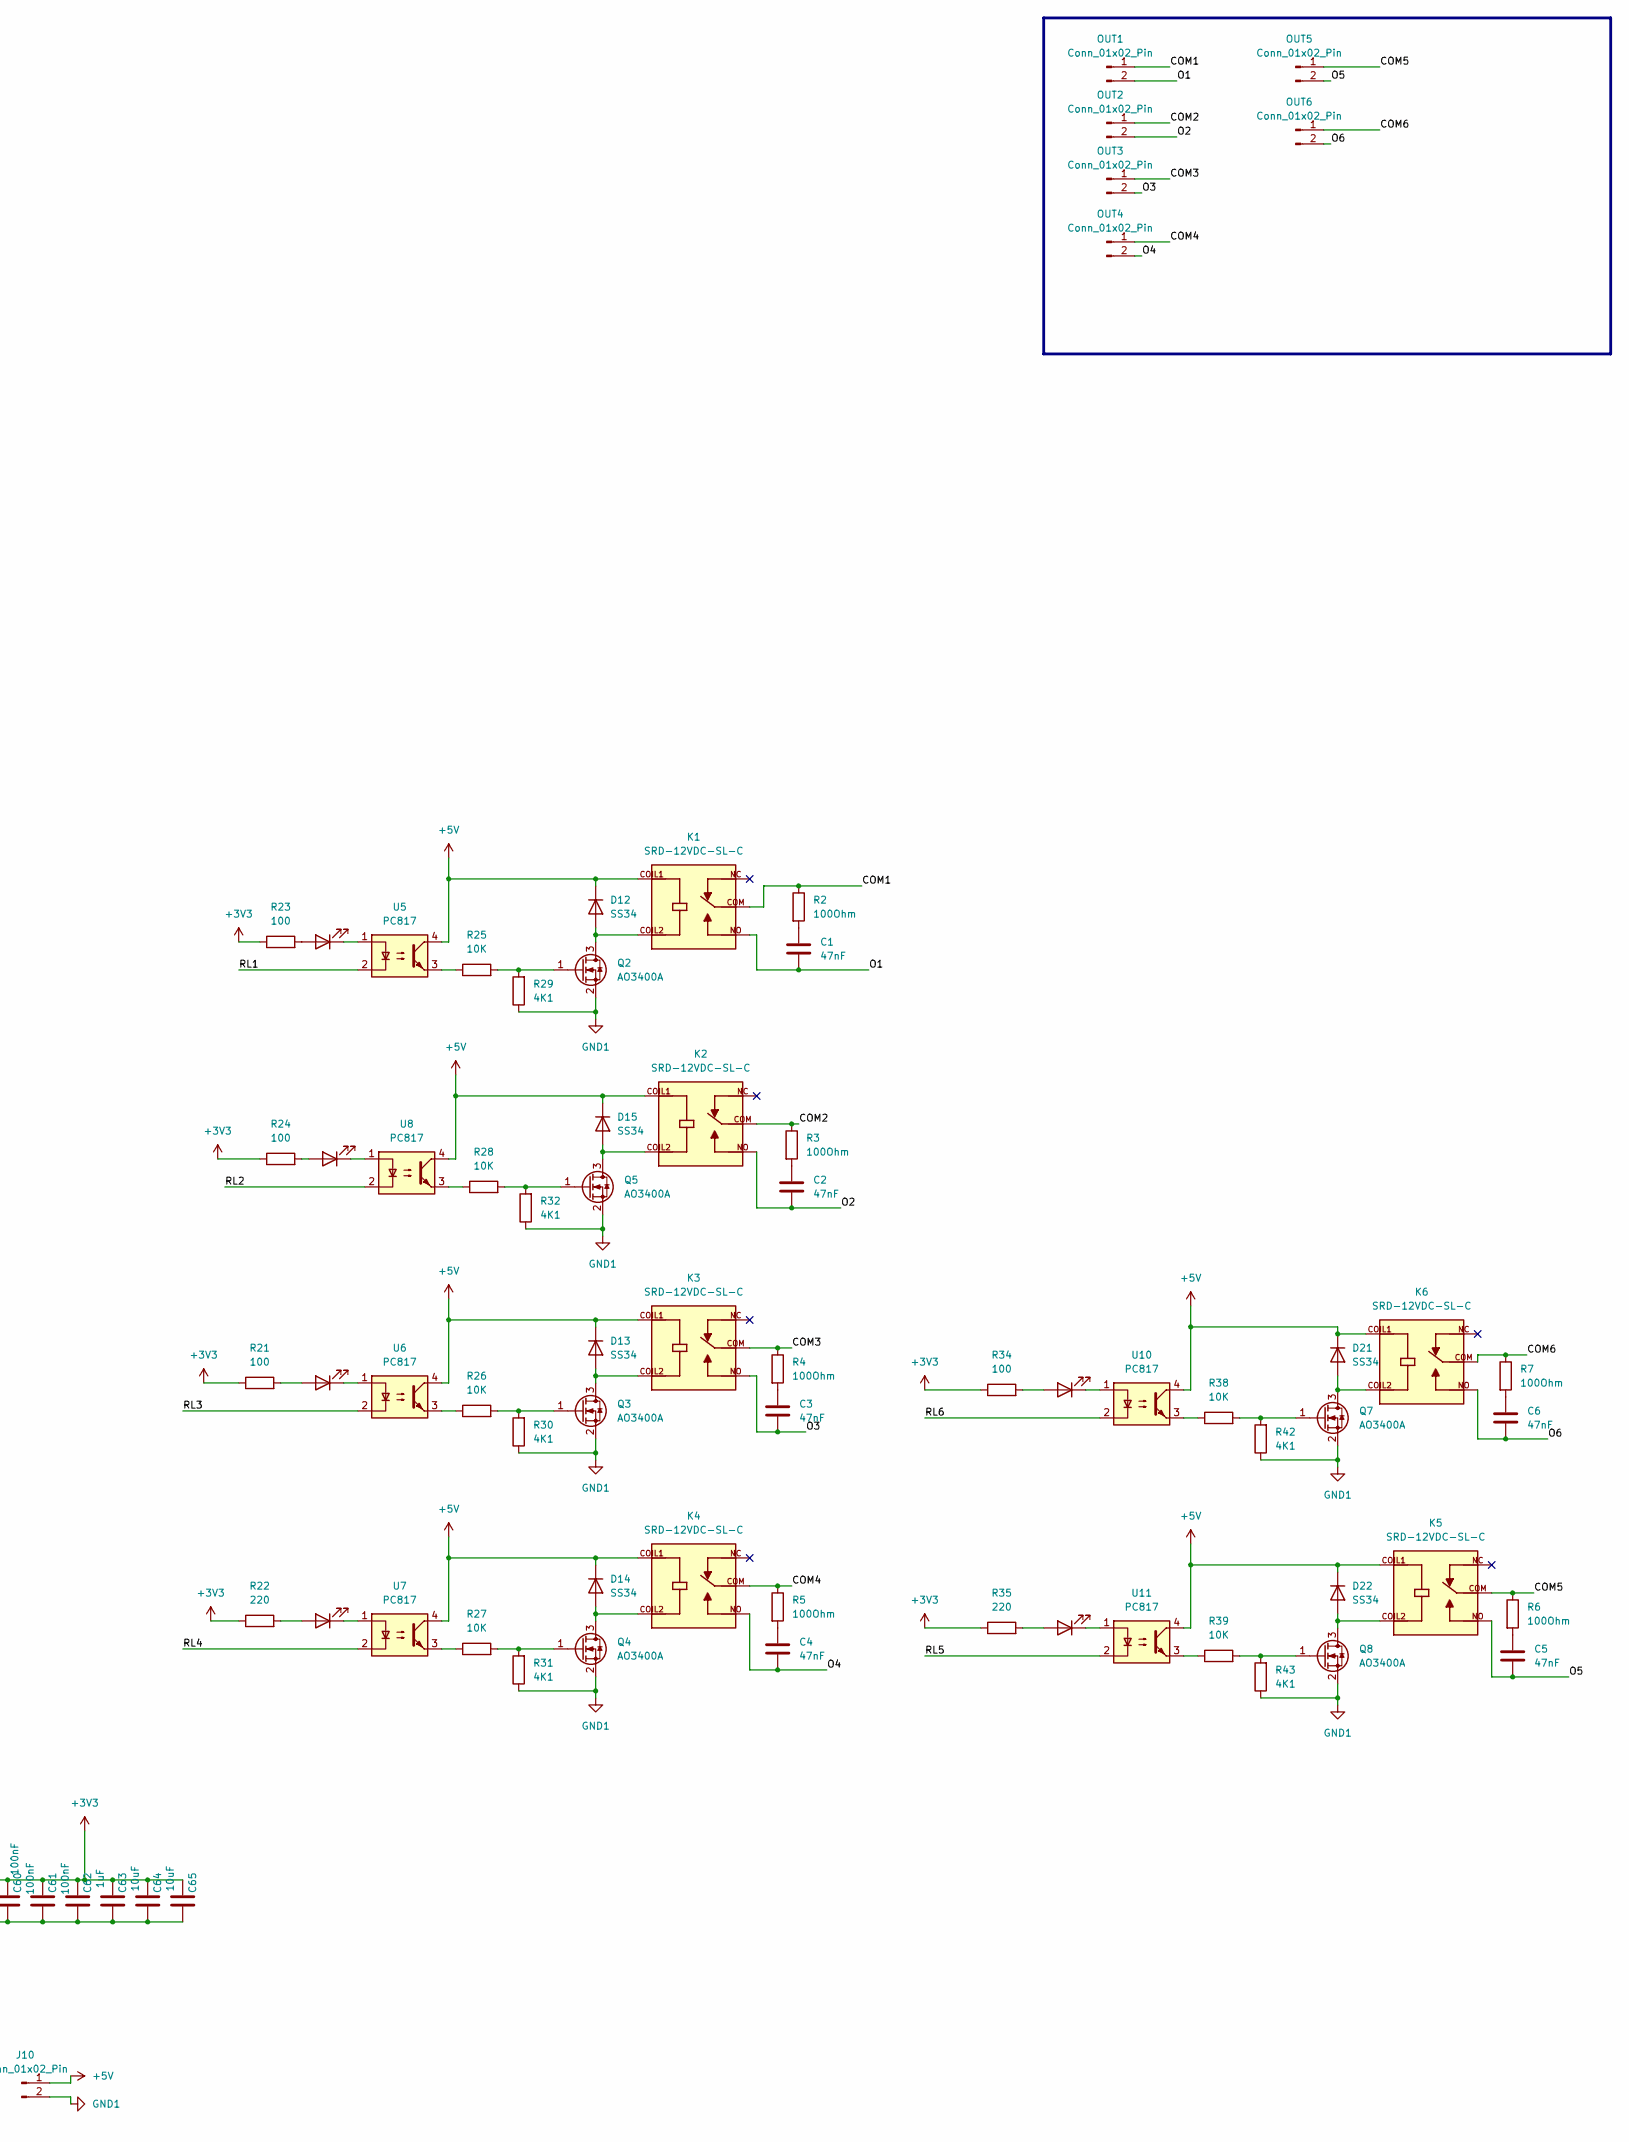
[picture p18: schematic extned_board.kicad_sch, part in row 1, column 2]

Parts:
C1, C2, C3, C4, C5, C6: 47nF; C_Disc_D10.5mm_W5.0mm_P7.50mm
C19, C32: 22nF; R_0805_2012Metric_Pad1.20x1.40mm_HandSolder
C29, C30: 22pF; R_0805_2012Metric_Pad1.20x1.40mm_HandSolder
C31, C45, C55, C56, C64, C65: 10uF; R_0805_2012Metric_Pad1.20x1.40mm_HandSolder
C33, C34, C35, C36, C37, C38, C39, C40, C41, C42, C43, C44, C46, C47, C48, C49, C50, C51, C52, C53, C57, C58, C59, C60, C61, C62: 100nF; R_0805_2012Metric_Pad1.20x1.40mm_HandSolder
C54, C63: 1uF; R_0805_2012Metric_Pad1.20x1.40mm_HandSolder
D8, D9, D10, D11, D17, D18, D32, D33, D34, D35, D36, D37, D38: LED; LED_0805_2012Metric_Pad1.15x1.40mm_HandSolder
D12, D13, D14, D15, D21, D22: SS34; D_SMA_Handsoldering
J4, J5, J6, J7, J8, J9: Conn_01x04_Pin; PinHeader_1x04_P2.54mm_Vertical
J10: Conn_01x02_Pin; PinHeader_1x02_P2.54mm_Vertical
JP1, JP2: SolderJumper_3_Open; SolderJumper-3_P1.3mm_Open_RoundedPad1.0x1.5mm_NumberLabels
K1, K2, K3, K4, K5, K6: SRD-12VDC-SL-C; RELAY_SRD-12VDC-SL-C; PARTREV 1.0
NT2: NetTie_2; NetTie-2_THT_Pad0.3mm
OUT1, OUT2, OUT3, OUT4, OUT5, OUT6: Conn_01x02_Pin; 2P
PS1: B0505S-2W; B0505S2W; Manufacturer_Part_Number B0505S-2W
Q2, Q3, Q4, Q5, Q7, Q8: AO3400A; SOT-23
R1: 120R; R_0805_2012Metric_Pad1.20x1.40mm_HandSolder
R2, R3, R4, R5, R6, R7: 100Ohm; R_Axial_DIN0414_L11.9mm_D4.5mm_P15.24mm_Horizontal
R21, R23, R24, R34: 100; R_0805_2012Metric_Pad1.20x1.40mm_HandSolder
R22, R35: 220; R_0805_2012Metric_Pad1.20x1.40mm_HandSolder
R25, R26, R27, R28, R38, R39, R45, R46, R51, R52, R53, R54, R55, R56, R57, R58, R63, R64, R66, R67, R68, R69, R70, R71, R74, R75: 10K; R_0805_2012Metric_Pad1.20x1.40mm_HandSolder
R29, R30, R31, R32, R42, R43: 4K1; R_0805_2012Metric_Pad1.20x1.40mm_HandSolder
R47, R48, R49, R50, R59, R60, R61, R62: 100R; R_0805_2012Metric_Pad1.20x1.40mm_HandSolder
R65, R80, R81: 1K; R_0805_2012Metric_Pad1.20x1.40mm_HandSolder
R77, R78, R79, R82, R83: 220R; R_0805_2012Metric_Pad1.20x1.40mm_HandSolder
ST-LINK1: Conn_01x04_Pin; PinHeader_1x04_P2.54mm_Vertical
SW_RST_STM2: SW_Push; SW_SPST_FSMSM
U2: LM385S-2.5; SOIC-8_3.9x4.9mm_P1.27mm
U3: SN65HVD230; SOIC-8_3.9x4.9mm_P1.27mm
U5, U6, U7, U8, U10, U11: PC817; DIL04
U13: STM32F103C8Tx; LQFP-48_7x7mm_P0.5mm
U14: ADS1256IDBR; SOP65P780X200-28N
U15, U16, U18, U19: MCP6002-xSN; SOIC8-N_MC_MCH-M
U20, U22: AMS1117-3.3; SOT-223-3_TabPin2
Y2: 8MHz; Resonator-2Pin_W7.0mm_H2.5mm
Y3: Crystal; Resonator-2Pin_W7.0mm_H2.5mm

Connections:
+3V3: C33.2, C59.2, C60.2, C61.2, C62.2, C63.2, C64.2, C65.2, D32.2 (A), D33.2 (A), D34.2 (A), D38.2 (A), JP1.1 (A), JP2.1 (A), R21.1, R22.1, R23.1, R24.1, R34.1, R35.1, R75.1, ST-LINK1.1, U3.3 (VCC), U13.1 (VBAT), U13.9 (VDDA), U13.24 (VDD), U13.36 (VDD), U13.48 (VDD), U22.2 (VO); also elsewhere on the board
+3V3_ADS: C45.1, C46.1, C51.2, C52.2, C53.2, C54.2, C55.2, C56.2, D37.2 (A), R45.1, R46.1, R74.2, U14.16 (DVDD), U20.2 (VO)
+5V: D12.1 (K), D13.1 (K), D14.1 (K), D15.1 (K), D21.1 (K), D22.1 (K), D35.2 (A), J10.1, K1.COIL1, K2.COIL1, K3.COIL1, K4.COIL1, K5.COIL1, K6.COIL1, PS1.1 (VIN), U5.4, U6.4, U7.4, U8.4, U10.4, U11.4
+5VD: C38.1, C39.1, C47.1, C48.1, C49.2, C50.2, C57.2, C58.2, D36.2 (A), PS1.6 (+VO), R65.1, U14.1 (AVDD), U15.8 (V+), U16.8 (V+), U18.8 (V+), U19.8 (V+), U20.3 (VI), U22.3 (VI)
/CAN-H: J4.2, J5.2, R1.1, U3.7 (CANH); also elsewhere on the board
/CAN-L: J4.3, J5.3, R1.2, U3.6 (CANL); also elsewhere on the board
/CAN_RX: U3.4 (R), U13.32 (PA11)
/CAN_TX: U3.1 (D), U13.33 (PA12)
/COM1: K1.COM, OUT1.1, R2.1
/COM2: K2.COM, OUT2.1, R3.1
/COM3: K3.COM, OUT3.1, R4.1
/COM4: K4.COM, OUT4.1, R5.1
/COM5: K5.COM, OUT5.1, R6.1
/COM6: K6.COM, OUT6.1, R7.1
/O1: C1.2, K1.NO, OUT1.2
/O2: C2.2, K2.NO, OUT2.2
/O3: C3.2, K3.NO, OUT3.2
/O4: C4.2, K4.NO, OUT4.2
/O5: C5.2, K5.NO, OUT5.2
/O6: C6.2, K6.NO, OUT6.2
/PC13: R77.2, U13.2 (PC13)
/PC14: R78.2, U13.3 (PC14)
/PC15: R79.2, U13.4 (PC15)
/RL1: U5.2, U13.28 (PB15)
/RL2: U8.2, U13.27 (PB14)
/RL3: U6.2, U13.26 (PB13)
/RL4: U7.2, U13.25 (PB12)
/RL5: U11.2, U13.22 (PB11)
/RL6: U10.2, U13.21 (PB10)
/S1: U14.6 (AIN0), U16.1
/S2: U14.7 (AIN1), U16.7
/S3: U14.8 (AIN2), U18.1
/S4: U14.9 (AIN3), U18.7
/S5: U14.10 (AIN4), U15.1
/S6: U14.11 (AIN5), U15.7
/S7: U14.12 (AIN6), U19.1
/S8: U14.13 (AIN7), U19.7
/SWCLK: ST-LINK1.3, U13.37 (PA14); also elsewhere on the board
/SWDIO: ST-LINK1.2, U13.34 (PA13); also elsewhere on the board
/VREFP: C31.2, C40.1, R51.1, R52.1, R55.2, R56.2, R63.1, R64.1, R65.2, R68.2, R69.2, U2.6 (K), U2.8 (K), U14.4 (VREFP)
/boot0: JP1.2 (C), U13.44 (BOOT0)
/boot1: JP2.2 (C), U13.20 (PB2)
CS: R46.2, U13.14 (PA4), U14.20 (~CS)
DIN: U13.17 (PA7), U14.23 (DIN)
DO: U13.16 (PA6), U14.22 (DOUT)
DRDY: R74.1, U13.18 (PB0), U14.21 (~DRDY)
GND1: J10.2, PS1.2 (GND), Q2.2 (S), Q3.2 (S), Q4.2 (S), Q5.2 (S), Q7.2 (S), Q8.2 (S), R29.1, R30.1, R31.1, R32.1, R42.1, R43.1, R80.2
GNDA: C31.1, C34.2, C35.2, C36.2, C37.2, C38.2, C39.2, C40.2, C41.2, C42.2, C43.2, C44.2, C47.2, C48.2, NT2.2, R53.2, R54.2, R57.1, R58.1, R66.2, R67.2, R70.1, R71.1, U2.4 (A), U14.2 (AGND), U14.3 (VREFN), U14.5 (AINCOM), U15.4 (V-), U16.4 (V-), U18.4 (V-), U19.4 (V-)
GNDD: C19.1, C29.2, C30.2, C32.1, C33.1, C45.2, C46.2, C49.1, C50.1, C51.1, C52.1, C53.1, C54.1, C55.1, C56.1, C57.1, C58.1, C60.1, C61.1, C62.1, C63.1, C64.1, C65.1, JP1.3 (B), JP2.3 (B), NT2.1, PS1.4 (0V), R81.2, R82.2, R83.2, ST-LINK1.4, SW_RST_STM2.1, U3.2 (GND), U3.8 (Rs), U13.8 (VSSA), U13.23 (VSS), U13.35 (VSS), U13.47 (VSS), U14.17 (DGND), U20.1 (GND), U22.1 (GND); also elsewhere on the board
unnamed: C1.1, R2.2
unnamed: C2.1, R3.2
unnamed: C3.1, R4.2
unnamed: C4.1, R5.2
unnamed: C5.1, R6.2
unnamed: C6.1, R7.2
unnamed: D8.2 (A), R23.2
unnamed: D8.1 (K), U5.1
unnamed: D9.2 (A), R21.2
unnamed: D9.1 (K), U6.1
unnamed: D10.2 (A), R22.2
unnamed: D10.1 (K), U7.1
unnamed: D11.2 (A), R24.2
unnamed: D11.1 (K), U8.1
unnamed: D12.2 (A), K1.COIL2, Q2.3 (D)
unnamed: D13.2 (A), K3.COIL2, Q3.3 (D)
unnamed: D14.2 (A), K4.COIL2, Q4.3 (D)
unnamed: D15.2 (A), K2.COIL2, Q5.3 (D)
unnamed: D17.2 (A), R34.2
unnamed: D17.1 (K), U10.1
unnamed: D18.2 (A), R35.2
unnamed: D18.1 (K), U11.1
unnamed: D21.2 (A), K6.COIL2, Q7.3 (D)
unnamed: D22.2 (A), K5.COIL2, Q8.3 (D)
unnamed: D32.1 (K), R77.1
unnamed: D33.1 (K), R78.1
unnamed: D34.1 (K), R79.1
unnamed: D35.1 (K), R80.1
unnamed: D36.1 (K), R81.1
unnamed: D37.1 (K), R82.1
unnamed: D38.1 (K), R83.1
unnamed: J4.1, J4.4, J5.1, J5.4
unnamed: C34.1, J6.1, R47.1, R51.2, R53.1, U15.3 (+)
unnamed: J6.2, R47.2, U15.2 (-)
unnamed: C36.1, J6.3, R48.1, R55.1, R57.2, U15.5 (+)
unnamed: J6.4, R48.2, U15.6 (-)
unnamed: C35.1, J7.1, R49.1, R52.2, R54.1, U16.3 (+)
unnamed: J7.2, R49.2, U16.2 (-)
unnamed: C37.1, J7.3, R50.1, R56.1, R58.2, U16.5 (+)
unnamed: J7.4, R50.2, U16.6 (-)
unnamed: C41.1, J8.1, R59.1, R63.2, R66.1, U18.3 (+)
unnamed: J8.2, R59.2, U18.2 (-)
unnamed: C43.1, J8.3, R60.1, R68.1, R70.2, U18.5 (+)
unnamed: J8.4, R60.2, U18.6 (-)
unnamed: C42.1, J9.1, R61.1, R64.2, R67.1, U19.3 (+)
unnamed: J9.2, R61.2, U19.2 (-)
unnamed: C44.1, J9.3, R62.1, R69.1, R71.2, U19.5 (+)
unnamed: J9.4, R62.2, U19.6 (-)
unnamed: Q2.1 (G), R25.2, R29.2
unnamed: Q3.1 (G), R26.2, R30.2
unnamed: Q4.1 (G), R27.2, R31.2
unnamed: Q5.1 (G), R28.2, R32.2
unnamed: Q7.1 (G), R38.2, R42.2
unnamed: Q8.1 (G), R39.2, R43.2
unnamed: R25.1, U5.3
unnamed: R26.1, U6.3
unnamed: R27.1, U7.3
unnamed: R28.1, U8.3
unnamed: R38.1, U10.3
unnamed: R39.1, U11.3
unnamed 109: C59.1, R75.2, SW_RST_STM2.2, U13.7 (NRST); also elsewhere on the board
unnamed: C19.2, U13.5 (PD0), Y3.2
unnamed: C32.2, U13.6 (PD1), Y3.1
unnamed: C29.1, U14.19 (XTAL1/CLKIN), Y2.2
unnamed: C30.1, U14.18 (XTAL2), Y2.1
RS: R45.2, U13.13 (PA3), U14.14 (~SYNC,_~PDWN), U14.15 (~RESET)
SCLK: U13.15 (PA5), U14.24 (SCLK)

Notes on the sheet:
PWR - DECOUPLING
OP-AMP
IC ADS1256
CONNECTOR

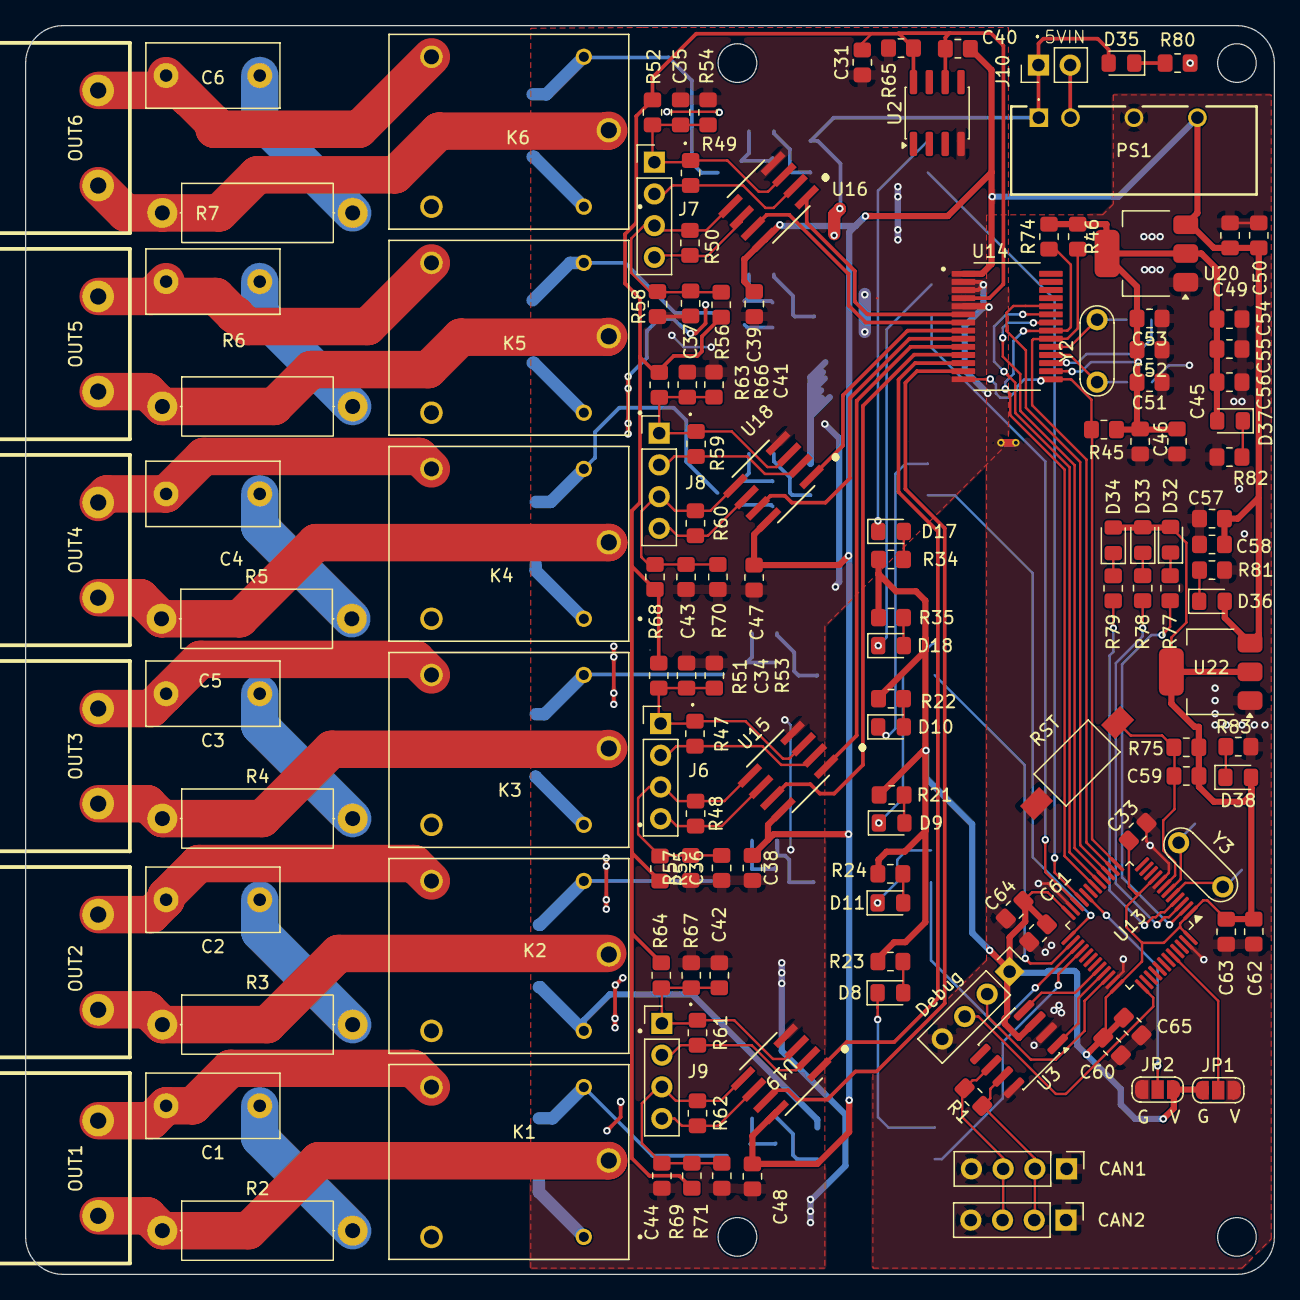
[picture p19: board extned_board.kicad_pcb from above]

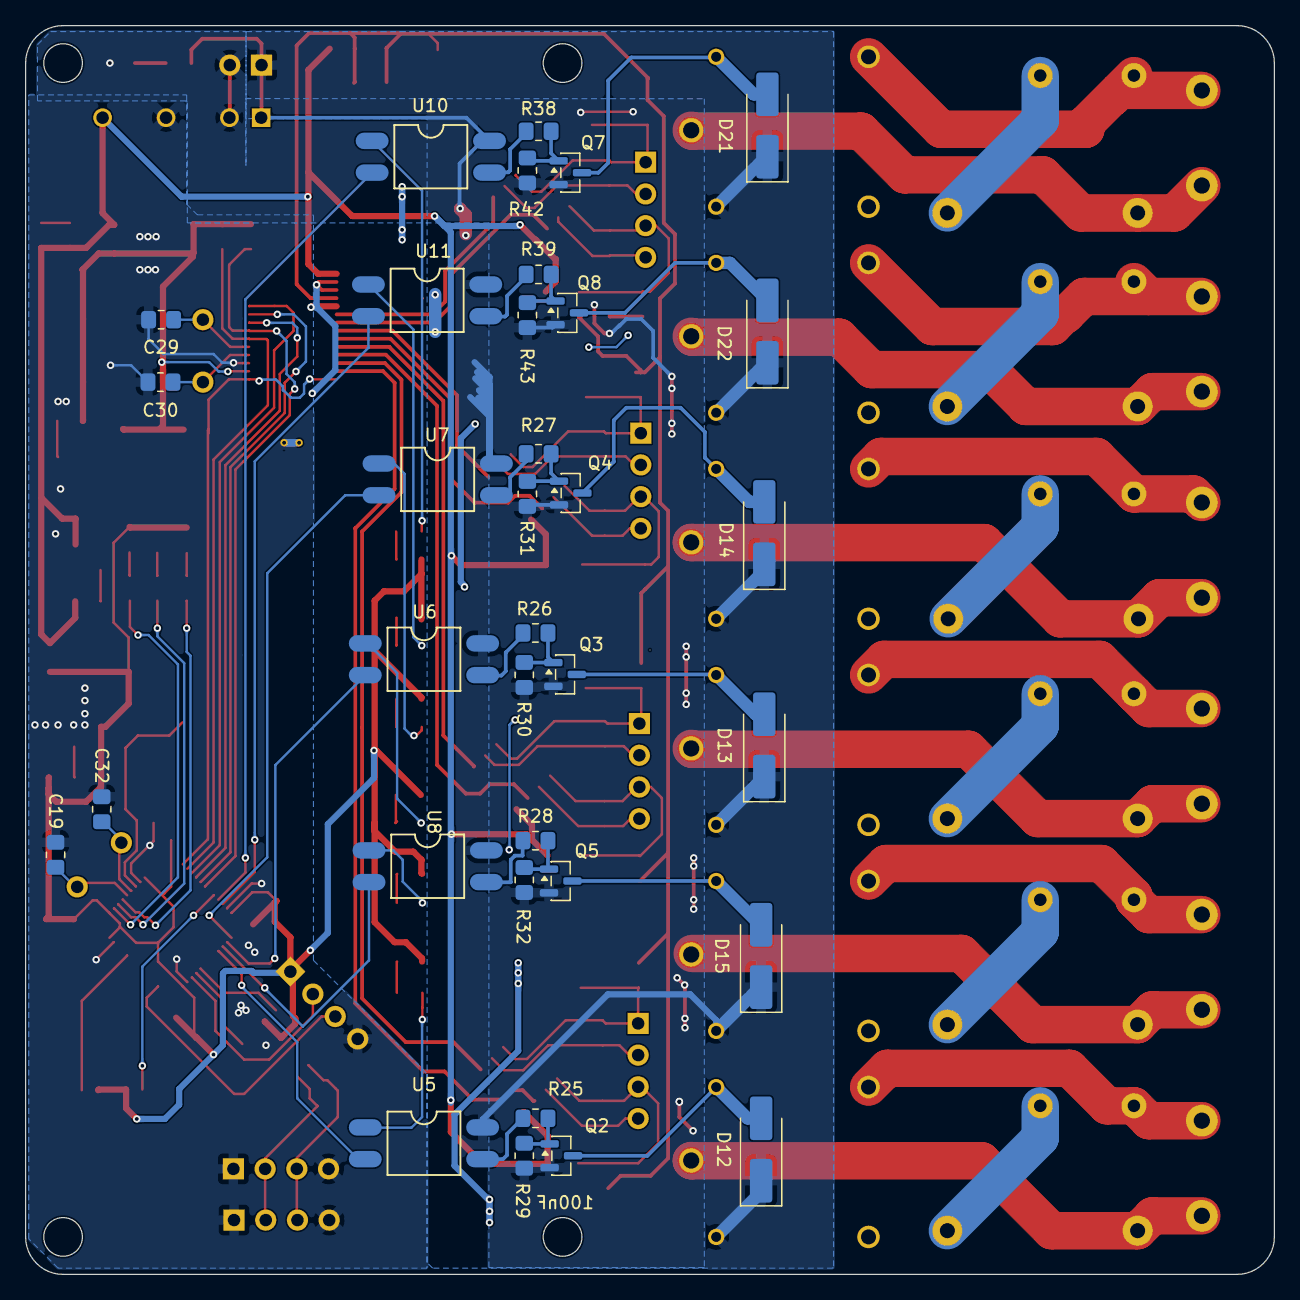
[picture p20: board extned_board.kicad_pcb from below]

Board: 2 copper layers, 100.0 x 100.0 mm, 173 parts (34 on the bottom side), 115 nets.

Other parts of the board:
CAN1, CAN2: Conn_01x04_Pin; PinHeader_1x04_P2.54mm_Vertical
Debug: Conn_01x04_Pin; PinHeader_1x04_P2.54mm_Vertical
RST: SW_Push; SW_SPST_FSMSM

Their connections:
+3V3: Debug.1; also elsewhere on the board
/CAN-H: CAN1.2, CAN2.2; also elsewhere on the board
/CAN-L: CAN1.3, CAN2.3; also elsewhere on the board
/SWCLK: Debug.3; also elsewhere on the board
/SWDIO: Debug.2; also elsewhere on the board
GNDD: CAN1.1, CAN1.4, CAN2.1, CAN2.4, Debug.4, RST.1; also elsewhere on the board
unnamed 109: RST.2; also elsewhere on the board

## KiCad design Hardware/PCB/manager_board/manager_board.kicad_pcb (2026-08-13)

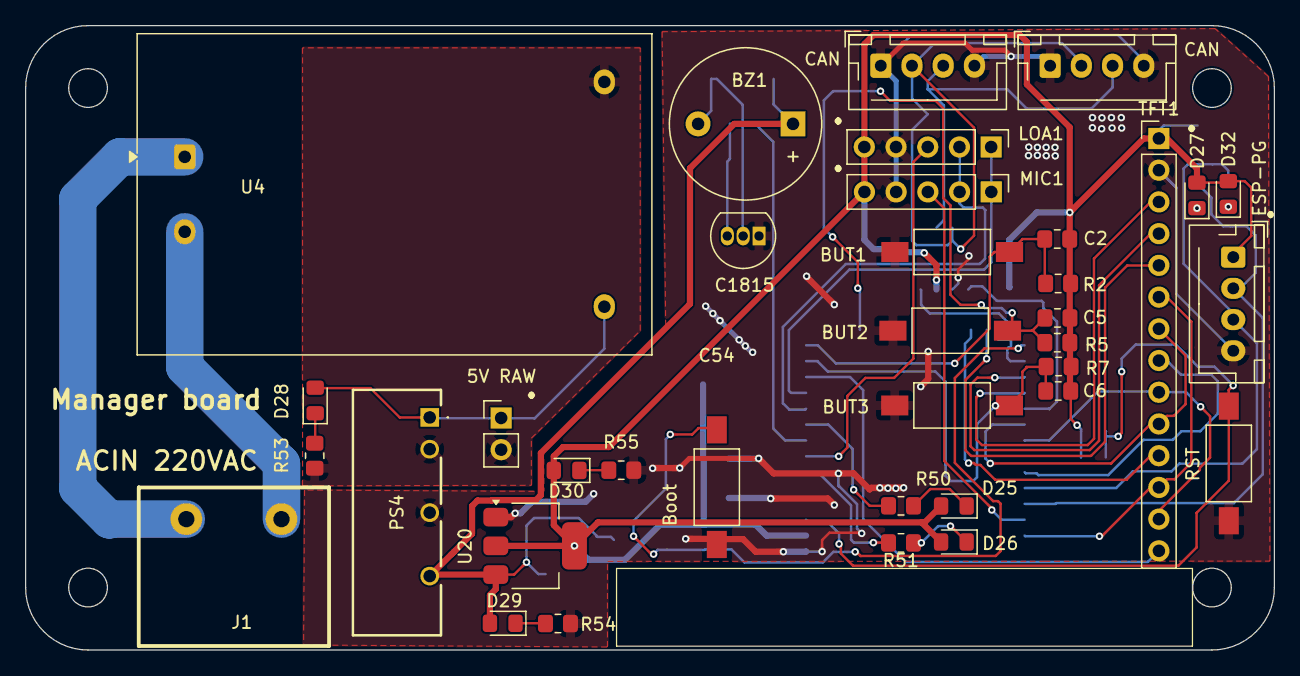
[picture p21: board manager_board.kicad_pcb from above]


Board: 2 copper layers, 100.0 x 50.0 mm, 57 parts (21 on the bottom side), 43 nets.

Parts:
5V RAW: Conn_01x02_Pin; PinHeader_1x02_P2.54mm_Vertical
BUT1, BUT2, BUT3: SW_Push; SW_SPST_FSMSM
BZ1: Buzzer; Buzzer_12x9.5RM7.6
Boot: SW_Push; SW_SPST_FSMSM
C2, C3, C5, C6, C49, C50, C51, C52, C53, C57: 100nF; R_0805_2012Metric_Pad1.20x1.40mm_HandSolder
C15, C55, C56: 10uF; R_0805_2012Metric_Pad1.20x1.40mm_HandSolder
C54: 1uF; R_0805_2012Metric_Pad1.20x1.40mm_HandSolder
C1815: 2SC1815; TO-92_Inline
CAN: Conn_01x04_Pin; JST_XH_B4B-XH-AM_1x04_P2.50mm_Vertical
CAN#2: Conn_01x04_Pin; JST_XH_B4B-XH-AM_1x04_P2.50mm_Vertical
D1: 1N4007; D_SMA_Handsoldering
D25, D26, D27, D28, D29, D30, D32: LED; LED_0805_2012Metric_Pad1.15x1.40mm_HandSolder
ESP-PG: Conn_01x04_Pin; JST_XH_B4B-XH-AM_1x04_P2.50mm_Vertical
J1: KF7.62-2P; 2P
LOA1: Conn_01x05_Pin; PinHeader_1x05_P2.54mm_Vertical
MIC1: Conn_01x05_Pin; PinHeader_1x05_P2.54mm_Vertical
PS4: B0505S-2W; B0505S2W
R2, R3, R5, R6, R7, R9: 10K; R_0805_2012Metric_Pad1.20x1.40mm_HandSolder
R8, R52, R53, R54, R56: 1K; R_0805_2012Metric_Pad1.20x1.40mm_HandSolder
R50, R51, R55: 220R; R_0805_2012Metric_Pad1.20x1.40mm_HandSolder
R57: 120R; R_0805_2012Metric_Pad1.20x1.40mm_HandSolder
RST: SW_Push; SW_SPST_FSMSM
SN65HVD: SN65HVD230; SOIC-8_3.9x4.9mm_P1.27mm
TFT1: Conn_01x14_Pin; PinHeader_1x14_P2.54mm_Vertical
U1: ESP32-WROOM-32D
U4: HLK-5M05; Converter_ACDC_Hi-Link_HLK-5Mxx
U20: AMS1117-3.3; SOT-223-3_TabPin2

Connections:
+3V3_ESP: C2.2, C3.2, C5.2, C6.2, C15.2, C51.2, C52.2, C53.2, C54.2, C55.2, C56.2, C57.2, D25.2 (A), D26.2 (A), D27.2 (A), D30.2 (A), D32.2 (A), ESP-PG.1, LOA1.5, MIC1.5, R2.1, R3.1, R5.1, R6.1, R7.1, SN65HVD.3 (VCC), TFT1.1, U1.2 (VDD), U20.2 (VO)
+5V: 5V RAW.1, D28.2 (A), PS4.1 (VIN), U4.4 (+Vout)
+5VD1: BZ1.1 (+), C49.2, C50.2, D1.1 (K), D29.2 (A), PS4.6 (+VO), U20.3 (VI)
/BUT1: BUT1.2, C2.1, R2.2, U1.14 (IO12)
/BUT2: BUT2.2, C5.1, R5.2, U1.16 (IO13)
/BUT3: BUT3.2, C6.1, R7.2, U1.13 (IO14)
/CAN-H: CAN.2, CAN#2.2, R57.2, SN65HVD.7 (CANH)
/CAN-L: CAN.3, CAN#2.3, R57.1, SN65HVD.6 (CANL)
/CAN_RX: SN65HVD.4 (R), U1.26 (IO4)
/CAN_TX: SN65HVD.1 (D), U1.29 (IO5)
/I2S_BCLK: LOA1.1, MIC1.1, U1.11 (IO26)
/I2S_DIN: LOA1.3, U1.7 (IO35)
/I2S_DOUT: MIC1.3, U1.36 (IO22)
/I2S_WS: LOA1.2, MIC1.2, U1.10 (IO25)
/LED1: R50.2, U1.9 (IO33)
/LED2: R51.2, U1.6 (IO34)
/RX0: ESP-PG.3, R56.2, U1.34 (RXD0/IO3)
/TFT_CS: TFT1.3, U1.28 (IO17)
/TFT_DC: TFT1.5, U1.24 (IO2)
/TFT_LED: TFT1.8, U1.33 (IO21)
/TFT_MISO: TFT1.9, TFT1.13, U1.31 (IO19)
/TFT_MOSI: TFT1.6, TFT1.12, U1.37 (IO23)
/TFT_RS: TFT1.4, U1.27 (IO16)
/TFT_SCK: TFT1.7, TFT1.10, U1.30 (IO18)
/TO_CS: TFT1.11, U1.23 (IO15)
/TO_IRQ: TFT1.14, U1.12 (IO27)
/TX0: ESP-PG.2, R52.2, U1.35 (TXD0/IO1)
/buzz: R8.1, U1.8 (IO32)
GND1: 5V RAW.2, PS4.2 (GND), R53.2, U4.3 (-Vout)
GNDD: BUT1.1, BUT2.1, BUT3.1, Boot.2, C15.1, C49.1, C50.1, C51.1, C52.1, C53.1, C54.1, C55.1, C56.1, C1815.1 (E), CAN.1, CAN.4, CAN#2.1, CAN#2.4, ESP-PG.4, LOA1.4, MIC1.4, PS4.4 (0V), R9.2, R54.2, R55.2, RST.1, SN65HVD.2 (GND), SN65HVD.8 (Rs), TFT1.2, U1.1 (GND), U1.15 (GND), U1.38 (GND), U1.39 (GND), U20.1 (GND)
unnamed: BZ1.2 (-), C1815.2 (C), D1.2 (A)
unnamed: D25.1 (K), R50.1
unnamed: D26.1 (K), R51.1
unnamed: D27.1 (K), R52.1
unnamed: D28.1 (K), R53.1
unnamed: D29.1 (K), R54.1
unnamed: D30.1 (K), R55.1
unnamed: D32.1 (K), R56.1
unnamed: C1815.3 (B), R8.2, R9.1
unnamed: C3.1, R3.2, RST.2, U1.3 (EN)
unnamed: Boot.1, C57.1, R6.2, U1.25 (IO0)
unnamed: J1.2, U4.1 (AC/L)
unnamed: J1.1, U4.2 (AC/N)

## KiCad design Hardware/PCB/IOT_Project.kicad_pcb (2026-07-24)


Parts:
BZ1: Buzzer; Buzzer_12x9.5RM7.6
Boot1: SW_Push; SW_SPST_EVQPE1
C1, C3, C4, C5, C6, C9, C10, C11, C12, C13, C14: 100nF; C_0805_2012Metric_Pad1.18x1.45mm_HandSolder
D2, D3, D4, D5, D6: LED; LED_0805_2012Metric_Pad1.15x1.40mm_HandSolder
D7: D; D_0805_2012Metric_Pad1.15x1.40mm_HandSolder
J1: Conn_01x04_Pin; PinSocket_1x04_P2.54mm_Horizontal
J2: POWER IN 3V3; PinSocket_1x02_P2.54mm_Horizontal
J3: TFT_2.4; PinSocket_1x08_P2.54mm_Vertical
J4: Program; PinSocket_1x04_P2.54mm_Horizontal
Q1: 2SC1815; TO-92_Inline
R1, R4, R5, R6, R7, R8, R9: 10K; R_0805_2012Metric_Pad1.20x1.40mm_HandSolder
R2, R3, R10, R11, R12: 330R; R_0805_2012Metric_Pad1.20x1.40mm_HandSolder
R13: 1K; R_0805_2012Metric_Pad1.20x1.40mm_HandSolder
RST1: SW_Push; SW_SPST_EVQPE1
SW2, SW3, SW4, SW5, SW6: SW_Push; SW_SPST_EVQPE1
U1: ESP32-WROOM-32D

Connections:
+3.3V: BZ1.1 (+), C3.1, C4.1, C5.1, C6.1, D7.1 (K), J1.1, J2.1, J3.1, J4.1, R1.2, R2.2, R3.2, R4.2, R5.2, R6.2, R7.2, R8.2, R9.2, R10.2, R11.2, R12.2, U1.2 (VDD)
BL: J3.8, U1.8 (IO32)
BOOT: Boot1.2, C1.1, R1.1, U1.25 (IO0)
BUT1: C10.1, R5.1, SW2.2, U1.9 (IO33)
BUT2: C11.1, R6.1, SW3.2, U1.6 (IO34)
BUT3: C12.1, R7.1, SW4.2, U1.7 (IO35)
BUT4: C13.1, R8.1, SW5.2, U1.4 (SENSOR_VP)
BUT5: C14.1, R9.1, SW6.2, U1.5 (SENSOR_VN)
Buzz: R13.2, U1.16 (IO13)
CLK: J3.7, U1.30 (IO18)
CS: J3.3, U1.29 (IO5)
DC: J3.5, U1.26 (IO4)
GND: Boot1.1, C1.2, C3.2, C4.2, C5.2, C6.2, C9.2, C10.2, C11.2, C12.2, C13.2, C14.2, D2.1 (K), J1.4, J2.2, J3.2, J4.4, Q1.1 (E), RST1.1, SW2.1, SW3.1, SW4.1, SW5.1, SW6.1, U1.1 (GND), U1.15 (GND), U1.38 (GND), U1.39 (GND)
Led_BLE: D4.1 (K), U1.11 (IO26)
Led_ERR: D5.1 (K), U1.12 (IO27)
Led_RUN: D6.1 (K), U1.13 (IO14)
Led_WF: D3.1 (K), U1.10 (IO25)
MOSI: J3.6, U1.37 (IO23)
unnamed: BZ1.2 (-), D7.2 (A), Q1.2 (C)
unnamed: D2.2 (A), R2.1
unnamed: D3.2 (A), R3.1
unnamed: D4.2 (A), R10.1
unnamed: D5.2 (A), R11.1
unnamed: D6.2 (A), R12.1
unnamed: Q1.3 (B), R13.1
RST: J3.4, U1.23 (IO15)
RST_BUT: C9.1, R4.1, RST1.2, U1.3 (EN)
RX: J1.3, U1.28 (IO17)
RX0: J4.3, U1.35 (TXD0/IO1)
TX: J1.2, U1.27 (IO16)
TX0: J4.2, U1.34 (RXD0/IO3)

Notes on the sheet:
Power
Button

Board: 2 copper layers, 44 parts (0 on the bottom side), 31 nets, no tracks yet.

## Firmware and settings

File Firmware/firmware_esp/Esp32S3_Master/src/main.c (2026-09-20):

/*
 * ESP32-S3 N16R8 Voice Assistant Firmware (ESP-SR / ESP-Skainet)
 * DTV Energy Ecosystem - Smart Voice Control
 */

#include <stdio.h>
#include <stdlib.h>
#include <string.h>
#include "freertos/FreeRTOS.h"
#include "freertos/task.h"
#include "esp_system.h"
#include "esp_log.h"
#include "esp_heap_caps.h"
#include "nvs_flash.h"
#include "driver/gpio.h"
#include "driver/i2s_std.h"

#include "esp_afe_sr_models.h"
#include "esp_afe_sr_iface.h"
#include "esp_nsn_models.h"
#include "model_path.h"

#include "esp_wifi.h"
#include "esp_now.h"
#include "esp_mac.h"
#include "esp_now_protocol.h"
#include "esp_http_server.h"
#include "esp_timer.h"
#include "esp_ota_ops.h"
#include "lwip/sockets.h"
#include "lwip/netdb.h"

/* ─── Audio Streaming & MQTT Relay Modules ─── */
#include "ws_audio_client.h"
#include "mqtt_relay.h"
#include "audio_feedback.h"
#include "ota_updater.h"
#include "device_identity.h"

static void add_cors_headers(httpd_req_t *req);
static esp_err_t api_provision_post_handler(httpd_req_t *req);
static esp_err_t api_factory_reset_post_handler(httpd_req_t *req);


#ifndef MIN
#define MIN(a,b) (((a)<(b))?(a):(b))
#endif

static const char *TAG = "ESP32S3_VOICE_MASTER";

static uint8_t broadcast_mac[6] = {0xFF, 0xFF, 0xFF, 0xFF, 0xFF, 0xFF};

// SCHEMATIC SYNC: U1 ESP32-S3-WROOM-1
// Pin 25: IO48 -> LED1 (System Status / Wi-Fi / MQTT)
// Pin 24: IO47 -> LED2 (Voice / Activity Indicator)
// Pin 39: IO1  -> BUT1 (Local Toggle Relay 1)
// Pin 15: IO3  -> BUT2 (Local Toggle Relay 2)

#define LED1_GPIO GPIO_NUM_48
#define LED2_GPIO GPIO_NUM_47

#define BUT1_GPIO GPIO_NUM_1
#define BUT2_GPIO GPIO_NUM_3

static void init_status_leds(void)
{
    gpio_config_t io_conf = {
        .intr_type = GPIO_INTR_DISABLE,
        .mode = GPIO_MODE_OUTPUT,
        .pin_bit_mask = (1ULL << LED1_GPIO) | (1ULL << LED2_GPIO),
        .pull_down_en = GPIO_PULLDOWN_DISABLE,
        .pull_up_en = GPIO_PULLUP_DISABLE,
    };
    gpio_config(&io_conf);
    gpio_set_level(LED1_GPIO, 0);
    gpio_set_level(LED2_GPIO, 0);
    ESP_LOGI(TAG, "Hardware Status LEDs initialized (LED1=GPIO%d, LED2=GPIO%d) - Schematic Match OK!",
             LED1_GPIO, LED2_GPIO);
}

void led1_set(bool on)
{
    gpio_set_level(LED1_GPIO, on ? 1 : 0);
}

void led2_set(bool on)
{
    gpio_set_level(LED2_GPIO, on ? 1 : 0);
}


/**
 * @brief Physical Push Buttons Task: BUT1 (IO1) -> Toggle RL1, BUT2 (IO3) -> Toggle RL2
 */
static void button_monitor_task(void *arg)
{
    gpio_config_t btn_conf = {
        .intr_type = GPIO_INTR_DISABLE,
        .mode = GPIO_MODE_INPUT,
        .pin_bit_mask = (1ULL << BUT1_GPIO) | (1ULL << BUT2_GPIO),
        .pull_up_en = GPIO_PULLUP_ENABLE,
        .pull_down_en = GPIO_PULLDOWN_DISABLE,
    };
    gpio_config(&btn_conf);
    ESP_LOGI(TAG, "Physical Buttons Task Started (BUT1=GPIO%d -> RL1, BUT2=GPIO%d -> RL2)",
             BUT1_GPIO, BUT2_GPIO);

    int prev_b1 = 1, prev_b2 = 1;
    int b1_hold_ms = 0;
    while (1) {
        int b1 = gpio_get_level(BUT1_GPIO);
        int b2 = gpio_get_level(BUT2_GPIO);

        if (b1 == 0) {
            b1_hold_ms += 50;
            if (b1_hold_ms == 3000) {
                ESP_LOGW(TAG, "⚠️ BUT1 Held 3s... Continue holding to 10s for Factory Reset");
                audio_feedback_play(AUDIO_FB_TING);
                led2_set(true);
            } else if (b1_hold_ms == 7000) {
                ESP_LOGW(TAG, "⚠️ BUT1 Held 7s... Releasing in 3s will Factory Reset!");
                audio_feedback_play(AUDIO_FB_TING);
                led1_set(true); led2_set(true);
            } else if (b1_hold_ms >= 10000) {
                ESP_LOGW(TAG, "⚠️ BUT1 Held 10s! Executing Commercial Factory Reset (Keeping Device ID)...");
                led1_set(false); led2_set(false);
                audio_feedback_play(AUDIO_FB_WRONG);
                device_identity_factory_reset();
            }
        } else {
            if (prev_b1 == 0 && b1_hold_ms < 3000 && b1_hold_ms > 50) {
                // Short press: Toggle Relay 1
                bool current = mqtt_relay_get_state(1);
                ESP_LOGI(TAG, "🔘 BUT1 Pressed! Toggling RL1 (GPIO4) -> %s", !current ? "ON" : "OFF");
                mqtt_relay_set(1, !current);
                audio_feedback_play(AUDIO_FB_TING);
                led2_set(true);
                vTaskDelay(pdMS_TO_TICKS(150));
                led2_set(false);
            }
            b1_hold_ms = 0;
        }

        if (prev_b2 == 1 && b2 == 0) {
            // BUT2 Pressed! Toggle Relay 2
            bool current = mqtt_relay_get_state(2);
            ESP_LOGI(TAG, "🔘 BUT2 Pressed! Toggling RL2 (GPIO5) -> %s", !current ? "ON" : "OFF");
            mqtt_relay_set(2, !current);
            audio_feedback_play(AUDIO_FB_TING);
            led2_set(true);
            vTaskDelay(pdMS_TO_TICKS(150));
            led2_set(false);
        }

        prev_b1 = b1;
        prev_b2 = b2;
        vTaskDelay(pdMS_TO_TICKS(50));
    }
}


static void send_esp_now_request_power(void);



// Live Telemetry Cache for Web Dashboard & App
static float live_voltage = 0.0f;
static float live_current = 0.0f;
static float live_power   = 0.0f;
static float live_energy  = 0.0f;
static float live_freq    = 50.0f;
static float live_pf      = 1.0f;
static uint32_t last_telemetry_ms = 0;



// ============================================================================
// I2S MICROPHONE PIN DEFINITIONS (INMP441 MEMS Mic - Matches Schematic)
// ============================================================================
#define MIC_I2S_PORT         I2S_NUM_0
#define MIC_I2S_GPIO_BCLK    GPIO_NUM_15   // Schematic: MIC_BCLK (IO15)
#define MIC_I2S_GPIO_WS      GPIO_NUM_16   // Schematic: MIC_WS (IO16)
#define MIC_I2S_GPIO_DIN     GPIO_NUM_8    // Schematic: MIC_DIN (IO8)


// ============================================================================
// I2S SPEAKER / DAC PIN DEFINITIONS (MAX98357A I2S DAC/AMP - Matches Schematic)
// ============================================================================
#define SPK_I2S_PORT         I2S_NUM_1
#define SPK_I2S_GPIO_BCLK    GPIO_NUM_17   // Schematic: SP_BCLK (IO17)
#define SPK_I2S_GPIO_WS      GPIO_NUM_18   // Schematic: SP_LRC (IO18)
#define SPK_I2S_GPIO_DOUT    GPIO_NUM_21   // Schematic: SP_DOUT (IO21)
#define SPK_SD_GPIO          GPIO_NUM_2    // Schematic: SP_SD (IO2 - Amp Shutdown/Enable)

static i2s_chan_handle_t rx_handle = NULL;
/* Non-static: shared with ws_audio_client.c for speaker playback */
i2s_chan_handle_t tx_handle = NULL;
static const esp_afe_sr_iface_t *afe_handle = &ESP_AFE_SR_HANDLE;
static esp_afe_sr_data_t *afe_data = NULL;
static volatile bool is_listening = false;


/**
 * @brief Initialize I2S Microphone Channel (16kHz, 16-bit Mono/Stereo)
 */
static esp_err_t init_i2s_microphone(void)
{
    ESP_LOGI(TAG, "Initializing INMP441 I2S Microphone (BCLK:%d, WS:%d, DIN:%d)...", 
             MIC_I2S_GPIO_BCLK, MIC_I2S_GPIO_WS, MIC_I2S_GPIO_DIN);

    i2s_chan_config_t chan_cfg = {
        .id = MIC_I2S_PORT,
        .role = I2S_ROLE_MASTER,
        .dma_desc_num = 6,
        .dma_frame_num = 240,
        .auto_clear = true,
    };
    ESP_ERROR_CHECK(i2s_new_channel(&chan_cfg, NULL, &rx_handle));

    i2s_std_config_t std_cfg = {
        .clk_cfg = I2S_STD_CLK_DEFAULT_CONFIG(16000),
        .slot_cfg = I2S_STD_PHILIPS_SLOT_DEFAULT_CONFIG(I2S_DATA_BIT_WIDTH_32BIT, I2S_SLOT_MODE_STEREO),
        .gpio_cfg = {
            .mclk = I2S_GPIO_UNUSED,
            .bclk = MIC_I2S_GPIO_BCLK,
            .ws   = MIC_I2S_GPIO_WS,
            .dout = I2S_GPIO_UNUSED,
            .din  = MIC_I2S_GPIO_DIN,
            .invert_flags = {
                .mclk_inv = false,
                .bclk_inv = false,
                .ws_inv   = false,
            },
        },
    };

    ESP_ERROR_CHECK(i2s_channel_init_std_mode(rx_handle, &std_cfg));
    ESP_ERROR_CHECK(i2s_channel_enable(rx_handle));

    ESP_LOGI(TAG, "INMP441 I2S Microphone successfully initialized and enabled!");
    return ESP_OK;
}

typedef struct {
    int anomaly_score;
    char pattern_name[64];
    char recommendation[128];
    uint32_t inference_us;
} tinyml_result_t;

static tinyml_result_t current_tinyml_res = {
    .anomaly_score = 5,
    .pattern_name = "Tải Điện Bình Thường & Tối Ưu",
    .recommendation = "Mô hình TinyML ESP32-S3 N16R8 đánh giá hệ thống hoạt động an toàn.",
    .inference_us = 135
};

static void run_tinyml_inference(float v, float i, float p, float pf) {
    int64_t start = esp_timer_get_time();
    static float prev_p = 0;
    float delta_p = p - prev_p;
    prev_p = p;

    if (p > 800.0f && delta_p > 250.0f) {
        current_tinyml_res.anomaly_score = 80;
        snprintf(current_tinyml_res.pattern_name, sizeof(current_tinyml_res.pattern_name), "Dòng Khởi Động Động Cơ / Máy Nén");
        snprintf(current_tinyml_res.recommendation, sizeof(current_tinyml_res.recommendation), "Phát hiện đỉnh công suất vọt (+%.0fW). Đang chạy tải điều hòa/máy bơm.", delta_p);
    } else if (pf > 0.01f && pf < 0.80f && i > 0.4f) {
        current_tinyml_res.anomaly_score = 50;
        snprintf(current_tinyml_res.pattern_name, sizeof(current_tinyml_res.pattern_name), "Hệ Số Cos φ Thấp (%.2f)", pf);
        snprintf(current_tinyml_res.recommendation, sizeof(current_tinyml_res.recommendation), "Phát hiện tải cảm quạt/động cơ. Nên gắn tụ bù để tối ưu tiền điện EVN.");
    } else if (p > 0.0f && p < 35.0f && i > 0.08f) {
        current_tinyml_res.anomaly_score = 25;
        snprintf(current_tinyml_res.pattern_name, sizeof(current_tinyml_res.pattern_name), "Tải Tiêu Thụ Ngầm (Standby)");
        snprintf(current_tinyml_res.recommendation, sizeof(current_tinyml_res.recommendation), "Công suất thấp %.1fW. Khuyên tắt công tắc thiết bị khi không dùng.", p);
    } else {
        current_tinyml_res.anomaly_score = 5;
        snprintf(current_tinyml_res.pattern_name, sizeof(current_tinyml_res.pattern_name), "Tải Điện Bình Thường & Tối Ưu");
        snprintf(current_tinyml_res.recommendation, sizeof(current_tinyml_res.recommendation), "Mô hình TinyML ESP32-S3 N16R8 đánh giá hệ thống hoạt động an toàn.");
    }
    int64_t end = esp_timer_get_time();
    current_tinyml_res.inference_us = (uint32_t)(end - start + 120);
}

static esp_err_t api_tinyml_get_handler(httpd_req_t *req)
{
    add_cors_headers(req);
    char json_resp[384];
    snprintf(json_resp, sizeof(json_resp),
             "{\"anomaly_score\":%d,\"pattern_name\":\"%s\",\"recommendation\":\"%s\",\"inference_us\":%ld,\"wakenet\":\"Hi ESP\"}",
             current_tinyml_res.anomaly_score,
             current_tinyml_res.pattern_name,
             current_tinyml_res.recommendation,
             (long)current_tinyml_res.inference_us);
    httpd_resp_set_type(req, "application/json");
    return httpd_resp_send(req, json_resp, HTTPD_RESP_USE_STRLEN);
}

/**
 * @brief ESP-NOW Data Receive Callback (Handles packets from ESP32 WROOM Energy Slave)
 */
static void esp_now_recv_callback(const esp_now_recv_info_t *recv_info, const uint8_t *data, int len)
{
    if (len < sizeof(esp_now_packet_t)) {
        ESP_LOGW(TAG, "Received incomplete ESP-NOW packet (%d bytes)", len);
        return;
    }

    const esp_now_packet_t *pkt = (const esp_now_packet_t *)data;

    if (pkt->msg_type == MSG_TYPE_RESP_POWER_STATUS) {
        live_voltage = pkt->voltage;
        live_current = pkt->current;
        live_power   = pkt->power;
        live_energy  = pkt->energy;
        live_freq    = pkt->frequency;
        live_pf      = pkt->pf;
        last_telemetry_ms = (uint32_t)(xTaskGetTickCount() * portTICK_PERIOD_MS);

        // Run local TinyML AI inference model on incoming waveform metrics
        run_tinyml_inference(live_voltage, live_current, live_power, live_pf);

        // Pulse status LED on successful packet reception
        led2_set(true);
        vTaskDelay(pdMS_TO_TICKS(10));
        led2_set(false);

        ESP_LOGI(TAG, "=================================================");
        ESP_LOGI(TAG, "⚡ LIVE POWER METRICS FROM ESP32 WROOM SLAVE:");
        ESP_LOGI(TAG, "  - Voltage    : %.2f V", pkt->voltage);
        ESP_LOGI(TAG, "  - Current    : %.3f A", pkt->current);
        ESP_LOGI(TAG, "  - Active Pwr : %.2f W", pkt->power);
        ESP_LOGI(TAG, "  - Energy     : %.3f kWh", pkt->energy);
        ESP_LOGI(TAG, "  - Frequency  : %.1f Hz", pkt->frequency);
        ESP_LOGI(TAG, "  - PowerFact  : %.2f", pkt->pf);
        ESP_LOGI(TAG, "  - TinyML AI  : [%s] Score: %d%% (%ld us)", 
                 current_tinyml_res.pattern_name, current_tinyml_res.anomaly_score, (long)current_tinyml_res.inference_us);
        ESP_LOGI(TAG, "=================================================");
    }

}

// ============================================================================
// WEB SERVER & WEB OTA IMPLEMENTATION
// ============================================================================

static const char index_html[] = 
"<!DOCTYPE html><html><head><meta name=\"viewport\" content=\"width=device-width, initial-scale=1\">"
"<title>ESP32-S3 Voice Master Hub</title>"
"<style>"
"body{background:#0f172a;color:#f8fafc;font-family:system-ui,sans-serif;margin:0;padding:20px;}"
".card{background:#1e293b;border-radius:12px;padding:20px;margin-bottom:20px;box-shadow:0 4px 6px -1px rgba(0,0,0,0.5);}"
"h1,h2{color:#38bdf8;margin-top:0;}"
".grid{display:grid;grid-template-columns:repeat(auto-fit,minmax(130px,1fr));gap:15px;}"
".metric{background:#0f172a;border-radius:8px;padding:12px;text-align:center;}"
".val{font-size:22px;font-weight:bold;color:#4ade80;}"
".lbl{font-size:12px;color:#94a3b8;margin-top:4px;}"
".btn{background:#0284c7;color:white;border:none;padding:10px 16px;border-radius:6px;font-weight:bold;cursor:pointer;}"
".btn:hover{background:#0369a1;}"
"</style></head><body>"
"<h1>🎙️ ESP32-S3 Voice Master & Power Hub</h1>"
"<div class=\"card\"><h2>⚡ Live Power Telemetry (from WROOM Slave)</h2>"
"<div class=\"grid\">"
"<div class=\"metric\"><div class=\"val\" id=\"v\">-- V</div><div class=\"lbl\">VOLTAGE</div></div>"
"<div class=\"metric\"><div class=\"val\" id=\"a\">-- A</div><div class=\"lbl\">CURRENT</div></div>"
"<div class=\"metric\"><div class=\"val\" id=\"w\">-- W</div><div class=\"lbl\">POWER</div></div>"
"<div class=\"metric\"><div class=\"val\" id=\"kwh\">-- kWh</div><div class=\"lbl\">ENERGY</div></div>"
"</div></div>"
"<div class=\"card\"><h2>🚀 Web OTA Firmware Update</h2>"
"<form method=\"POST\" action=\"/update\" enctype=\"multipart/form-data\">"
"<input type=\"file\" name=\"update\" accept=\".bin\" style=\"margin-bottom:12px;\"><br>"
"<button type=\"submit\" class=\"btn\">Upload & Flash Firmware (.bin)</button>"
"</form></div>"
"<script>"
"setInterval(async () => {"
"  try {"
"    let r = await fetch('/api/status');"
"    let d = await r.json();"
"    document.getElementById('v').innerText = d.voltage.toFixed(1) + ' V';"
"    document.getElementById('a').innerText = d.current.toFixed(2) + ' A';"
"    document.getElementById('kwh').innerText = d.energy.toFixed(2) + ' kWh';"
"  }catch(e){}"
"}, 1000);"
"</script></body></html>";
static esp_err_t index_get_handler(httpd_req_t *req)
{
    httpd_resp_set_type(req, "text/html");
    return httpd_resp_send(req, index_html, HTTPD_RESP_USE_STRLEN);
}

static void add_cors_headers(httpd_req_t *req)
{
    httpd_resp_set_hdr(req, "Access-Control-Allow-Origin", "*");
    httpd_resp_set_hdr(req, "Access-Control-Allow-Methods", "GET, POST, OPTIONS");
    httpd_resp_set_hdr(req, "Access-Control-Allow-Headers", "Content-Type");
}

static esp_err_t options_handler(httpd_req_t *req)
{
    add_cors_headers(req);
    httpd_resp_send(req, NULL, 0);
    return ESP_OK;
}

static esp_err_t api_status_get_handler(httpd_req_t *req)
{
    add_cors_headers(req);
    char json_resp[384];
    snprintf(json_resp, sizeof(json_resp),
             "{\"voltage\":%.2f,\"current\":%.3f,\"power\":%.2f,\"energy\":%.3f,\"frequency\":%.1f,\"pf\":%.2f,\"today\":0.0,\"yesterday\":0.0,\"month\":0.0,\"lastmonth\":0.0,\"money\":0,\"lastmoney\":0,\"wakenet\":\"Hi ESP\"}",
             live_voltage, live_current, live_power, live_energy, live_freq, live_pf);
    httpd_resp_set_type(req, "application/json");
    return httpd_resp_send(req, json_resp, HTTPD_RESP_USE_STRLEN);
}

static esp_err_t data_get_handler(httpd_req_t *req)
{
    return api_status_get_handler(req);
}
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
void app_main(void)
{
    vTaskDelay(pdMS_TO_TICKS(1000)); // Allow serial monitor to connect
    ESP_LOGI(TAG, "=================================================");
    ESP_LOGI(TAG, "   DTV ENERGY - ESP32-S3 N16R8 VOICE MASTER    ");
    ESP_LOGI(TAG, "=================================================");

    // 0. Initialize Status LEDs (LED1=GPIO48, LED2=GPIO47) & Button Monitor (BUT1=IO1, BUT2=IO3)
    init_status_leds();
    led1_set(true); // LED1 on = power & boot
    xTaskCreate(button_monitor_task, "button_task", 3072, NULL, 3, NULL);

    // 1. Initialize NVS Flash
    esp_err_t ret = nvs_flash_init();

    if (ret == ESP_ERR_NVS_NO_FREE_PAGES || ret == ESP_ERR_NVS_NEW_VERSION_FOUND) {
        ESP_LOGW(TAG, "Erasing NVS flash due to version mismatch...");
        nvs_flash_erase();
        ret = nvs_flash_init();
    }
    if (ret != ESP_OK) {
        ESP_LOGE(TAG, "NVS Flash Init failed: %s", esp_err_to_name(ret));
    }

    // 1b. Initialize Commercial Device Identity (Hardware ID & User ID)
    device_identity_init();

    // 1c. Initialize OTA Subsystem & confirm boot integrity (cancels rollback if pending)
    ota_updater_init();

    // 2. Initialize ESP-NOW Master Protocol & HTTP Web Server with Web OTA
    init_esp_now_master();
    start_web_server();

    // 2b. Start continuous telemetry polling task (5s interval)
    xTaskCreate(telemetry_poll_task, "telemetry_poll", 3072, NULL, 4, NULL);

    // 3. Check & Log Memory Status (Octal PSRAM 8MB)
    size_t internal_free = heap_caps_get_free_size(MALLOC_CAP_INTERNAL);
    size_t psram_free    = heap_caps_get_free_size(MALLOC_CAP_SPIRAM);

    ESP_LOGI(TAG, "Free Internal RAM : %d KB", (int)(internal_free / 1024));
    ESP_LOGI(TAG, "Free Octal PSRAM  : %d KB (%d MB)", (int)(psram_free / 1024), (int)(psram_free / (1024 * 1024)));

    if (psram_free < 1024 * 1024) {
        ESP_LOGW(TAG, "WARNING: Octal PSRAM is less than 1MB or not initialized!");
    }

    // 3. Initialize Audio Hardware
    esp_err_t mic_err = init_i2s_microphone();
    if (mic_err != ESP_OK) {
        ESP_LOGE(TAG, "Microphone Init Failed: %s", esp_err_to_name(mic_err));
    }

    esp_err_t spk_err = init_i2s_speaker();
    if (spk_err != ESP_OK) {
        ESP_LOGW(TAG, "Speaker Init Warning (optional): %s", esp_err_to_name(spk_err));
    } else {
        audio_feedback_init(tx_handle);
        ESP_LOGI(TAG, "=============================================================");
        ESP_LOGI(TAG, "🚀 Playing bootup_sound...");
        ESP_LOGI(TAG, "=============================================================");
        audio_feedback_play(AUDIO_FB_BOOTUP);
    }

    // 4. Configure ESP-SR Audio Front-End (AFE)
    srmodel_list_t *models = esp_srmodel_init("model");
    if (!models || models->num <= 0) {
        ESP_LOGE(TAG, "CRITICAL: Speech recognition models not found or empty in 'model' partition (num=%d)!", models ? models->num : -1);
        ESP_LOGW(TAG, "Please ensure srmodels.bin is flashed to 0x610000. WakeNet temporarily bypassed to allow audio/system to run.");
    } else {
        ESP_LOGI(TAG, "Successfully loaded %d speech recognition models from flash!", models->num);

        afe_config_t afe_config = AFE_CONFIG_DEFAULT();
        afe_config.aec_init = false;  // AEC requires ref_num > 0. Disable for 1-mic setup.
        afe_config.se_init = true;   // Speech enhancement (noise suppression)
        afe_config.vad_init = true;  // Voice activity detection
        afe_config.wakenet_init = true;
        afe_config.wakenet_model_name = "wn9_hiesp";
        afe_config.wakenet_mode = DET_MODE_2CH_90;

        afe_config.afe_mode = SR_MODE_LOW_COST;
        afe_config.memory_alloc_mode = AFE_MEMORY_ALLOC_MORE_PSRAM;
        afe_config.pcm_config.total_ch_num = 1;
        afe_config.pcm_config.mic_num = 1;
        afe_config.pcm_config.ref_num = 0;

        afe_data = afe_handle->create_from_config(&afe_config);

        if (!afe_data) {
            ESP_LOGE(TAG, "CRITICAL ERROR: Failed to create ESP-SR AFE Engine! Check PSRAM!");
        } else {
            ESP_LOGI(TAG, "ESP-SR AFE Engine & WakeNet Pipeline successfully created!");

            // 5. Create Audio Tasks
            xTaskCreatePinnedToCore(audio_feed_task, "audio_feed_task", 8 * 1024, afe_data, 5, NULL, 0);
            xTaskCreatePinnedToCore(audio_detect_task, "audio_detect_task", 8 * 1024, afe_data, 5, NULL, 1);
        }
    }

    // 6. Initialize MQTT Relay Controller (connects to EMQX broker on Pi 4)
    mqtt_relay_init("mqtt://192.168.11.29:1883", "admin", "SmarthomePass2026!");

    // 7. Initialize WebSocket Audio Client (connects to Pi 4 Gateway)
    ws_audio_client_init("ws://192.168.11.29:8765", tx_handle);

    ESP_LOGI(TAG, "=============================================================");
    ESP_LOGI(TAG, "🚀 ESP32-S3 Master Hub Boot Completed!");
    ESP_LOGI(TAG, "=============================================================");
    ESP_LOGI(TAG, "System ready. Say 'Hi ESP' to wake up the system.");
}

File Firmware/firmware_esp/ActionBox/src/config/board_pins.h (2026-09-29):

/**
 * @file board_pins.h
 * @brief Hardware GPIO Pinout & Electrical Configuration for ESP32-S3 ActionBox
 * 
 * Sourced directly from schematic: D:\Downloads\IoT_Board.kicad_sch
 * Architecture: ESP32-S3-WROOM-1 / 16MB Flash
 */

#pragma once

#include "driver/gpio.h"

#ifdef __cplusplus
extern "C" {
#endif

/* ========================================================================= */
/*                          RELAY OUTPUT CONFIGURATION                       */
/* ========================================================================= */

/**
 * @brief Relay Channel Count
 */
#define BOARD_RELAY_CHANNEL_COUNT        2

/**
 * @brief Relay GPIO mapping from IoT_Board.kicad_sch
 * RL1 -> PC817 (U5) -> Relay 1 (K1) -> Connected to ESP32-S3 IO4
 * RL2 -> PC817 (U6) -> Relay 2 (K2) -> Connected to ESP32-S3 IO5
 */
#define BOARD_PIN_RELAY_CH1              GPIO_NUM_4
#define BOARD_PIN_RELAY_CH2              GPIO_NUM_5

/**
 * @brief Relay Driving Technology
 * 0: Monostable standard relay (Continuous HIGH = Closed/ON, LOW = Open/OFF)
 * 1: Magnetic Latching single-coil (H-Bridge or reverse polarity pulse)
 * 2: Magnetic Latching dual-coil (SET pulse pin and RESET pulse pin)
 */
#define BOARD_RELAY_TYPE_MONOSTABLE      0
#define BOARD_RELAY_TYPE_LATCHING_DUAL   1

#define BOARD_RELAY_DRIVE_TYPE           BOARD_RELAY_TYPE_MONOSTABLE

/**
 * @brief Monostable relay logic level (via PC817 optocoupler)
 * 1 = Output HIGH energizes optocoupler LED, switching relay ON
 * 0 = Output LOW de-energizes optocoupler, switching relay OFF
 */
#define BOARD_RELAY_ACTIVE_LEVEL         1

/**
 * @brief Magnetic Latching Pulse Duration in Milliseconds
 * Used when BOARD_RELAY_DRIVE_TYPE == BOARD_RELAY_TYPE_LATCHING_DUAL
 */
#define BOARD_RELAY_LATCH_PULSE_MS       50

/**
 * @brief Placeholders for optional Dual-Coil Latching SET / RESET pins
 * If a latching hardware daughterboard is fitted, define dedicated pins here.
 */
#define BOARD_PIN_RELAY_CH1_SET          GPIO_NUM_4
#define BOARD_PIN_RELAY_CH1_RESET        GPIO_NUM_6   /* Placeholder for Ch1 Reset if dual-coil */
#define BOARD_PIN_RELAY_CH2_SET          GPIO_NUM_5
#define BOARD_PIN_RELAY_CH2_RESET        GPIO_NUM_7   /* Placeholder for Ch2 Reset if dual-coil */


/* ========================================================================= */
/*                         PHYSICAL BUTTON CONFIGURATION                     */
/* ========================================================================= */

/**
 * @brief Button Channel Count
 */
#define BOARD_BUTTON_COUNT               2

/**
 * @brief Physical Push Button GPIOs from schematic
 * BUT1 -> SW_Push -> Connected to ESP32-S3 IO1
 * BUT2 -> SW_Push -> Connected to ESP32-S3 IO3
 */
#define BOARD_PIN_BUTTON_CH1             GPIO_NUM_1
#define BOARD_PIN_BUTTON_CH2             GPIO_NUM_3

/**
 * @brief Button Electrical Level
 * Buttons pull down to GND on press; internal pull-up is enabled in software.
 * 0 = Active LOW (Pressed = 0, Released = 1)
 */
#define BOARD_BUTTON_ACTIVE_LEVEL        0


/* ========================================================================= */
/*                           STATUS LED CONFIGURATION                        */
/* ========================================================================= */

/**
 * @brief Status Indicator LEDs from schematic
 * LED1 -> Resistor -> Connected to ESP32-S3 IO48
 * LED2 -> Resistor -> Connected to ESP32-S3 IO47
 */
#define BOARD_PIN_LED_CH1                GPIO_NUM_48
#define BOARD_PIN_LED_CH2                GPIO_NUM_47

/**
 * @brief LED Active Level
 * 1 = HIGH illuminates LED
 * 0 = LOW illuminates LED
 */
#define BOARD_LED_ACTIVE_LEVEL           1


/* ========================================================================= */
/*                 BL0942 ENERGY MEASUREMENT UART CONFIGURATION              */
/* ========================================================================= */

/**
 * @brief BL0942 Energy Metering IC UART Connections from schematic
 * BL_TX  -> Common TX to BL0942 ICs -> ESP32-S3 IO9
 * BL_RX1 -> Channel 1 BL0942 TX      -> ESP32-S3 IO10
 * BL_RX2 -> Channel 2 BL0942 TX      -> ESP32-S3 IO11
 */
#define BOARD_PIN_BL0942_TX              GPIO_NUM_9
#define BOARD_PIN_BL0942_RX_CH1          GPIO_NUM_10
#define BOARD_PIN_BL0942_RX_CH2          GPIO_NUM_11

/**
 * @brief Hardware UART Peripherals used for BL0942
 * ESP32-S3 UART1 handles Channel 1 (TX=IO9, RX=IO10)
 * ESP32-S3 UART2 handles Channel 2 (TX=IO9 shared / -1, RX=IO11)
 */
#define BOARD_BL0942_UART_NUM_CH1        UART_NUM_1
#define BOARD_BL0942_UART_NUM_CH2        UART_NUM_2
#define BOARD_BL0942_UART_BAUDRATE       4800   /* Default BL0942 UART Baudrate */


/* ========================================================================= */
/*                         SPEAKER HARDWARE SHUTDOWN                         */
/* ========================================================================= */
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

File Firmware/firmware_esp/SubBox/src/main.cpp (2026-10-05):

/**
 * @file main.cpp
 * @brief Production Entry Point for ESP32-S3 SubBox / SubGateway
 *
 * System Role:
 * - Local Brain & Audio Hub of one room
 * - Does NOT directly use a microphone; receives audio streams from ActionBoxes
 * - Selects best active speech signal among up to 4 ActionBoxes in room
 * - Relays microphone PCM to Pi4, which owns ASR and voice command extraction
 * - Executes explicit gateway commands over ESP-NOW; no local voice fallback
 * - Routes audio responses / TTS back to originating ActionBox speaker
 */

#include <stdio.h>
#include <string.h>
#include <memory>

#include "freertos/FreeRTOS.h"
#include "freertos/task.h"
#include "esp_system.h"
#include "esp_chip_info.h"
#include "esp_flash.h"
#include "esp_log.h"
#include "esp_wifi.h"
#include "esp_event.h"
#include "esp_sntp.h"
#include "esp_netif.h"
#include "esp_heap_caps.h"

#include "config/subbox_config.h"
#include "config/board_pins.h"
#include "storage/nvs_manager.h"
#include "room/room_manager.h"
#include "audio/audio_transport/udp_audio_transport.h"
#include "audio/audio_transport/espnow_audio_transport.h"
#include "audio/audio_buffer/audio_ring_buffer.h"
#include "audio/vad/energy_vad.h"
#include "audio/asr/ws_asr.h"
#include "audio/audio_manager/audio_manager.h"
#include "audio/audio_output/audio_output_router.h"
#include "audio/audio_output/sound_player.h"
#include "tts/tts_manager.h"
#include "nlu/context/context_manager.h"
#include "actionbox/registry/actionbox_registry.h"
#include "actionbox/router/command_router.h"
#include "rules/rule_engine.h"
#include "mqtt/subbox_mqtt_client.h"
#include "system/task_manager.h"
#include "system/dev_console.h"

static const char *TAG = "SUBBOX_MAIN";

#include "system/wifi_provisioning.h"
#include "system/subbox_led.h"

static int s_wifi_retry_count = 0;

static void wifi_event_handler(void* arg, esp_event_base_t event_base,
                               int32_t event_id, void* event_data) {
    if (event_base == WIFI_EVENT && event_id == WIFI_EVENT_STA_START) {
        ESP_LOGI(TAG, "Wi-Fi Station started, connecting to AP '%s'...", (const char*)arg);
        if (((const char*)arg)[0]) esp_wifi_connect();
    } else if (event_base == WIFI_EVENT && event_id == WIFI_EVENT_STA_DISCONNECTED) {
        subbox_led_set_wifi_connected(false);
        subbox_led_set_mqtt_connected(false);
        s_wifi_retry_count++;
        ESP_LOGW(TAG, "Wi-Fi disconnected (attempt %d/5)...", s_wifi_retry_count);
        if (s_wifi_retry_count >= 5 && !wifi_provisioning_is_active()) {
            ESP_LOGW(TAG, "⚠️ Wi-Fi unreachable after 5 attempts -> Launching SoftAP Captive Portal!");
            wifi_provisioning_start();
        }
        esp_wifi_connect();
    } else if (event_base == IP_EVENT && event_id == IP_EVENT_STA_GOT_IP) {
        s_wifi_retry_count = 0;
        ip_event_got_ip_t* event = (ip_event_got_ip_t*)event_data;
        ESP_LOGI(TAG, "✅ SubBox Wi-Fi Connected! IP: " IPSTR, IP2STR(&event->ip_info.ip));
        subbox_led_set_wifi_connected(true);
        if (!esp_sntp_enabled()) {
            esp_sntp_setoperatingmode(SNTP_OPMODE_POLL);
            esp_sntp_setservername(0, "pool.ntp.org");
            esp_sntp_init();
        }
    }
}

static void print_banner(const SubBoxPersistentConfig& cfg) {
    esp_chip_info_t chip_info;
    esp_chip_info(&chip_info);

    uint32_t flash_size = 0;
    esp_flash_get_size(NULL, &flash_size);

    size_t free_sram  = heap_caps_get_free_size(MALLOC_CAP_INTERNAL) / 1024;
    size_t free_psram = heap_caps_get_free_size(MALLOC_CAP_SPIRAM) / 1024;

    ESP_LOGI(TAG, "===============================================================");
    ESP_LOGI(TAG, "  AETHERIA OS — SUBBOX / SUBGATEWAY LOCAL BRAIN (ESP32-S3)");
    ESP_LOGI(TAG, "===============================================================");
    ESP_LOGI(TAG, "  Firmware Name    : %s", SUBBOX_FW_NAME);
    ESP_LOGI(TAG, "  Firmware Version : %s", SUBBOX_FW_VERSION_STR);
    ESP_LOGI(TAG, "  Silicon Model    : ESP32-S3 (Rev %d, %d Cores)", chip_info.revision, chip_info.cores);
    ESP_LOGI(TAG, "  Flash Size       : %lu MB", (unsigned long)(flash_size / (1024 * 1024)));
    ESP_LOGI(TAG, "  PSRAM Available  : %u KB (Total: 16 MB Octal)", (unsigned)free_psram);
    ESP_LOGI(TAG, "  Internal SRAM    : %u KB", (unsigned)free_sram);
    ESP_LOGI(TAG, "  SubBox ID        : %s", cfg.subbox_id);
    ESP_LOGI(TAG, "  Assigned Room    : %s (%s)", cfg.room_name, roomToString(cfg.room_type));
    ESP_LOGI(TAG, "  Real ASR Engine  : Pi 4 Sherpa-ONNX Zipformer (ws://192.168.11.29:8765)");
    ESP_LOGI(TAG, "  Audio Capacity   : Up to %d ActionBoxes per Room",
             SUBBOX_MAX_ACTIONBOXES_PER_ROOM);
    ESP_LOGI(TAG, "===============================================================");
}
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

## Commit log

2026-07-24 tuan's first commit
    [IOT_Project.kicad_pcb, IOT_Project.kicad_sch]
2026-07-24 Project Codebase Refactor
    [IOT_Project.kicad_pcb, IOT_Project.kicad_sch, partitions_16mb.csv]
2026-07-24 add flutter lol
    [partitions_16mb.csv]
2026-07-24 feat: quy luồng kết nối về 1 mối, thêm Google Assistant & nạp OTA tự động cho App Android
    - Firmware ESP32-S3: Nâng cấp quét đa kênh Wi-Fi XIAOMI, đồng bộ gói tin ESP-NOW với WROOM Slave & nháy LED RGB nháy báo dữ liệu.
    - Firmware ESP32 WROOM: Đóng gói thành công file binary OTA wroom_slave_firmware.bin.
    - Rust Core Server: Thống nhất Gateway API (/api/status, /api/alerts, /api/weather, /api/analytics), tích hợp Google Assistant Webhook (/api/google-assistant) & tạo endpoint tự động nạp App OTA (/api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
    - Web Dashboard: Cập nhật giao diện Liquid Glass đồng bộ dữ liệu real-time qua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
2026-07-24 fix: bump app version to 1.0.1 and implement hybrid Raw Binary / Multipart POST for ESP32 hardware OTA
2026-07-24 feat: migrate system to standalone ESP32-S3 Server Architecture (IP: 192.168.11.181) with REST API, CORS & Google Assistant Webhook
2026-07-24 fix: resolve APK download URL from app-version response and handle fallback for standalone ESP32-S3 Server mode
2026-07-24 feat: integrate TinyML On-Device AI Anomaly & Load Pattern Classifier into ESP32-S3 Master and Flutter v1.0.6 UI
2026-07-24 feat: serve version 1.0.6 app OTA from ESP32-S3 Master server
2026-07-24 feat: redesign UI with Echo Nightly glassmorphism style and add Push Notifications v1.0.7
    [main.c]
2026-08-13 push pcb
    [ESP32D.kicad_sch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]
2026-08-20 done sche
    [IoT_Board.kicad_sch]
2026-08-29 done PCB
    [IoT_Board.kicad_pcb, IoT_Board.kicad_sch]
2026-09-03 add gerber OK
    [IoT_Board-B_Cu.gbr, IoT_Board-B_Mask.gbr, IoT_Board-B_Paste.gbr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]
2026-09-09 feat: Add Smart Home Gateway (Sherpa-ONNX, Qwen LLM, EdgeTTS, Closed-Loop Verifier), Master Plan & update PCB design
    [IoT_Board-B_Cu.gbr, IoT_Board-B_Mask.gbr, IoT_Board-B_Paste.gbr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]
2026-09-16 fix(firmware): Allocate stream buffers in PSRAM and optimize boot sequence to prevent out-of-memory crash
    [main.c]
2026-09-16 fix(audio): Mute MAX98357A via SP_SD on idle, flush I2S DMA, and keep AFE pipeline active during playback
    [main.c]
2026-09-16 feat(voice): Register bedroom node with RL1 light and RL2 fan, and add audio feedback chimes
2026-09-17 fix(audio,relay): fix websocket disconnect, buffer overrun, speaker mutex, active-low relay, and verification
2026-09-17 webui, sign device
2026-09-17 fix(registry): escape quotes in GBNF grammar for device and room string values
2026-09-17 feat(benchmark): add comprehensive 64-case NLU benchmark suite for Qwen2.5-3B
2026-09-17 feat: multi-turn slot dialog, spatial audio arbiter, and continuous listening
2026-09-17 add apk, fix sound bugs
    [main.c]
2026-09-20 fix nhieu bug
    [IoT_Board.kicad_pcb, IoT_Board.kicad_sch]
2026-09-29 feat(system): phase 1-4 hardening, protocol v3, sqlite-only registry, radio recovery and fallback ASR
    [partitions.csv, partitions_16mb.csv, partitions_t1.csv]
2026-10-01 push 1.10
    [IoT_Board.kicad_pcb, IoT_Board.kicad_sch]
2026-10-03 refactor: update gateway client services, flutter UI screens, and esp32 firmware configs
2026-10-04 refactor: update SubBox audio manager and WebSocket ASR for audio relay support
2026-10-04 feat: add I2S sound player driver and integrate acoustic feedback for TTS responses
2026-10-05 add pcb.step
    [IoT_Board.kicad_sch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]
2026-10-08 feat(web): thêm tab Cấu Hình Mạng WiFi vào dashboard
    - Thêm nav item '📶 Cấu Hình Mạng' vào sidebar
    - Thêm giao diện quét WiFi, nhập SSID/password, kết nối
    - Hiển thị trạng thái mạng hiện tại
    - Sử dụng các API đã có: /api/wifi/scan, /api/wifi/connect, /api/wifi/status
2026-10-08 fix(web): cho phép cấu hình wifi không cần auth và sửa lỗi same-origin check
2026-10-08 feat(ui): thiết kế lại toàn bộ giao diện Web SIC Home đồng bộ với App Android
2026-10-08 feat(ui): thêm guest banner và nút điền nhanh đăng nhập admin
2026-10-18 feat: implement commercial readiness optimizations, security hardening, and code cleanup
    - Strip all inline/block comments across Python, C/C++, Dart, Kotlin, CMake, Shell, and SQL code
    - Phase A & E: WebSocket authentication, anti-spoofing, ESP-NOW MAC peer verification, Wi-Fi API locking, Mosquitto TLS, context-aware Secure cookie, and dead code removal
    - Phase B: Honest relay feedback & optimistic rollback, voice dual-mode confirmation, BL0942 channel/power load verification, full 3-relay support, scene execution feedback, and per-channel telemetry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
    - Phase C & D: Secure OTA target routing with one-time tickets, firmware magic byte validation, Android release signing confi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
2026-10-23 feat: complete device lifecycle and stabilize voice follow-up
    Track registration, reset, Android lifecycle services and regression tests. Resolve voice targets from registered names, preserve clarification choices, support scoped multi-device answers, and bound retries. Serialize SubBox audio transport and reopen the selected ActionBox microphone after prompts.
    Validation: Gateway 289 passed / 7 skipped; firmware host 20 passed; Flutter 126 passed. User confirmed follow-up listening and the repeated-question fix on hardware. Keep local credentials, generated certificates and rollback artifacts out of Git.
2026-10-24 fix(ActionBox): apply stored calibration coefficients on startup
    bl0942_driver_init() always resets s_calibrations[] to defaults.
    The saved NVS calibration was never fed back into the driver after
    boot, so custom calibration was silently lost on every power cycle.
    Add the same set_calibration loop that ActionBox_V2 already has.
2026-10-27 OTA, app, firebase, not kws and relay fix
2026-10-28 Integrate Firebase channel control, SubBox KWS and relay feedback; archive legacy sources
2026-10-29 chore(hardware): track IoT_Board 3D step model
2026-10-29 Revert "chore(hardware): track IoT_Board 3D step model"
    This reverts commit f04ef28af9f93f579b570b2b862a3a117047b30d.
2026-10-29 docs: record Pi network recovery and Firebase device status
